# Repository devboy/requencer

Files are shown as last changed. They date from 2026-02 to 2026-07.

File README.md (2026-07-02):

# Requencer

A 4-track eurorack step sequencer built around **polymetric randomization** —
each track has independent gate, pitch, velocity and mod subtracks with their
own lengths and clock dividers, and a randomizer that regenerates a whole
track or a single layer at the press of a button. It replaces a live
setup of four sequencers plus utility modules with one hands-on module.

**[▶ Try it live](https://devboy.github.io/requencer/)** — the browser
preview is the real faceplate layout; everything works with mouse or touch.
See the **[manual](docs/manual.md)** for how to play it.

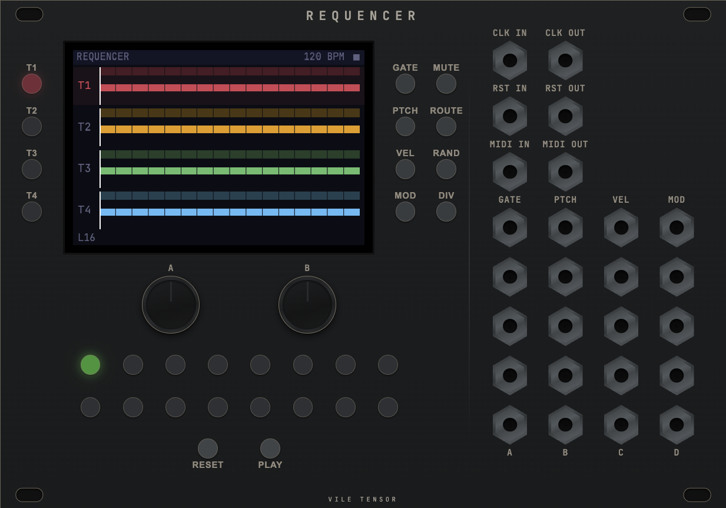
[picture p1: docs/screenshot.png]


## ⚡ Help wanted: hardware design review

The firmware, engine, and web preview are working and tested — but I'm a
software developer, not a hardware engineer, and this design is about to go
to manufacturing. **I'd be grateful for experienced eyes on the electronics
before I order boards.**

The module is a three-board stack behind a eurorack faceplate:

- **Control board** — buttons, encoders, jacks, LED drivers, shift
  registers, USB-C, SD card, MIDI in.
- **Main board** — RP2350 (PGA2350), DAC8568 CV outputs with op-amp output
  stages (1V/oct), eurorack power entry and regulators.
- Board-to-board via 2×16 shrouded headers.

**Review materials:**

- 📄 **Schematic review PDFs** (one page per subcircuit, net-label style) and
  the full **KiCad projects, gerbers, and STEP files** are attached to the
  latest [GitHub Release](https://github.com/devboy/requencer/releases).
- The design source is [atopile](https://atopile.io/) (`hardware/boards/elec/src/`),
  compiled to KiCad — the PDFs and KiCad files are what you want to look at
  if you don't read `.ato`.

Particularly unsure about: power entry & regulation, the DAC output stage
(1V/oct scaling/offset accuracy), the board-to-board pinout, and the USB-C /
SD / MIDI input circuits. Issues and PRs welcome.

## Features

- 4 tracks × 4 subtracks (gate / pitch / velocity / mod), each with
  independent step length (1–64) and clock divider — polymetric by default.
- Randomizer with per-track scale, root, range, density and velocity config;
  four gate algorithms (RAND / EUCL / SYNC / CLST); 8 factory presets plus
  user presets.
- Drift (per-subtrack stochastic mutation) and per-track transpose with
  scale quantization.
- Free output routing: any subtrack to any of the 4 output jacks.
- Internal, MIDI, or external clock; per-output MIDI channels.

Full documentation: **[docs/manual.md](docs/manual.md)** (also built into
the web app — the MANUAL button).

## Architecture

| Part | What it is |
|---|---|
| `crates/engine` | `no_std` pure Rust sequencer logic (runs in WASM and on the RP2350) |
| `crates/renderer` | `no_std` display rendering via embedded-graphics |
| `crates/web` | WASM bindings + Canvas2D target for the browser |
| `crates/firmware` | RP2350 firmware: SPI display, DACs, buttons/encoders |
| `web/` | TypeScript preview: Tone.js audio, Web MIDI, canvas faceplate UI |
| `hardware/` | atopile PCB projects (control + main + faceplate) and the build pipeline |

## Development

```bash
make dev      # Vite dev server (builds WASM first)
make test     # All tests: Rust + web + hardware scripts
make rust     # Test + lint + build firmware
make web      # Test + lint + build web bundle
make hardware # Full hardware pipeline (KiCad + FreeRouting required)
```

## License

- Code: [MIT](LICENSE)
- Hardware design (`hardware/`): [CERN-OHL-S v2](hardware/LICENSE) —
  strongly reciprocal open hardware licence.

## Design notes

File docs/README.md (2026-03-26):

# Requencer Docs

Design documents and research notes for Requencer development.

## Plans (Active)

- **[feature-roadmap.md](plans/2026-03-01-feature-roadmap.md)** — Feature tiers (all complete) + future/unscheduled items
- **[quality-audit.md](plans/2026-03-03-quality-audit.md)** — Performance baselines, coverage stats, refactoring opportunities
- **[firmware-implementation.md](plans/2026-03-06-firmware-implementation.md)** — RP2350 firmware roadmap (active development)
- **[persistence.md](plans/2026-03-06-persistence.md)** — Postcard serialization plan (web done, firmware SD card pending)
- **[rp2350-memory-constraints.md](plans/2026-03-06-rp2350-memory-constraints.md)** — Memory budget analysis for RP2350
- **[hardware-pipeline-remaining-todos.md](plans/2026-03-07-hardware-pipeline-remaining-todos.md)** — Pipeline status & known issues
- **[main-board-resize.md](plans/2026-03-12-main-board-resize.md)** — Shrink main board (partially implemented)
- **[parallel-placement-optimization.md](plans/2026-03-13-parallel-placement-optimization.md)** — 5-strategy parallel placement architecture
- **[pcb-stacking-restructure.md](plans/pcb-stacking-restructure.md)** — Three-board sandwich architecture (implemented)
- **[rust-engine-remaining-todos.md](plans/rust-engine-remaining-todos.md)** — Storage, cross-validation, firmware integration

## Superpowers Plans & Specs (Active)

- **[placement-strategy-refactor](superpowers/plans/2026-03-15-placement-strategy-refactor.md)** — BoardState toolkit architecture (implemented)
- **[wavefront-placement-design](superpowers/specs/2026-03-17-wavefront-placement-design.md)** — BFS wave placement strategy (implemented)
- **[display-replacement-design](superpowers/specs/2026-03-16-display-replacement-design.md)** — ST7796 32-pin FPC migration (implemented)
- **[placement-strategy-refactor-design](superpowers/specs/2026-03-15-placement-strategy-refactor-design.md)** — Config-driven placement design (implemented)

## Research (Active)

**Hardware reference:**
- [mechanical-standards](research/eurorack-mechanical-standards.md), [pcb-best-practices](research/eurorack-pcb-best-practices.md) — Eurorack specs
- [continuous-cv-outputs](research/continuous-cv-outputs.md) — CV output design for firmware
- [pcb-stacking](research/pcb-stacking.md) — Three-board sandwich depth budget & connectors
- [component-mounting-depths](research/component-mounting-depths.md) — Physical depth specs for panel-mounted parts
- [faceplate-connectors](research/faceplate-connectors.md) — USB-C & MicroSD front-panel placement
- [thermal-placement-analysis](research/thermal-placement-analysis.md) — Power dissipation & thermal gradients

**Design reference:**
- [sequencer-comparison](research/sequencer-comparison.md) — Competitor analysis
- [feature-ideas](research/feature-ideas.md) — Feature brainstorm with implementation status
- [3d-assembly-viewer](research/3d-assembly-viewer.md) — Three.js exploded view (planned)
- [3d-preview-rendering](research/3d-preview-rendering.md) — Studio-quality 3D rendering (aspirational)

**Audits:**
- [schematic-review-2026-03-16](research/schematic-review-2026-03-16.md) — Pre-production audit (all fixes applied)
- [pcb-placement-review](research/pcb-placement-review.md) — Component placement audit

**Sourcing:**
- [aliexpress-parts-sourcing](research/aliexpress-parts-sourcing.md) — THT parts sourcing (all ordered)
- [github-actions-autoroute-timeout](research/2026-03-07-github-actions-autoroute-timeout.md) — FreeRouting CI workarounds

## Archive

Completed feature plans, superseded research, and historical design decisions. See [`archive/`](archive/) directory.

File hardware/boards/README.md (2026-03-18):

# Requencer Hardware — Design Wiki

Multi-board eurorack sequencer module. Three-board sandwich stack: **faceplate** (front panel PCB) + **control board** (user-facing THT components) + **main board** (MCU, DACs, power).

## System Block Diagram

```
                    FACEPLATE (front panel PCB)
                    ┌─────────────────────────────────────┐
                    │  Display cutout    26× jack holes   │
                    │  36× button holes  2× encoder holes │
                    └──────────────┬──────────────────────┘
                                   │ mechanical mounting
                    CONTROL BOARD (user-facing THT)
                    ┌──────────────┴──────────────────────┐
                    │  FPC connector ──── ST7796 display   │
                    │  36× PB6149L buttons                 │
                    │  2× EC11E encoders                   │
                    │  26× WQP518MA jacks                  │
                    │  2× PJ366ST MIDI jacks               │
                    │  SD card (PJS008U)                    │
                    │  3× IS31FL3216A LED drivers (I2C)    │
                    │  5× 74HC165D shift registers         │
                    │  H11L1S MIDI optocoupler             │
                    └──────────────┬──────────────────────┘
                      2× ShroudedHeader2x16 (64 pins)
                    ┌──────────────┴──────────────────────┐
                    │  PGA2350 MCU (RP2350B, 48 GPIO)     │
                    │  2× DAC80508 (16-bit, 8-ch each)    │
                    │  5× OPA4171A quad op-amps            │
                    │  AMS1117-3.3 LDO                     │
                    │  USB-C (edge-mount)                   │
                    │  Eurorack power header               │
                    └─────────────────────────────────────┘
                    MAIN BOARD (MCU + analog + power)
```

## Documentation Index

### [Parts Catalog](elec/src/components/)

29 active components + [archived parts](elec/src/components/_archive/). Each part has a README with specs, sourcing info, and design rationale.

### Circuit Modules

Design documentation for each circuit block, including component value rationale and signal interfaces.

| Circuit | Board | Description |
|---|---|---|
| [dac-output](elec/src/circuits/dac-output/) | Main | 2× DAC80508 → 5× OPA4171A → 16 buffered CV/gate outputs |
| [power](elec/src/circuits/power/) | Main | Eurorack ±12V → +5V/+3.3V supply with protection |
| [mcu](elec/src/circuits/mcu/) | Main | PGA2350 (RP2350B) with SPI, I2C, GPIO routing |
| [input-protection](elec/src/circuits/input-protection/) | Main | Voltage divider + Schottky clamp for CV/clock inputs |
| [board-connector](elec/src/circuits/board-connector/) | Both | 2× 2×16 shrouded headers bridging control ↔ main |
| [led-driver](elec/src/circuits/led-driver/) | Control | 3× IS31FL3216A I2C constant-current LED drivers |
| [button-scan](elec/src/circuits/button-scan/) | Control | 5× 74HC165D shift register chain (34 buttons) |
| [midi](elec/src/circuits/midi/) | Control | TRS Type A MIDI IN/OUT (H11L1S optocoupler) |
| [io-jacks](elec/src/circuits/io-jacks/) | Control | 26× WQP518MA mono jacks |
| [display](elec/src/circuits/display/) | Control | ST7796 3.5" SPI TFT (32-pin FPC) — docs only |

### Board Top-Level Modules

| Board | Description |
|---|---|
| [Control](elec/src/boards/control/) | User-facing board: buttons, LEDs, encoders, jacks, display, SD, MIDI |
| [Main](elec/src/boards/main/) | Processing board: MCU, DACs, op-amps, power supply, USB-C |

### Source Structure

See [elec/src/README.md](elec/src/) for the circuit dependency graph and import structure.

## Build System

The hardware pipeline is managed by `Makefile` targets:

| Target | Action |
|---|---|
| `make hw-build` | Full pipeline: place → route → ground pours → faceplate → 3D → export |
| `make hw-place` | Component placement + export panel layout |
| `make hw-route` | FreeRouting autorouter |
| `make hw-3d` | 3D model generation + STEP/GLB export |
| `make hw-clean` | Remove build artifacts |

## Layout Source of Truth

KiCad PCB files are the layout authority. The web preview reads from:
- `scripts/placement/export_layout.py` → `web/src/panel-layout.json` (positions from PCB)
- `component-map.json` (UI metadata: dimensions, categories)

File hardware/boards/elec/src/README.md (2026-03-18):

# Requencer — Circuit Source

Atopile hardware description files organized into circuits, boards, and auto-generated validation.

## Directory Structure

```
elec/src/
├── system.ato              ← Auto-generated validation build (DO NOT EDIT)
├── parts/                  ← Auto-generated passives (Resistor, Capacitor instances)
├── components/             ← Custom part definitions (symbols, footprints, 3D models, docs)
├── circuits/               ← Reusable circuit modules
│   ├── board-connector/    ← 2×16 header interface between boards
│   ├── button-scan/        ← 5× 74HC165D shift register chain
│   ├── dac-output/         ← 2× DAC80508 + 5× OPA4171A output stage
│   ├── display/            ← ST7796 display documentation (no physical parts)
│   ├── input-protection/   ← Voltage divider + Schottky clamp
│   ├── io-jacks/           ← 26× WQP518MA mono jacks
│   ├── led-driver/         ← 3× IS31FL3216A I2C LED drivers
│   ├── mcu/                ← PGA2350 MCU block
│   ├── midi/               ← TRS Type A MIDI IN/OUT
│   └── power/              ← Eurorack power supply
└── boards/                 ← Top-level board modules
    ├── control/            ← Control board (user-facing THT)
    └── main/               ← Main board (MCU + analog + power)
```

## Dependency Graph

```
system.ato
├── boards/control/control.ato
│   ├── circuits/board-connector/  (BoardConnectorSocket)
│   ├── circuits/button-scan/      (ButtonScanner)
│   ├── circuits/led-driver/       (LEDDriverChain)
│   ├── circuits/io-jacks/         (IOJacks)
│   ├── circuits/midi/             (MIDIInterface)
│   └── parts: EC11E, B5819W, FPC_32P_05MM, PJS008U, 2N7002
│
└── boards/main/main.ato
    ├── circuits/board-connector/  (BoardConnectorInterface)
    ├── circuits/power/            (PowerSupply)
    ├── circuits/mcu/              (PGA2350_MCU)
    ├── circuits/dac-output/       (DACOutputStage)
    ├── circuits/input-protection/ (InputProtection)
    └── parts: 2N3904, PRTR5V0U2X, USB_C_Receptacle
```

## Build Entries

Defined in [`ato.yaml`](../../ato.yaml):

| Build | Entry Point | Purpose |
|---|---|---|
| `control` | `boards/control/control.ato:Control` | Control board netlist |
| `main` | `boards/main/main.ato:Main` | Main board netlist |
| `system` | `system.ato:System` | Cross-board validation (auto-generated) |

## Conventions

- **Import paths** are relative to each `.ato` file's location
- Parts imports use `../../components/<Part>/<Part>.ato` (from circuit/board dirs)
- Cross-module imports use `../../circuits/<name>/<name>.ato` (from board dirs)
- `system.ato` is regenerated by `scripts/build/gen_validation.py` — never edit manually
- `parts/` subdirectory contains auto-generated passive components (Resistor, Capacitor)

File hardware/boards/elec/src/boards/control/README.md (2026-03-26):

# Control Board

**Source:** [`control.ato`](./control.ato)
**Board:** Control (top board in the sandwich stack, user-facing)

## Purpose

The control board holds all user-facing components: 36 illuminated buttons (16 step + 4 track + 4 left-function + 4 subtrack + 4 right-function + 4 transport), 24 mono jacks, 2 rotary encoders, a 3.5" TFT display, a MicroSD card slot, and MIDI I/O jacks. It has no MCU or analog processing -- all intelligence lives on the main board. Every signal routes through two 2x16 board-to-board connectors (female sockets mating with male headers on the main board).

## Sub-Module Interconnection

```
                    Board Connector (2x16 socket, Header A + Header B)
                         |
         +---------------+------------------+------------------+
         |               |                  |                  |
    ButtonScanner    LEDDriverChain      IOJacks          MIDIInterface
    (74HC165 x5)    (IS31FL3216A x3)   (WQP518MA x24)    (TRS jacks)
         |               |
    36x PB6149L     LED cathode wiring
    (LED buttons)   (22 of 36 buttons have
                    LEDs, grouped by physical
                    location on PCB)

    Encoder A (EC11E)    Encoder B (EC11E)
         |                    |
    direct to connector  direct to connector

    FPC Connector ──── Display (ST7796 3.5" TFT)
    PJS008U ────────── MicroSD card slot
```

## Power Distribution

All power comes from the main board through the board connector. No regulators or power generation on this board.

| Rail | Source | Consumers | Decoupling |
|---|---|---|---|
| +3.3V | Main board AMS1117 regulator | Shift registers (ButtonScanner VCC), MIDI interface, LCD VDDA/VDDI, SD card VCC, IM pull-ups, reset RC | Per-consumer bypass caps |
| +5V | Eurorack bus via main board | LED driver anodes (led_vcc), LCD backlight (via 82 ohm) | 10uF bulk + 100nF HF near LED drivers |
| +12V / -12V | Eurorack bus via main board | Passed through connector but not directly consumed on control board | - |

## Physical Layout Notes

### THT Placement Constraints

All user-facing components are through-hole (THT), which constrains placement to a grid and requires clearance for:
- **WQP518MA jacks:** 9mm diameter body, need ~2mm clearance between adjacent jacks
- **PB6149L buttons:** 6.5mm square body with integral LED
- **EC11E encoders:** 12mm diameter body with 6mm shaft
- **FPC connector:** Bottom-mount, ribbon exits toward display cutout in faceplate
- **PJS008U MicroSD:** Vertical mount, protrudes ~2.6mm above panel surface through faceplate slot

### Component Grouping

Components are physically grouped for shortest trace routing:

- **LED driver A** (left side): drives step1-4, step9-12, t1-t4 (12 LEDs nearest to it)
- **LED driver B** (center): drives step5-8, step13-16, clr (9 LEDs)
- **LED driver C** (right): drives play (1 LED, 15 channels spare for future expansion)

### CV Input Filtering

100nF HF filter caps are placed on the control board side of each CV input (cv_a through cv_d) at the connector. These reduce crosstalk from adjacent digital signals on the board-to-board connector before the signals reach the main board's input protection circuits.

## Circuits on This Board

| Circuit | Instance | Role |
|---|---|---|
| `BoardConnectorSocket` | `connector` | Female 2x16 sockets (mates with main board headers) |
| `ButtonScanner` | `buttons` | 5x 74HC165 shift registers + 36x PB6149L illuminated buttons |
| `LEDDriverChain` | `leds` | 3x IS31FL3216A I2C LED drivers (16 channels each) |
| `IOJacks` | `jacks` | 24x WQP518MA mono jacks (pure breakout, no conditioning) |
| `MIDIInterface` | `midi` | MIDI IN/OUT/THRU TRS jacks with optocoupler |
| `EC11E` | `enc_a`, `enc_b` | Rotary encoders with push switch |
| `FPC_32P_05MM` | `lcd_fpc` | 32-pin FPC connector for display |
| `PJS008U` | `sd` | Vertical MicroSD card slot |
| Backlight driver | inline | 2N7002 MOSFET + gate resistors for LCD backlight PWM |
| LCD reset RC | inline | 10k + 100nF power-on reset circuit |
| LCD IM pull-ups | inline | 3x 10k pull-ups for 4-wire SPI mode |

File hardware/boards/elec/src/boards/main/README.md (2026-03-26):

# Main Board

**Source:** [`main.ato`](./main.ato)
**Board:** Main (bottom board in the sandwich stack)

## Purpose

The main board contains all processing and analog circuitry: the PGA2350 MCU, two DAC80508 16-bit DACs with op-amp output stages, input protection for 6 eurorack inputs, clock/reset output buffers, the power supply, and a USB-C port for firmware programming. It connects to the control board (which has all user-facing components) via two 2x16 shrouded headers.

## Analog Signal Chain

### DAC Outputs (16 channels)

```
MCU SPI1 (GP30/31) ──> DAC80508 x2 ──> OPA4171A op-amps x4 ──> 470ohm protection ──> Connector ──> Jacks
```

Four different output topologies serve different eurorack signal types:

| Output Type | Channels | Op-amp Config | Range | Resistor Values |
|---|---|---|---|---|
| Gate | 1-4 | Unity buffer (follower) | 0 to +5V | - |
| Pitch | 1-4 | Non-inv, gain=2, offset=-2V | -2V to +8V | Rf=Rg=10k (0.1%) |
| Velocity | 1-4 | Non-inv, gain=1.604 | 0 to +8V | Rf=6.04k, Rg=10k |
| Mod | 1-4 | Inverting, gain=-2, offset=+5V | +5V to -5V | Rin=10k, Rf=20k |

Pitch channels use 0.1% resistors for accurate 1V/oct tracking. Pitch feedback taps after the 470 ohm protection resistor so the op-amp compensates for voltage drop under load.

A 5th OPA4171A quad provides buffered reference voltages:
- **2V reference** (for pitch offset): 15k/10k divider from filtered 5V, buffered by ch1
- **1.667V reference** (for mod offset): 20k/10k divider from filtered 5V, buffered by ch2
- Ch3-4: spare, tied as GND followers to prevent oscillation

### DAC Power Filtering

The 5V rail is shared with LED drivers on the control board. A 10 ohm + 10uF RC filter (f_3dB ~1.6 kHz) isolates the DAC AVDD supply from LED PWM switching transients. Voltage drop at DAC quiescent current (~12mA) is only 0.12V.

### Input Protection (6 channels)

```
Jack (control board) ──> Connector ──> InputProtection (22k/10k divider + BAT54S clamp + filter cap) ──> MCU ADC
```

- CV inputs (4x): 100nF filter cap (f_3dB ~159 Hz)
- Clock/Reset inputs (2x): 10nF filter cap (f_3dB ~1.6 kHz) for fast edge response

### Clock/Reset Output Buffers (2 channels)

```
MCU GPIO ──> 1k base resistor ──> 2N3904 NPN (common-emitter) ──> 1k collector pull-up to 5V ──> Connector ──> Jack
```

These are inverting buffers. GPIO HIGH turns the transistor ON, pulling the output LOW. Firmware must drive the GPIO inverted relative to the desired output polarity.

## Power Distribution

```
Eurorack 16-pin header
  +12V ──> B5819W Schottky ──> v12p rail ──> Op-amp V+ / Connector
  -12V ──> B5819W Schottky ──> v12n rail ──> Op-amp V- / Connector
  +5V  ──> B5819W Schottky ──> v5v rail ──> AMS1117 / DAC AVDD / LED drivers (via connector) / MCU VB (via Schottky)
                                    |
                               AMS1117-3.3
                                    |
                               v3v3 rail ──> DAC VIO / Connector (LCD, shift regs, MIDI, etc.)
```

The AMS1117-3.3 LDO is fed from +5V (not +12V) to minimize power dissipation: (5-3.3) x 0.1A = 0.17W vs (12-3.3) x 0.1A = 0.87W from 12V.

All three eurorack rails have B5819W Schottky diodes for reverse polarity protection.

| Rail | Decoupling |
|---|---|
| +12V | 10uF bulk + 100nF HF per op-amp (x5) + 10uF shared bulk |
| -12V | 10uF bulk + 100nF HF per op-amp (x5) + 10uF shared bulk |
| +5V | 10uF bulk + 100nF HF (power supply) + 10uF + 22uF (AMS1117 in/out) |
| +3.3V | 22uF + 100nF (AMS1117 output) + 100nF per VIO (x2 DACs) |
| MCU VB | 10uF + 100nF (in mcu.ato) |
| MCU 3V3 | 10uF + 100nF (in mcu.ato) |
| DAC AVDD | 10uF + 100nF per DAC (on filtered rail) |

## USB-C Integration

USB-C is edge-mounted on the main board, accessible from the rack side. It is data-only (no VBUS power draw).

| Component | Value | Purpose |
|---|---|---|
| USB_C_Receptacle | - | Physical connector |
| Series resistors | 27 ohm x2 | Signal integrity on DP/DM (near MCU) |
| PRTR5V0U2X | - | ESD protection on data lines (at connector) |
| CC pull-downs | 5.1k x2 (1%) | Required by USB-C spec for device mode |

VBUS is intentionally left unconnected (not tied to GND, which would short the host's supply).

## Encoder Signal Conditioning

Encoder pull-ups and debounce caps are placed on the main board (near MCU) rather than the control board to free control board space:
- 10k pull-ups to 3.3V on all 6 encoder signals (A/B/SW for both encoders)
- 10nF debounce caps (tau = 10k x 10nF = 0.1ms) for RF filtering; real debounce is handled by the RP2350 PIO gray-code state machine

## Circuits on This Board

| Circuit | Instance | Role |
|---|---|---|
| `BoardConnectorInterface` | `connector` | Male 2x16 headers (mates with control board sockets) |
| `PowerSupply` | `power` | Eurorack 16-pin header, Schottky protection, AMS1117-3.3 LDO |
| `PGA2350_MCU` | `mcu` | RP2350B module with all GPIO assignments |
| `DACOutputStage` | `dac` | 2x DAC80508 + 5x OPA4171A + reference generation |
| `InputProtection` | `prot_cv_a/b/c/d`, `prot_clk`, `prot_rst` | 6x voltage divider + Schottky clamp circuits |
| 2N3904 NPN buffers | `q_clk`, `q_rst` | Clock/reset output level shifting (3.3V to 5V) |
| USB_C_Receptacle | `usb` | USB-C data port with ESD (PRTR5V0U2X) |
| SWD debug pads | `swd_clk`, `swd_dio` | Test points for pogo-pin debug access |

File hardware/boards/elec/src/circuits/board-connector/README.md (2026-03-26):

# Board-to-Board Connector

**Source:** [`board-connector.ato`](./board-connector.ato)
**Board:** Both (main board uses `BoardConnectorInterface` with male headers, control board uses `BoardConnectorSocket` with female sockets)

## Purpose

Defines the physical and logical interface between the main board and control board via two 2x16 shrouded headers (64 pins total). All signals crossing between boards are explicitly pinned here. The two modules (`BoardConnectorInterface` and `BoardConnectorSocket`) use different physical connectors (male headers vs female sockets). The socket's pin assignments have odd/even pairs swapped to compensate for KiCad's X-axis mirror when placing components on the B (back) side — this ensures signals connect correctly when the boards mate face-to-face in the sandwich stack.

## Design Decisions

### Signal Grouping: Header A (Digital + Power) vs Header B (Analog)

The two headers are separated by function to minimize crosstalk between digital and analog signals:

**Header A — Digital + Power (32 pins):**
- Power rails: GND (pins 1-2, 27-28, 32), +3.3V (pins 3-4), +5V (pins 5-6), +12V (pin 7), -12V (pin 8)
- SPI0 bus: MOSI/SCK/MISO/LCD_CS/LCD_DC/LCD_BL (pins 9-14)
- SD card: CS/CD (pins 15-16)
- MIDI: TX/RX (pins 17-18)
- Encoder B: A/B/SW (pins 19-21)
- Button scan: CLK/LATCH/DATA (pins 22-24)
- I2C: SDA/SCL (pins 25-26)
- Encoder A: A/B/SW (pins 29-31)

**Header B — Analog + Clock/Reset (32 pins):**
- Clock/Reset I/O: CLK_IN/OUT, RST_IN/OUT (pins 3-6)
- LCD reset: pin 7 (repurposed from spare GND)
- CV inputs: A/B/C/D (pins 8-11)
- DAC outputs grouped by type with GND separators:
  - Gate 1-4 (pins 13-16)
  - Pitch 1-4 (pins 18-21)
  - Velocity 1-4 (pins 23-26)
  - Mod 1-4 (pins 28-31)
- GND pins between each group (pins 1-2, 12, 17, 22, 27, 32) provide shielding between analog signal groups

### Power Pin Doubling

+3.3V and +5V each use two pins (doubled) to handle current capacity. The control board draws significant current on these rails: up to ~700mA on +5V (LED drivers) and ~100mA on +3.3V (shift registers, LCD, MIDI logic). Two pins per rail halve the contact resistance and provide redundancy.

### Connector Selection (ShroudedHeader2x16 / ShroudedSocket2x16)

2x16 shrouded headers (32 pins, 2.54mm pitch) were chosen for:
- **Keying:** Shrouded housing prevents reversed insertion
- **Pin count:** 32 pins per header, 64 total across two headers, accommodating all ~55 signals plus dedicated power and GND pins
- **Standard pitch:** 2.54mm is mechanically robust for board-to-board stacking and easy to hand-solder for prototyping

### GND Pin Placement

GND pins are strategically placed as shields:
- Header A: pins 1-2 (entry), 27-28 (spare/shield), 32 (termination)
- Header B: pins 1-2, 12, 17, 22, 27, 32 — one GND between each group of 4 analog outputs, providing return current paths and reducing crosstalk between DAC output groups

## Key Parts

| Part | Role | Datasheet |
|---|---|---|
| ShroudedHeader2x16 | Male 2x16 pin header on main board | Standard 2.54mm shrouded header |
| ShroudedSocket2x16 | Female 2x16 IDC socket on control board | Standard 2.54mm shrouded socket |

## Signal Interface

| Signal Group | Count | Direction (main -> control) | Description |
|---|---|---|---|
| Power (GND, 3V3, 5V, 12P, 12N) | 5 rails | main -> control | All power originates from main board power supply |
| SPI0 (MOSI, SCK, MISO, LCD_CS, LCD_DC, LCD_BL, LCD_RST) | 7 | main -> control | Display + SD card SPI bus and control |
| SD card (CS, CD) | 2 | CS: main->ctrl, CD: ctrl->main | SD chip select and card detect |
| Button scan (CLK, LATCH, DATA) | 3 | CLK/LATCH: main->ctrl, DATA: ctrl->main | 74HC165 shift register chain |
| I2C (SDA, SCL) | 2 | bidirectional | LED driver communication |
| MIDI (TX, RX) | 2 | main -> control | UART1 to MIDI jacks |
| Encoders (A_A/B/SW, B_A/B/SW) | 6 | control -> main | Quadrature + switch signals |
| Clock/Reset I/O | 4 | CLK_IN/RST_IN: ctrl->main, CLK_OUT/RST_OUT: main->ctrl | Raw eurorack levels (conditioned on main board) |
| CV inputs (A, B, C, D) | 4 | control -> main | Raw eurorack levels (conditioned on main board) |
| DAC outputs (gate/pitch/vel/mod x4) | 16 | main -> control | Buffered analog from DAC output stage |

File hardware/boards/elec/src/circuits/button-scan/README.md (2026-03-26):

# Button Scanner

**Source:** [`button-scan.ato`](./button-scan.ato)
**Board:** Control

## Purpose

Reads 36 pushbuttons using only 3 MCU GPIO pins via a daisy-chained shift register topology. Five 74HC165 parallel-in/serial-out shift registers capture the state of all buttons in a single 40-bit serial read (36 buttons + 4 spare).

## Design Decisions

### Shift Register Chain Topology

The five 74HC165 chips are daisy-chained: SR1 -> SR2 -> SR3 -> SR4 -> SR5. The MCU reads serial data from SR5.QH (the last register in the chain). A single scan requires:

1. Pulse SH/LD low to latch all 40 parallel inputs simultaneously
2. Clock out 40 bits on CLK, reading QH on each rising edge
3. First bit out is SR5.D7, last is SR1.D0

Only 3 GPIO pins are needed regardless of button count:

| GPIO | Signal | Function |
|---|---|---|
| GP8 | CLK | Shift clock (shared by all 5 SRs) |
| GP9 | SH/LD | Parallel load (shared by all 5 SRs) |
| GP10 | QH | Serial data out (from SR5 only) |

CLK_INH is tied to GND on all chips (clock always enabled). SR1.SER (serial input of the first register) is tied to GND since there is no preceding register.

### Physical Grouping Strategy

The registers are split into two physical groups matching the panel layout for short button-to-register traces:

**Left side (SR1-SR3):** placed near the left button cluster
| Register | Bits | Buttons |
|---|---|---|
| SR1 (D0-D7) | 0-7 | Step 1-8 |
| SR2 (D0-D7) | 8-15 | Step 9-16 |
| SR3 (D0-D7) | 16-23 | T1-T4, Settings, Back, Rand, Clr |

**Right side (SR4-SR5):** placed near the right button cluster
| Register | Bits | Buttons |
|---|---|---|
| SR4 (D0-D7) | 24-31 | Gate, Pitch, Vel, Mod, Pat, Mute, Route, Drift |
| SR5 (D0-D3) | 32-35 | Xpose, Var, Play, Reset |
| SR5 (D4-D7) | 36-39 | Spare (tied to VCC) |

This grouping minimizes trace length from each button to its shift register input, reducing susceptibility to noise pickup on the button lines.

### Pull-Up Array Sizing (10k x4 Resistor Networks)

Each shift register input has a 10k pull-up to VCC via ResArray4x0603 (4-resistor 0603 SMD arrays). The buttons connect between the SR input and GND, so:

- **Button released:** 10k pull-up holds input HIGH (logic 1)
- **Button pressed:** Button shorts input to GND (logic 0)

10k was chosen as a standard value that balances:
- **Low enough** to provide a solid logic high against noise pickup on the PCB traces from the buttons
- **High enough** to limit current draw when buttons are pressed (3.3V / 10k = 0.33mA per pressed button, negligible even with all 36 pressed)

Using 4x resistor arrays instead of discrete resistors reduces component count from 36 individual resistors to 9 array packages (two per SR for D0-D3 and D4-D7, with SR5 needing only one for D0-D3 since D4-D7 are tied to VCC directly).

The array pinout is "convex": R1 = pin1-pin8, R2 = pin2-pin7, R3 = pin3-pin6, R4 = pin4-pin5. One side of each resistor goes to VCC, the other to the SR input.

### Spare Inputs

SR5 inputs D4-D7 are tied directly to VCC (not through pull-ups). This provides a low-impedance logic high on unused inputs, preventing noise from being clocked into the data stream. These read as constant 1s and can be masked in firmware, or connected to future buttons by cutting the VCC tie and adding a pull-up + button.

### Scan Timing

At 3.3V, the 74HC165 supports clock frequencies up to ~20MHz. A practical scan rate of 1kHz (reading all 40 bits every 1ms) requires only 40 clock cycles per scan -- trivially fast. Even at a conservative 1MHz clock, a complete scan takes 40us, leaving 960us per scan cycle for other tasks.

### Button Hardware

All 36 buttons are PB6149L illuminated pushbuttons. Each button has two switch pins (SW1, SW2): SW1 connects to the shift register input, SW2 connects to GND. The LED inside each button is driven separately by the LED driver module.

## Key Parts

| Part | Role | Datasheet |
|---|---|---|
| 74HC165D | 8-bit parallel-in/serial-out shift register, SOIC-16 (x5) | [NXP 74HC165](https://www.nexperia.com/products/analog-logic-ics/asynchronous-interface-logic/shift-registers/74HC165D.html) |
| ResArray4x0603 | 10k x4 resistor array, 0603 SMD (x9) | -- |
| PB6149L | Illuminated pushbutton with integrated LED (x36) | -- |

## Signal Interface

| Signal | Direction | Description |
|---|---|---|
| clk | in | Shift clock from MCU (GP8) |
| latch | in | SH/LD parallel load from MCU (GP9, active low) |
| data_out | out | Serial data to MCU (GP10, from SR5.QH) |
| vcc | in | +3.3V supply |
| gnd | in | Common ground |

## References

- NXP 74HC165 datasheet: timing diagrams, max clock frequency at 3.3V, parallel load operation
- Application note: "Using 74HC165 Shift Registers for Button Matrices" -- standard parallel load + serial readout pattern

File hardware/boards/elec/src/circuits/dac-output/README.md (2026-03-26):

# DAC Output Stage

**Source:** [`dac-output.ato`](./dac-output.ato)
**Board:** Main

## Purpose

Converts 16 digital channels from two DAC80508 16-bit DACs into buffered analog CV outputs for a 4-track eurorack sequencer. Each track gets four output types: gate, pitch, velocity, and modulation, each with a different gain/offset topology tailored to eurorack voltage conventions.

## Design Decisions

### Channel Mapping and DAC Assignment

Two DAC80508 chips provide 8 channels each, split by output type:

| DAC | Channels | Output Type | Topology |
|-----|---|---|---|
| DAC1 | 0-3 | Gate 1-4 | Unity buffer (0-5V) |
| DAC1 | 4-7 | Pitch 1-4 | Non-inverting, gain=2, offset=-2V (-2V to +8V) |
| DAC2 | 0-3 | Velocity 1-4 | Non-inverting, gain=1.604 (0-8V) |
| DAC2 | 4-7 | Mod 1-4 | Inverting, gain=-2, offset=+5V (+5V to -5V) |

### AVDD Filter (10R + 10uF Low-Pass)

The +5V rail is shared with IS31FL3216A LED drivers (22 channels, ~23mA max each). A 10R + 10uF RC filter (f_3dB ~ 1.6kHz) isolates the DAC analog supply from switching transients. Voltage drop at DAC quiescent current (~12mA) is only 10R x 12mA = 0.12V, negligible for a 5V rail.

### SPI Bus Assignment

Both DACs share SPI1 (GP30 SCK, GP31 MOSI) with individual chip-select lines. This is a dedicated bus with no contention from the display or SD card. The DAC80508 VIO pin is tied to 3.3V, matching MCU GPIO levels directly -- no level shifter needed.

**SPI clock: 37.5 MHz (150 MHz / 4).** The DAC80508 datasheet rates SCLK at 50 MHz absolute maximum. Running at 37.5 MHz gives 25% margin for trace ringing and overshoot, with negligible impact on throughput: a full 16-channel update (2 DACs x 8 channels x 24-bit frames) takes ~10.2 us at 37.5 MHz vs ~7.7 us at 50 MHz, both well within the 250 us CV render period (4 kHz update rate). The extra 2.5 us is <1% of the render budget.

### Gate Outputs: Unity Buffer

`Vout = Vdac` (0-5V range)

Simple voltage follower on opamp1. DAC output drives the non-inverting input; output feeds back to the inverting input. No gain resistors needed.

### Pitch Outputs: Non-Inverting Gain=2 with -2V Offset

```
Vout = (1 + Rf/Rg) * Vdac - (Rf/Rg) * Vref_2V
Vout = 2 * Vdac - 2V
```

- Rf = Rg = 10k (0.1% tolerance)
- Vref = 2V (buffered voltage follower from 5V divider: 5V x 10k/(15k+10k))
- At Vdac=0V: Vout = -2V. At Vdac=5V: Vout = +8V. This gives a 10V span covering 10 octaves of 1V/oct pitch CV.

**Why 0.1% resistors for pitch:** 1V/oct pitch requires that each semitone (1/12V ~ 83.3mV) be accurate. A 1% resistor mismatch in the gain network introduces up to ~50mV error (half a semitone). 0.1% resistors reduce this to ~5mV, well within tuning tolerance. The reference divider resistors (15k/10k) are also 0.1% to keep the 2V offset accurate.

**Feedback taps after the protection resistor:** The feedback path connects to the output side of the 470R protection resistor (at the `pitch1-4` signal node), not directly at the op-amp output. This means the op-amp compensates for any voltage drop across the protection resistor under load, preserving accurate 1V/oct tracking regardless of load impedance.

### Velocity Outputs: Non-Inverting Gain=1.604

```
Vout = (1 + Rf/Rg) * Vin = (1 + 6.04k/10k) * Vin = 1.604 * Vin
```

- Rf = 6.04k, Rg = 10k (both 1%)
- At Vin=5V: Vout = 8.02V. Provides a 0-8V velocity range, common for eurorack.

### Mod Outputs: Inverting Gain=-2 with +5V Offset

```
Vout = -(Rf/Rin) * Vdac + (1 + Rf/Rin) * Vref_mod
Vout = -2 * Vdac + 3 * 1.667V = -2 * Vdac + 5V
```

- Rf = 20k, Rin = 10k (both 1%)
- Vref_mod = 1.667V (buffered from 5V divider: 5V x 10k/(20k+10k))
- At Vdac=0V: +5V. At Vdac=5V: -5V. Bipolar modulation output.

### Reference Voltage Generation

Both reference voltages are derived from the filtered 5V rail via resistor dividers, then buffered through dedicated voltage follower channels on opamp5:

| Reference | Divider | Value | Buffer | Tolerance |
|---|---|---|---|---|
| Pitch offset | 15k/10k from 5V | 2.000V | opamp5 ch1 | 0.1% resistors |
| Mod offset | 20k/10k from 5V | 1.667V | opamp5 ch2 | 1% resistors |

Each divider has a 1uF filter cap to GND. Buffering eliminates loading effects from the op-amp summing networks. Opamp5 channels 3-4 are spare, configured as GND-referenced followers to prevent floating-input oscillation.

### Output Protection Resistors (470R)

All 16 outputs have a 470R series protection resistor. This limits current if an output is shorted or connected to a mismatched voltage. The value was reduced from 1k to minimize voltage divider effect with load impedance: at 470R + 10k load, the voltage drop is 4.5% (vs 9% with 1k).

### Decoupling Strategy

- **DAC AVDD:** 100nF HF + 10uF bulk per chip, on the filtered rail
- **DAC VREF:** 10uF + 100nF per chip (per DAC80508 datasheet section 9.3.1)
- **DAC VIO:** 100nF per chip
- **Op-amp power:** 100nF per chip per rail (+12V and -12V), plus 10uF bulk shared across the cluster

## Key Parts

| Part | Role | Datasheet |
|---|---|---|
| DAC80508ZRTER | 16-bit 8-channel voltage-output DAC (x2) | [TI DAC80508](https://www.ti.com/product/DAC80508) |
| OPA4171AIPWR | Quad rail-to-rail op-amp, low offset (x5) | [TI OPA4171](https://www.ti.com/product/OPA4171) |

## Signal Interface

| Signal | Direction | Description |
|---|---|---|
| spi_mosi | in | SPI data (GP31, shared by both DACs) |
| spi_sck | in | SPI clock (GP30, shared by both DACs) |
| dac1_cs | in | DAC1 chip select (active low) |
| dac2_cs | in | DAC2 chip select (active low) |
| avdd | in | +5V analog supply (pre-filter) |
| v3v3 | in | +3.3V for DAC VIO logic level |
| v12p | in | +12V op-amp positive supply |
| v12n | in | -12V op-amp negative supply |
| gnd | in | Common ground |
| gate1-4 | out | Gate CV outputs (0-5V) |
| pitch1-4 | out | Pitch CV outputs (-2V to +8V, 1V/oct) |
| vel1-4 | out | Velocity CV outputs (0-8V) |
| mod1-4 | out | Modulation CV outputs (+5V to -5V, bipolar) |

## References

- DAC80508 datasheet, section 9.3.1: VREF decoupling requirements
- TI app note SLAU525: "DAC80508 Application Reference"
- OPA4171 datasheet: rail-to-rail output, 36V supply range, low offset voltage

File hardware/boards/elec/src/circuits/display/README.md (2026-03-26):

# Display

**Source:** [`display.ato`](./display.ato)
**Board:** N/A (documentation only -- all circuits live in [`control.ato`](../../boards/control/control.ato))

## Purpose

This file documents the display specifications and FPC pinout. It contains no physical parts or circuit definitions. All display-related circuits (FPC connector, backlight MOSFET, reset RC, IM pull-ups, bypass caps) are instantiated directly in `control.ato` on the control board.

## Photos

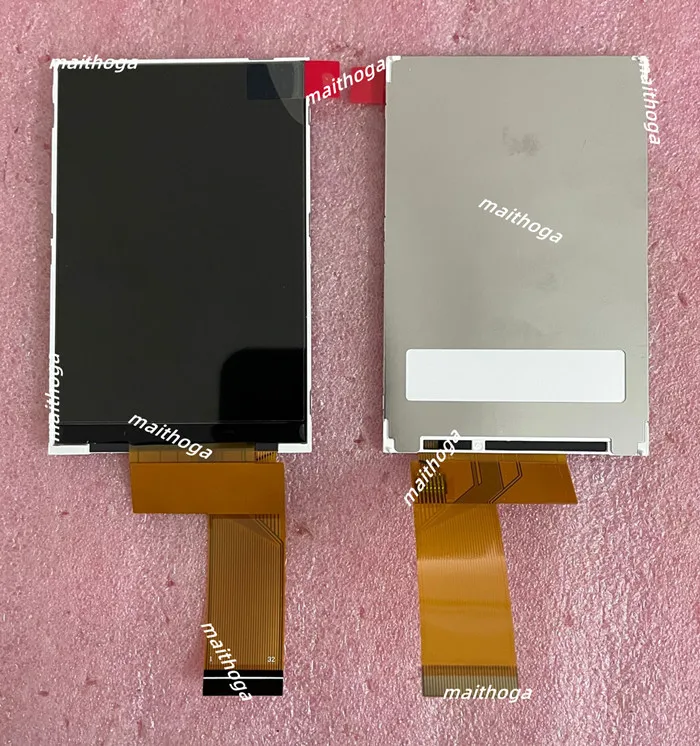
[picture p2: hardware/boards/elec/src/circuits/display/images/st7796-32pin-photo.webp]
ST7796 32-pin bare panel


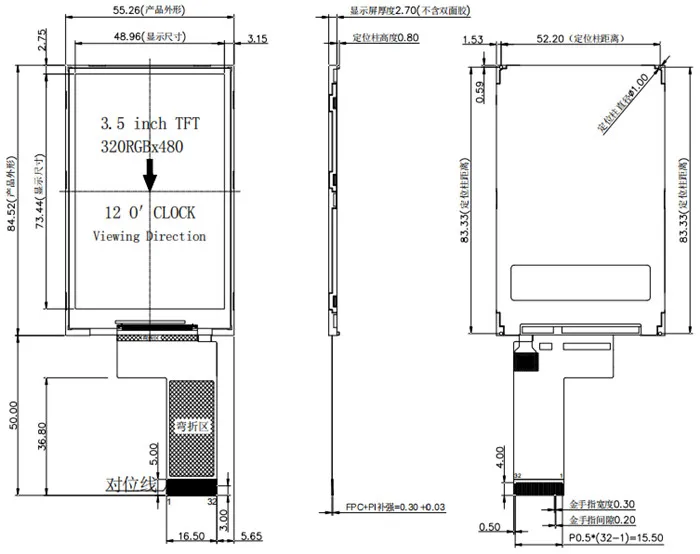
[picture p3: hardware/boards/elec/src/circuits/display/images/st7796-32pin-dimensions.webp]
Dimensions — front view


## Display Specifications

| Parameter | Value |
|---|---|
| Controller | ST7796 |
| Size | 3.5" diagonal |
| Resolution | 480 x 320 pixels |
| Glass dimensions | 55.26 x 84.52 mm (portrait); mounted landscape |
| Active area | 73.44 x 48.96 mm |
| Thickness | 4.13 mm max |
| Interface | 4-wire SPI (IM2=IM1=IM0=1 via 10k pull-ups) |
| FPC | 32-pin, 0.5mm pitch, exits right edge (landscape orientation) |
| FPC Connector | JUSHUO AFC01-S32FCA-00 (LCSC C262672) |
| Backlight | Single LED, anode to 5V via 82 ohm (~18mA), cathode switched by 2N7002 MOSFET |
| Source | Generic ST7796 bare panel (maithoga, AliExpress) |

## FPC Pinout

32-pin FPC pinout

| Pin | Signal | Connection |
|-----|---|---|
| 1 | GND | Ground |
| 2 | VDDA | 3.3V (analog supply) |
| 3 | VDDI | 3.3V (I/O supply) |
| 4 | TE | Tearing effect -- not connected |
| 5 | CS | LCD chip select (from MCU GP1) |
| 6 | DC | Data/command select (from MCU GP7) |
| 7 | SCK | SPI clock (from MCU GP2) |
| 8 | RDX | Read strobe -- tied to 3.3V (deasserted) |
| 9 | MOSI | SPI data in (from MCU GP3) |
| 10 | MISO | SPI data out (to MCU GP0) |
| 11-26 | DB0-DB15 | Parallel data bus -- unused in SPI mode, floating |
| 27 | RESET | Active-low reset (RC power-on + GPIO control) |
| 28 | IM2 | Interface mode bit 2 -- 10k pull-up to 3.3V |
| 29 | IM1 | Interface mode bit 1 -- 10k pull-up to 3.3V |
| 30 | IM0 | Interface mode bit 0 -- 10k pull-up to 3.3V |
| 31 | LED-A | Backlight anode (5V via 82 ohm) |
| 32 | LED-K | Backlight cathode (switched by 2N7002 MOSFET) |

## Signal Path

```
MCU (main board) --[SPI0 + control]--> Board Connector ---> Control Board ---> FPC Connector ---> Display Glass
     GP1 (CS)                              Header A pin 12
     GP2 (SCK)                             Header A pin 10
     GP3 (MOSI)                            Header A pin 9
     GP0 (MISO)                            Header A pin 11
     GP7 (DC)                              Header A pin 13
     GP5 (BL PWM)                          Header A pin 14
     GP22 (RST)                            Header B pin 7
```

## Circuits on Control Board

The following display support circuits are defined in `control.ato`:

- **FPC connector** (FPC_32P_05MM): Physical 32-pin 0.5mm FPC connector
- **Reset RC** (10k + 100nF, tau=1ms): Ensures reset is asserted at power-on before MCU boots; GPIO can pull low for runtime reset
- **IM pull-ups** (3x 10k to 3.3V): Configure IM2/IM1/IM0 all high for 4-wire SPI mode
- **Backlight driver** (2N7002 N-MOSFET + 100 ohm gate + 100k gate pull-down): PWM dimming via LCD_BL signal; 82 ohm current limit gives ~18mA (conservative for eurorack viewing distance)
- **Bypass caps** (2x 100nF): One each for VDDA and VDDI supply domains

## Interface Mode Selection

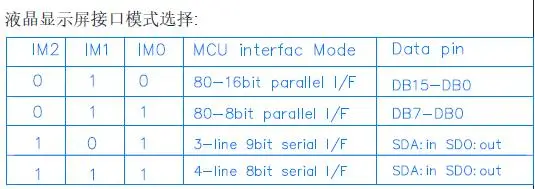
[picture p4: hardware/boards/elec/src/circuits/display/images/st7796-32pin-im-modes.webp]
IM pin mode table


IM2=IM1=IM0=1 (all high via 10k pull-ups) selects 4-wire SPI mode.

## Additional Reference Images

| Image | Description |
|---|---|
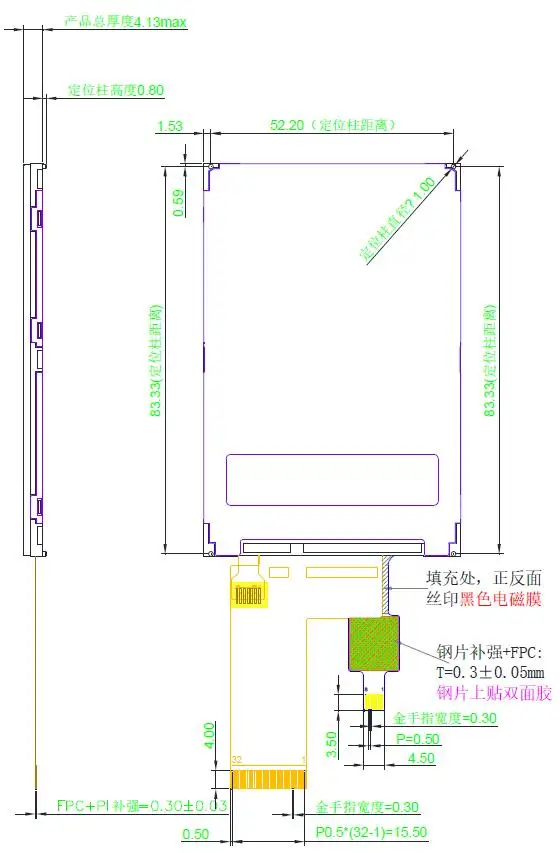
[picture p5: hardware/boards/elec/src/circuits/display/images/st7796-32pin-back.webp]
Back view
|  | Back of panel showing FPC |
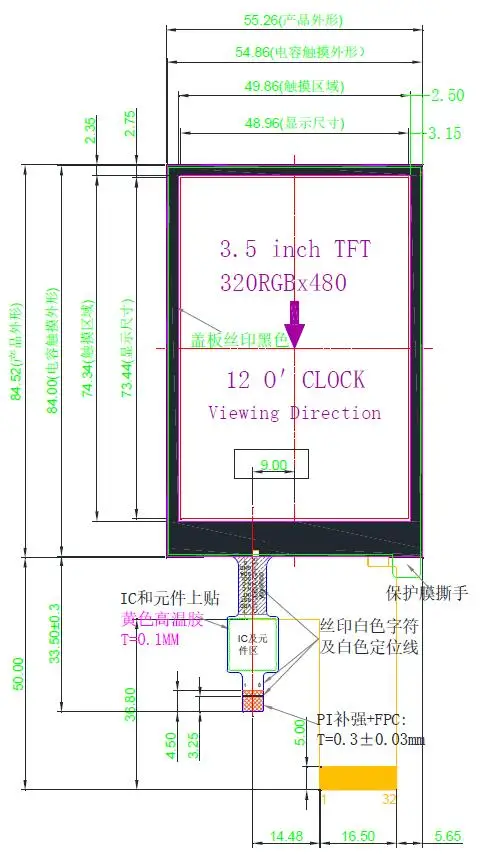
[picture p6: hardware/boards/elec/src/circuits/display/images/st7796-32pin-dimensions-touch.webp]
Dimensions with touch
|  | Dimensions including touch overlay variant |
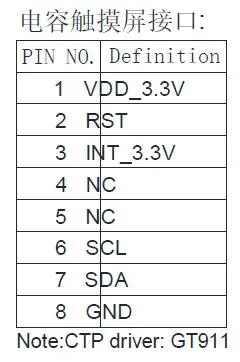
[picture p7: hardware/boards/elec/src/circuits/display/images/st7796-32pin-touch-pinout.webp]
Touch FPC pinout
|  | 8-pin touch FPC (GT911 I2C, not used) |
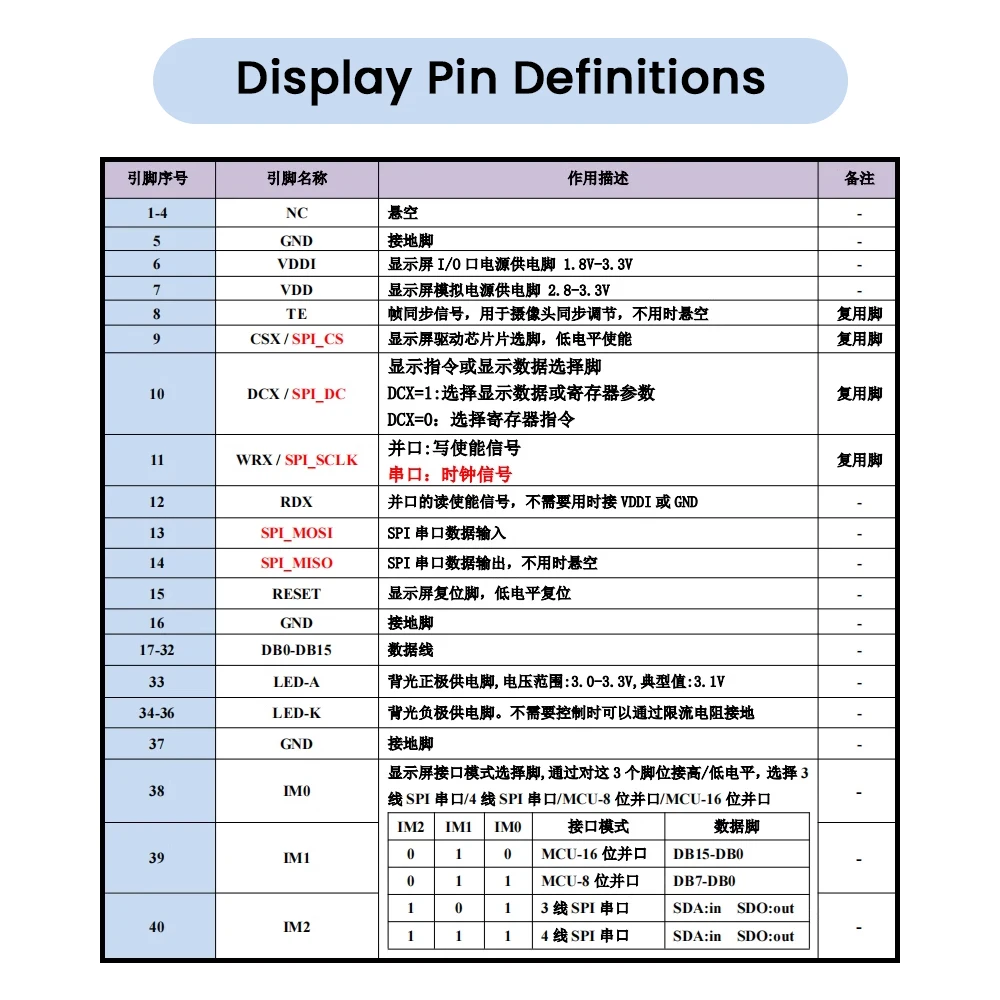
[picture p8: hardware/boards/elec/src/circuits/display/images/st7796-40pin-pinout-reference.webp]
40-pin reference
|  | 40-pin variant pinout for reference |

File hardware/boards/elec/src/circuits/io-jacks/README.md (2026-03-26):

# I/O Jacks

**Source:** [`io-jacks.ato`](./io-jacks.ato)
**Board:** Control

## Purpose

Breakout module for all 24 mono 3.5mm jacks on the Requencer panel (excluding the 2 MIDI jacks handled in `midi.ato`). This is a pure wiring module with no signal conditioning -- jacks connect directly to board connector signals. All voltage scaling, clamping, and buffering is performed on the main board.

## Design Decisions

### Jack Type (WQP518MA)

The WQP518MA is a standard Thonkiconn-compatible 3.5mm mono jack widely used in eurorack DIY. It is a PCB-mount THT (through-hole) part with two pins: TIP (signal) and SLEEVE (ground). No switch contacts are used.

### Wiring Convention

All jacks follow the same pattern:
- **TIP** connects to the signal line (routed through the board connector to/from the main board)
- **SLEEVE** connects to GND

No series resistors, filter caps, or protection components are on the control board side. This keeps the control board simple (pure breakout) and centralizes all analog conditioning on the main board near the MCU and DACs.

### Signal Flow

**Outputs (16 jacks):** DAC output stage on main board produces buffered analog signals with 470 ohm protection resistors. These signals cross the board connector (Header B) and arrive at the jack tips on the control board.

**CV Inputs (4 jacks):** Raw eurorack signals (0-10V) from jack tips pass through the board connector (Header B) to the main board, where `InputProtection` circuits scale and clamp them for the RP2350 ADC.

**Clock/Reset Inputs (2 jacks):** Same path as CV inputs, but with 10nF filter caps instead of 100nF for faster edge response.

**Clock/Reset Outputs (2 jacks):** NPN buffer circuits on the main board produce 5V gate signals that cross the board connector to these jacks.

## Key Parts

| Part | Role | Datasheet |
|---|---|---|
| WQP518MA (x24) | 3.5mm mono jack, PCB-mount THT | [Thonkiconn WQP518MA](https://www.thonk.co.uk/shop/thonkiconn/) |

## Signal Interface

| Signal | Direction | Description |
|---|---|---|
| `gate1-4` | in (from main) | Gate output signals (0-5V) |
| `pitch1-4` | in (from main) | Pitch CV output (-2V to +8V, 1V/oct) |
| `vel1-4` | in (from main) | Velocity output (0-8V) |
| `mod1-4` | in (from main) | Mod output (+5V to -5V, bipolar) |
| `clk_in_gpio` | out (to main) | Raw clock input (0-10V eurorack gate) |
| `rst_in_gpio` | out (to main) | Raw reset input (0-10V eurorack gate) |
| `clk_out_gpio` | in (from main) | Buffered 5V clock output |
| `rst_out_gpio` | in (from main) | Buffered 5V reset output |
| `cv_a/b/c/d_gpio` | out (to main) | Raw CV inputs (0-10V) |
| `gnd` | power | Ground bus for all jack sleeves |

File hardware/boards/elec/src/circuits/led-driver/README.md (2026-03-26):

# LED Driver Chain

**Source:** [`led-driver.ato`](./led-driver.ato)
**Board:** Control

## Purpose

Drives the LEDs inside 22 illuminated pushbuttons using three IS31FL3216A I2C constant-current LED driver ICs. Each chip provides 16 channels with 8-bit PWM brightness control. The three chips are distributed across the panel to minimize cathode trace lengths to their respective button groups.

## Design Decisions

### Chip Distribution Strategy

The three IS31FL3216A chips are physically placed near the button groups they drive, keeping LED cathode traces short (important for consistent brightness and reduced EMI from PWM switching):

| Chip | Position | Button Group | Channels Used |
|---|---|---|---|
| led_a | Left side | Step 1-4, Step 9-12, T1-T4 | 12 of 16 |
| led_b | Right-center | Step 5-8, Step 13-16, Clr | 9 of 16 |
| led_c | Right side | Play + future expansion | ~2 of 16 |

This leaves 26 spare channels across the three chips for future LED additions without new ICs.

### I2C Addressing Scheme (AD Pin)

The IS31FL3216A uses a single AD pin to select from four addresses based on what it is connected to:

| Chip | AD Connection | Address | Routing Note |
|---|---|---|---|
| led_a | GND | 0x68 | AD pin to GND plane, trivial |
| led_b | VCC | 0x6B | Pins AD(25) and VCC(26) are adjacent on the QFN package -- zero-length trace |
| led_c | SDA | 0x6A | Pins SDA(24) and AD(25) are adjacent on the QFN package -- zero-length trace |

The address assignments were chosen to exploit the QFN-28 pin ordering (SDB-SCL-SDA-AD-VCC are consecutive pins 22-26 on the top edge). Connecting AD to an adjacent pin avoids routing a separate address trace across the board.

### R_EXT Current Calculation

The R_EXT resistor sets the maximum output sink current per channel. From the IS31FL3216A datasheet (page 14, Formula 3):

```
I_LED [mA] = (1.2 / R_EXT [kΩ]) × 1400
I_LED = (1.2 / 100) × 1400 = 16.8mA per channel
```

R_EXT = 100kΩ (1% tolerance, datasheet recommended minimum) on each chip. The CS bits in the Lighting Effect Register (03h) can scale I_LED by ×0.25 to ×2.0 for higher brightness. The actual LED current is further modulated by the 8-bit PWM register (0-255). Typical LED button operation will use lower duty cycles for dimming.

**Note:** The IS31FL3236A (predecessor, now archived) uses a different formula where R_EXT = 3.3kΩ gives ~23mA. The IS31FL3216A formula is different — do not use IS31FL3236A values.

### QFN-28 Thermal Pad

All three chips have their exposed thermal pad (PAD) connected to GND. This provides both the required electrical ground connection and thermal dissipation path through the PCB ground plane. The IS31FL3216A dissipates modest power (max ~16 channels × 16.8mA × ~0.5V_sat = ~134mW per chip), but the thermal pad connection is still required per datasheet for reliable operation.

### Power Architecture

The IS31FL3216A VCC (logic supply) runs from +3.3V, while the LED anodes connect to +5V via the `led_vcc` signal. This split allows the LEDs to operate at higher forward voltage (typical LED Vf = 2-3V) with more current headroom, while the I2C logic stays at MCU voltage levels.

### SDB (Shutdown Bar) Pin

All three chips have SDB tied to VCC (always enabled). Software can disable individual channels or enter standby via I2C commands, so hardware shutdown control is not needed.

### CLK Pin (Audio Cascade)

The CLK pin is for audio synchronization cascading between multiple IS31FL3216A chips. This feature is unused here, so CLK is tied to GND on all chips.

### C_FILT (Audio Filter)

The C_FILT pin connects to an internal audio filter for sound-reactive LED modes. Unused here, but a 100nF cap to GND is placed on each chip for noise filtering per datasheet recommendation.

### Decoupling

- 100nF per chip on 3.3V VCC
- 10uF bulk on 3.3V VCC (shared)
- 10uF bulk + 100nF HF on 5V LED anode supply

## Key Parts

| Part | Role | Datasheet |
|---|---|---|
| IS31FL3216A | 16-channel I2C LED driver, QFN-28, 8-bit PWM (x3) | [ISSI IS31FL3216A](https://www.lumissil.com/assets/pdf/core/IS31FL3216A_DS.pdf) |

## Signal Interface

| Signal | Direction | Description |
|---|---|---|
| sda | bidir | I2C data (shared bus with MCU) |
| scl | in | I2C clock (shared bus with MCU) |
| vcc | in | +3.3V logic supply |
| v5v | in | +5V LED anode supply |
| gnd | in | Common ground |

Note: LED cathode connections (IS31FL3216A output pins to button LED cathodes) are wired in `control.ato`, not in this module, because they cross between the button-scan module (which owns the PB6149L button instances) and this module.

## References

- IS31FL3216A datasheet: R_EXT formula (page 14, Formula 3), I2C address table, QFN-28 pin assignments
- IS31FL3216A application circuit: recommended decoupling, SDB/CLK/C_FILT pin handling

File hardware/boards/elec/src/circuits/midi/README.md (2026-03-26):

# MIDI Interface

**Source:** [`midi.ato`](./midi.ato)
**Board:** Control

## Purpose

Provides MIDI IN and MIDI OUT via TRS Type A (stereo 3.5mm) jacks, following the MIDI Manufacturers Association CA-033 specification for 3.3V operation. Uses an H11L1S optocoupler for galvanic isolation on the input side.

## Design Decisions

### TRS Type A Pinout (CA-033 Spec)

The CA-033 specification defines TRS Type A wiring for MIDI over 3.5mm jacks:

| TRS Pin | MIDI Pin | Function |
|---|---|---|
| Tip | Pin 5 | Data (source/sink) |
| Ring | Pin 4 | Current source (+V) |
| Sleeve | Pin 2 | Shield/GND |

Both jacks use PJ366ST stereo 3.5mm connectors. Mono jacks will not work -- the ring connection is required for the MIDI current loop.

### MIDI OUT: 3.3V Transmitter (CA-033 Compliant)

The CA-033 spec defines reduced resistor values for 3.3V transmitters (vs the traditional 5V 220R/220R circuit):

```
TX path:  UART_TX → 10R → TIP
Ring path: +3.3V → 33R → RING
```

Current calculation when receiver pulls current (opto LED Vf ~ 1.7V):
```
I = (3.3V - 1.7V) / (33R + 10R + 220R_receiver) = 1.6V / 263R = ~6mA
```

This exceeds the MIDI spec minimum of 5mA. The reduced resistor values (10R + 33R instead of 220R + 220R) compensate for the lower supply voltage.

### MIDI IN: H11L1S Optocoupler (vs 6N138)

The H11L1S was chosen over the traditional 6N138 for several reasons:

1. **Built-in Schmitt trigger output:** The H11L1S integrates a Schmitt trigger on the phototransistor output, producing clean digital edges without external components. The 6N138 requires a base resistor and careful biasing for sharp transitions.
2. **Fewer external components:** No base resistor, no pull-down resistor on the emitter. Just a single pull-up on the open-collector output.
3. **SOP-6 SMD package:** Smaller footprint than the 6N138 DIP-8 or even its SMD variants.
4. **Logic-compatible output:** Direct 3.3V logic levels with the 1k pull-up.

### MIDI IN Circuit

```
Ring (source) → opto ANODE
Tip (data)    → 220R → opto CATHODE
```

The 220R input resistor limits current through the optocoupler LED. The protection diode (B5819W Schottky, reverse-biased across the opto LED) clamps reverse voltage when the sender drives the line high, protecting the optocoupler from damage.

The H11L1S output is open-collector with a Schmitt trigger. A 1k pull-up to 3.3V provides the logic high level. When MIDI data arrives (current flows through opto LED), the output pulls low, producing the inverted UART signal expected by the MCU's UART RX.

### Bypass Capacitor

A 100nF capacitor on the optocoupler VCC pin (5V rail) filters high-frequency noise from the supply.

## Key Parts

| Part | Role | Datasheet |
|---|---|---|
| H11L1S | Optocoupler with Schmitt trigger output, SOP-6 | [Vishay H11L1S](https://www.vishay.com/docs/81018/h11l1.pdf) |
| B5819W | Schottky diode, reverse protection across opto LED | [B5819W datasheet](https://www.diodes.com/assets/Datasheets/ds30146.pdf) |
| PJ366ST | 3.5mm stereo TRS jack (x2, MIDI IN + MIDI OUT) | -- |

## Signal Interface

| Signal | Direction | Description |
|---|---|---|
| uart_tx | in | UART1 TX from MCU (GP20) |
| uart_rx | out | UART1 RX to MCU (GP21), active-low via opto |
| vcc | in | +3.3V supply (MIDI OUT transmitter + output pull-up) |
| v5v | in | +5V supply (H11L1S optocoupler VCC, min 4.5V per datasheet) |
| gnd | in | Common ground |

## References

- MIDI Manufacturers Association CA-033: "TRS Adapter for MIDI 1.0" (Type A pinout, 3.3V transmitter resistor values)
- Vishay H11L1S datasheet: Schmitt trigger thresholds, CTR, recommended circuits
- MIDI 1.0 Electrical Specification: minimum 5mA loop current

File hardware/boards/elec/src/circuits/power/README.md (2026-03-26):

# Power Supply

**Source:** [`power.ato`](./power.ato)
**Board:** Main

## Purpose

Converts eurorack bus power (+12V, -12V, +5V) into the regulated rails needed by the system. Provides reverse polarity protection on all three rails and generates a regulated +3.3V supply from the +5V bus rail.

## Design Decisions

### Reverse Polarity Protection (B5819W Schottky Diodes)

All three power rails (+12V, -12V, +5V) are protected by B5819W Schottky diodes in series. If the eurorack power cable is inserted backwards, the diodes block reverse current. Schottky diodes are chosen for their low forward voltage drop (~0.3-0.4V), minimizing power loss compared to standard silicon diodes (~0.7V).

- **+12V:** Anode from header pins POS12V_1/2, cathode to protected v12p rail.
- **-12V:** Cathode from header pins NEG12V_1/2, anode to protected v12n rail (reversed orientation for negative rail).
- **+5V:** Anode from header pins POS5V_1/2, cathode to protected v5v rail.

### Why 5V to 3.3V (Not 12V to 3.3V)

The AMS1117-3.3 LDO is fed from the +5V rail, not +12V. The thermal math makes this clear:

| Source | Dropout | Power @ 100mA |
|---|---|---|
| 12V | 12V - 3.3V = 8.7V | 8.7V x 0.1A = **0.87W** |
| 5V | 5V - 3.3V = 1.7V | 1.7V x 0.1A = **0.17W** |

Feeding from 5V dissipates 5x less heat. The AMS1117 in an SOT-223 package has limited thermal dissipation; 0.87W would require careful thermal management, while 0.17W is trivial.

The +5V bus rail is available on the eurorack 16-pin header (pins POS5V_1/2). Most eurorack power supplies provide +5V.

### AMS1117-3.3 LDO Regulator

The AMS1117 requires a minimum 10uF capacitor on the input and a minimum 22uF capacitor on the output for regulator loop stability (per datasheet). The design provides:

- **Input:** 10uF bulk (c_3v3_in), plus the shared 5V rail decoupling
- **Output:** 22uF bulk (c_3v3_out) + 100nF HF (c_3v3_out_hf)

The TAB pin is connected to VOUT (not GND), following the AMS1117 datasheet recommendation. This is a common gotcha -- some LDOs have TAB=GND, but the AMS1117 TAB is electrically connected to the output.

### 3.3V Rail Load Budget

The board 3.3V rail powers shift registers, LCD, MIDI interface, and input protection. The PGA2350 MCU has its own internal 3.3V regulator (300mA) fed from +5V via a separate Schottky in the MCU module. This keeps the MCU's digital noise off the board peripheral rail.

**Note:** A 10uF bulk capacitor should be added on the 3.3V rail at the control board connector entry point. The 3.3V rail travels from the AMS1117 on the main board across the board-to-board connector to the control board, where it powers shift registers, LCD, and MIDI logic. The connector introduces inductance, and transient current demands (e.g., shift register clocking, LCD SPI bursts) can cause voltage droops without local bulk decoupling at the connector landing.

### 5V Rail Load Budget

The +5V rail powers LED drivers (IS31FL3216A), DAC analog supply (via RC filter), clock output buffers, and the PGA2350 VB supply.

### Capacitor Values

| Capacitor | Value | Purpose |
|---|---|---|
| c_bulk_12p | 10uF | +12V bulk decoupling |
| c_bulk_12n | 10uF | -12V bulk decoupling |
| c_5v_bulk | 10uF | +5V bulk decoupling |
| c_5v_hf | 100nF | +5V high-frequency decoupling |
| c_3v3_in | 10uF | AMS1117 input stability (required) |
| c_3v3_out | 22uF | AMS1117 output stability (>=22uF required per datasheet) |
| c_3v3_out_hf | 100nF | 3.3V high-frequency decoupling |

## Key Parts

| Part | Role | Datasheet |
|---|---|---|
| AMS1117-3.3 | 1A LDO voltage regulator, 3.3V fixed output | [AMS1117 datasheet](http://www.advanced-monolithic.com/pdf/ds1117.pdf) |
| B5819W | 1A 40V Schottky barrier diode (x3) | [B5819W datasheet](https://www.diodes.com/assets/Datasheets/ds30146.pdf) |
| EurorackPowerHeader16 | Standard 16-pin eurorack power connector | -- |

## Signal Interface

| Signal | Direction | Description |
|---|---|---|
| v12p | out | Protected +12V rail (~11.6V after Schottky drop) |
| v12n | out | Protected -12V rail (~-11.6V after Schottky drop) |
| v5v | out | Protected +5V rail (~4.6V after Schottky drop) |
| v3v3 | out | Regulated +3.3V rail |
| gnd | -- | Common ground |

## References

- AMS1117 datasheet: input/output capacitor requirements, TAB pin connection
- Eurorack power bus specification: 16-pin header pinout (Doepfer standard)

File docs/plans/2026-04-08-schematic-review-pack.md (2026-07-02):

# Schematic Review Pack Implementation Plan

**Goal:** Generate **local, shareable PDF files** (one per board) with human-readable schematic diagrams from the committed `.kicad_pcb` files, so a reviewer who cannot read `.ato` code can validate the design. Final deliverable = PDF the user can email/share.

**Architecture:** Two-stage Python pipeline under `hardware/boards/scripts/review/`:
1. **Extractor** (uses KiCad's `pcbnew`): reads a `.kicad_pcb`, groups footprints by the `atopile_address` field (first segment = subcircuit), captures pads→nets, emits JSON.
2. **Renderer** (pure Python, no pcbnew): consumes JSON, draws schematic-style SVGs using a handwritten symbol library, grid layout per subcircuit, force-directed layout for board overview. SVG→PDF via `rsvg-convert`, per-subcircuit PDFs merged into one PDF per board via `pypdf`.

**Final output:** `hardware/boards/build/review/control.pdf`, `main.pdf`, `faceplate.pdf` — each is a single self-contained PDF with a cover page (overview) + one page per subcircuit. No Makefile target, no git changes. Invoked by hand: `KICAD_PYTHON hardware/boards/scripts/review/gen_review_pack.py --out build/review`.

**Tech Stack:** Python 3 (venv + KiCad's Python 3.9), pcbnew 10.0.0, rsvg-convert (Homebrew), no npm/Node, no Graphviz.

**Style choice (2c-hybrid):** proper schematic symbols for passives and actives, IC/connector as labeled rectangles, **no wires drawn between components** — instead every pin gets a short stub with a net-label. This is a legitimate "flat net-label schematic" style used in dense professional schematics; it sidesteps the auto-routing problem entirely while still looking schematic-like.

---

## File Structure

```
hardware/boards/scripts/review/
  __init__.py
  extract.py                 # pcbnew-based PCB extractor → JSON
  symbols.py                 # component symbol SVG library
  layout.py                  # grid + force-directed placement helpers
  render_subcircuit.py       # one subcircuit → one SVG
  render_overview.py         # board overview → one SVG
  render_index.py            # index.html + board landing pages
  gen_review_pack.py         # main entry point (orchestrates all boards)
  tests/
    __init__.py
    conftest.py
    test_extract.py          # runs against committed main-placed.kicad_pcb
    test_symbols.py          # pure-Python symbol tests
    test_layout.py           # grid/force-directed layout tests
    test_render_subcircuit.py
    fixtures/                # tiny synthetic JSON fixtures
```

Output directory (gitignored via existing `build/*` rule):
```
hardware/boards/build/review/
  index.html                 # top-level landing: pick a board
  control/
    index.html
    00_overview.svg + .pdf
    01_<subcircuit>.svg + .pdf
    ...
  main/
    (same)
  faceplate/
    (same)
```

Makefile target `make review-pack` with dependency on committed `*-placed.kicad_pcb` + faceplate, invokes gen_review_pack.py via KICAD_PYTHON.

---

## Stage 0: Setup

### Task 0.1: Create directory and empty module

- [ ] Create `hardware/boards/scripts/review/__init__.py` (empty)
- [ ] Create `hardware/boards/scripts/review/tests/__init__.py` (empty)
- [ ] Create `hardware/boards/scripts/review/tests/conftest.py` with sys.path fixup so `from review import …` works:

```python
import sys
from pathlib import Path

# Make the review package importable under tests.
ROOT = Path(__file__).resolve().parents[2]
if str(ROOT) not in sys.path:
    sys.path.insert(0, str(ROOT))
```

---

## Stage 1: Extractor (TDD)

### Task 1.1: Define the JSON schema as a dataclass module

**Files:** Create `hardware/boards/scripts/review/extract.py`

The schema we emit per board:
```python
{
  "board": "main",
  "source": "path/to/main-placed.kicad_pcb",
  "bbox_mm": {"x": 0, "y": 0, "w": 100, "h": 100},
  "subcircuits": {
    "dac": {
      "name": "dac",
      "components": [
        {
          "ref": "U1",
          "value": "DAC80508ZRTER",
          "footprint": "package:QFN-40",
          "atopile_address": "dac.dac1",
          "pads": [
            {"number": "1", "name": "VREF", "net": "c_ref1_hf-power-hv"},
            ...
          ]
        },
        ...
      ]
    },
    ...
  },
  "nets_per_subcircuit": {
    "dac": ["net_a", "net_b", ...]   # all unique nets touched by this subcircuit
  },
  "cross_subcircuit_nets": [
    {"net": "SCLK", "subcircuits": ["dac", "mcu", "swd_header"]},
    ...
  ]
}
```

- [ ] Write the extractor skeleton that:
  - Takes `board_name`, `pcb_path`, optional `out_path`
  - Imports pcbnew (fail loudly if not available)
  - Loads board, iterates footprints, extracts ref / value / fpid / atopile_address / pads with nets
  - Groups by first segment of `atopile_address` (components without the field land in `__unsorted__`)
  - Computes `nets_per_subcircuit` and `cross_subcircuit_nets` (nets appearing in ≥2 subcircuits)
  - Returns the dict; if `out_path` is given, also writes JSON to disk

- [ ] Add a `__main__` guard so it can be invoked: `KICAD_PYTHON extract.py <board> <pcb_path> <out_json>`

### Task 1.2: Integration test against committed main-placed.kicad_pcb

**Files:** Create `hardware/boards/scripts/review/tests/test_extract.py`

- [ ] Test that extracting `main-placed.kicad_pcb` produces expected top-level keys
- [ ] Test that `dac` subcircuit is present and has ≥30 components (we counted 79)
- [ ] Test that every component has a non-empty `ref` and `atopile_address`
- [ ] Test that `cross_subcircuit_nets` contains at least one net appearing in both `dac` and `mcu` (SPI nets: SCLK, DIN, SDO)
- [ ] Run test under KICAD_PYTHON, verify all pass

```python
def test_extract_main_board(pcb_main):
    data = extract_board("main", pcb_main)
    assert data["board"] == "main"
    assert "dac" in data["subcircuits"]
    assert len(data["subcircuits"]["dac"]["components"]) >= 30
    for sub in data["subcircuits"].values():
        for c in sub["components"]:
            assert c["ref"]
            assert c["atopile_address"]
    cross_nets = {n["net"] for n in data["cross_subcircuit_nets"]}
    # SPI nets cross dac ↔ mcu
    assert any(n in cross_nets for n in ["SCLK", "DIN", "SDO"])
```

The `pcb_main` fixture reads `/Users/devboy/dev/devboy/requencer/hardware/boards/build/main-placed.kicad_pcb`.

---

## Stage 2: Symbol Library (TDD)

### Task 2.1: Define the Symbol interface

**Files:** Create `hardware/boards/scripts/review/symbols.py`

Each symbol is a class with:
- `width` and `height` in SVG user units (1 unit ≈ 1 mm on final SVG)
- `pins` — dict of `{pin_name: (x, y, side)}` where side ∈ `{"l", "r", "t", "b"}`
- `render(cx, cy, refdes, value) -> str` that returns an SVG `<g>` group positioned at (cx, cy)

Symbol types to implement (in priority order):
1. **IC** — rectangle, pins on sides, auto-sized by pin count. Handles DAC, MCU, op-amp, regulator, shift-reg, etc.
2. **Connector** — rectangle with pin labels on one side. Handles headers, USB-C, SD, FPC.
3. **R** — resistor zigzag (classic IEC rectangle style is simpler and also valid — use rectangle with "R" marker inside). 2 pins.
4. **C** — two parallel plates. 2 pins.
5. **C_polar** — C with curved plate + polarity marker. 2 pins.
6. **L** — arc loops. 2 pins. (fallback to rectangle with "L" marker is fine)
7. **D** — triangle + cathode line. 2 pins.
8. **LED** — D with arrow marks. 2 pins.
9. **Q_NPN** / **Q_PNP** — BJT circle with B/C/E. 3 pins.
10. **Q_NMOS** / **Q_PMOS** — MOSFET. 3 pins.
11. **Crystal (Y)** — rectangle with wave marker. 2 pins.
12. **Fuse (F)** — rectangle with wavy line. 2 pins.
13. **Test point (TP)** — circle. 1 pin.
14. **Generic** — fallback rectangle with `?` marker, any number of pins.

A `symbol_for(component)` function picks the right symbol class from:
- `component["ref"][0]` (R, C, L, D, Q, U, J, Y, F, TP, etc.) — primary signal
- `component["value"]` for disambiguation (e.g. `Q_NPN` vs `Q_PMOS`, `C` vs `C_polar` by uF value or footprint)
- `component["footprint"]` as secondary disambiguation

### Task 2.2: Test symbol_for classification

**Files:** Create `hardware/boards/scripts/review/tests/test_symbols.py`

- [ ] Test R → R symbol
- [ ] Test C → C symbol
- [ ] Test U → IC symbol
- [ ] Test Q with `NPN` in value → Q_NPN
- [ ] Test unknown prefix → Generic
- [ ] Test that every Symbol class has `width > 0`, `height > 0`, at least one pin

### Task 2.3: Implement render() for each symbol

- [ ] IC: rectangle sized by max(pin_count_left, pin_count_right) × pin_spacing, pin labels inside, refdes/value above
- [ ] R: `<rect>` 4×10 units, "R" letter inside, two pin stubs top/bottom, refdes/value right
- [ ] C: two parallel horizontal lines, two pin stubs top/bottom, refdes/value right
- [ ] C_polar: as C but one curved plate, "+" near positive pin
- [ ] D: triangle path, cathode bar, refdes/value right
- [ ] LED: D + two outward arrows
- [ ] Q_NPN/Q_PNP: circle + base line + two emitter/collector lines; arrow on emitter (in/out)
- [ ] Q_NMOS/Q_PMOS: circle + gate insulator + 3 channel segments
- [ ] Connector: rectangle, pins on right side only, labels inside
- [ ] Y/F/TP/L/Generic: simpler — just rectangle with marker character

- [ ] Snapshot test: each symbol's SVG output matches a recorded snapshot (tiny string compare)

---

## Stage 3: Layout Helpers (TDD)

### Task 3.1: Grid placement

**Files:** Create `hardware/boards/scripts/review/layout.py`

- [ ] `grid_place(items, max_cols, col_gap, row_gap)` → list of `(item, cx, cy)` tuples. Width of each cell = max item width in that column. Items are sorted by symbol type priority (ICs first, then connectors, then passives grouped by value) to keep related components adjacent.
- [ ] Test grid returns correct positions for 6 items, 3 cols
- [ ] Test grid handles rows with varying heights

### Task 3.2: Force-directed layout for board overview

- [ ] `force_layout(nodes, edges, iterations=200)` — simple Fruchterman-Reingold implementation. Each node has `width`, `height`. Edges pull nodes together, all nodes repel. Returns positions.
- [ ] Test convergence: 4 nodes in a square topology → positions don't collide
- [ ] Test determinism: same input with same seed → same output

---

## Stage 4: Subcircuit Renderer

### Task 4.1: Render one subcircuit to SVG

**Files:** Create `hardware/boards/scripts/review/render_subcircuit.py`

- [ ] `render_subcircuit(subcircuit, out_path, title_block)` function
- [ ] For each component, pick a symbol via `symbol_for()`, grid-place them
- [ ] For each pin of each component, draw a short stub (4 units) and a net label at the end
- [ ] Title block at top: board name, subcircuit name, component count, ports list
- [ ] Color coding: power nets (5V, 3V3, GND, -5V, etc.) highlighted, signal nets plain
- [ ] Write SVG to disk

### Task 4.2: Integration test — render dac subcircuit from extracted JSON

**Files:** `hardware/boards/scripts/review/tests/test_render_subcircuit.py`

- [ ] Build a synthetic subcircuit dict with 3 components
- [ ] Render to a temp SVG file
- [ ] Assert the file exists, is non-empty, contains `<svg`, contains each refdes, contains ≥1 net label

---

## Stage 5: Overview Renderer

### Task 5.1: Render the board overview SVG

**Files:** Create `hardware/boards/scripts/review/render_overview.py`

- [ ] Each subcircuit becomes a node with size = `f(component_count)`
- [ ] Inter-block nets become edges (labeled with net name)
- [ ] Run `force_layout` to position nodes
- [ ] Power nets routed to a distinct "power bus" at the bottom (skip force layout for them)
- [ ] Title block: board name, total component count, subcircuit count, cross-net count
- [ ] Click handlers (`<a xlink:href="01_dac.svg">`) so SVG links into the detail pages when opened in a browser

---

## Stage 6: Index + PDF export

### Task 6.1: index.html per board

**Files:** Create `hardware/boards/scripts/review/render_index.py`

- [ ] Per-board `index.html` with:
  - Board name + summary (component count, subcircuit count)
  - Inline overview SVG at top
  - List of subcircuit links with component counts
- [ ] Top-level `review/index.html` with links to each board

### Task 6.2: SVG → PDF conversion

- [ ] Helper that shells out to `rsvg-convert -f pdf -o out.pdf in.svg`
- [ ] Skip PDF for overview pages (they'll be too big — PDF is per subcircuit only)
- [ ] Bundle all subcircuit PDFs into a single `review.pdf` per board using a simple page concat: since `rsvg-convert` emits one page per file, concatenate via `pdfunite` OR simply keep separate PDFs and link them from the index

Check for pdfunite availability; if not installed, skip the merged PDF and just emit per-subcircuit PDFs.

---

## Stage 7: Orchestrator

### Task 7.1: gen_review_pack.py

**Files:** Create `hardware/boards/scripts/review/gen_review_pack.py`

- [ ] Reads `hardware/boards/build/control-placed.kicad_pcb`, `main-placed.kicad_pcb`, `hardware/faceplate/elec/layout/faceplate.kicad_pcb`
- [ ] For each board: extract → render overview + each subcircuit → generate index.html + PDFs
- [ ] Writes to `hardware/boards/build/review/`
- [ ] `if __name__ == "__main__"` with arg handling: `gen_review_pack.py [--board control|main|faceplate|all] [--out DIR]`

### Task 7.2: Smoke test running the full pipeline

- [ ] Run `gen_review_pack.py --board main` end-to-end
- [ ] Verify `build/review/main/00_overview.svg` exists
- [ ] Verify `build/review/main/index.html` exists
- [ ] Verify at least one subcircuit SVG+PDF exists
- [ ] Open the PDF and visually check it's readable (I'll render it to PNG and inspect it)

---

## Stage 8: Makefile target

### Task 8.1: Add `review-pack` target

**Files:** Modify `hardware/Makefile`

- [ ] Add variables near top:
```makefile
REVIEW_DIR     := $(BUILD)/review
REVIEW_SCRIPT  := $(SCRIPTS)/review/gen_review_pack.py
REVIEW_DEPS    := $(CONTROL_PLACED) $(MAIN_PLACED) $(FACEPLATE_PCB) $(shell find $(SCRIPTS)/review -name '*.py' 2>/dev/null)
```

- [ ] Add target:
```makefile
.PHONY: review-pack review-pack-clean
review-pack: $(REVIEW_DIR)/index.html ## Generate schematic review pack (SVG + PDF per board)

$(REVIEW_DIR)/index.html: $(REVIEW_DEPS)
	@echo "== Generating schematic review pack =="
	@$(KICAD_ENV) $(KICAD_PYTHON) $(REVIEW_SCRIPT) --out $(REVIEW_DIR)
	@echo "== Review pack ready: open $(REVIEW_DIR)/index.html =="

review-pack-clean:
	@rm -rf $(REVIEW_DIR)
```

- [ ] Add to the top-of-file help block.

---

## Stage 9: Code Review

### Task 9.1: Run superpowers:code-reviewer on the whole review/ module

- [ ] Dispatch code-reviewer agent with scope = `hardware/boards/scripts/review/` + Makefile diff
- [ ] Address any HIGH/CRITICAL findings inline
- [ ] MEDIUM findings: fix if quick, note in plan if deferred
- [ ] LOW/style findings: skip unless trivial

### Task 9.2: Verify final output

- [ ] Re-run `make review-pack` from scratch on a clean output dir
- [ ] Open `build/review/index.html` — verify nav works
- [ ] Render final overview SVG and one detail SVG to PNG, inspect visually
- [ ] Confirm PDFs exist and are non-empty

---

## Self-Review Checklist

- [x] All stages covered by tasks?
- [x] Every file path is absolute or relative from a documented root?
- [x] No "TODO later" placeholders in any task?
- [x] TDD used where it adds value (extract, symbols, layout) and skipped where it doesn't (SVG visual rendering — that gets visual verification instead)?
- [x] The symbol classification in Task 2.1 matches the component types actually present in main/control (IC, R, C, L, D, LED, Q, connectors, crystal confirmed from grep)?
- [x] Inter-subcircuit net computation handles the SPI and power rails that cross boundaries?
- [x] Makefile target fits existing conventions (uses KICAD_ENV + KICAD_PYTHON, file-based deps)?

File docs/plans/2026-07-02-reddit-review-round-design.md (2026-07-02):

# Reddit Review Round — Design

**Goal:** Get the repo, website, and artifacts into shape for a Reddit post asking the
synth-DIY community to review the hardware design before manufacturing. All tests pass
locally; what's missing is presentation, up-to-date docs, downloadable KiCad artifacts,
and a clear review ask.

**Date:** 2026-07-02

---

## 1. Single-source manual — `docs/manual.md`

One markdown file is the user manual for both GitHub and the web app. Written
**mouse/touch-first**; keyboard shortcuts are a short, low-priority section at the end.

Structure:

1. **What is this?** — 4-track eurorack-style step sequencer; live-performance backstory
   (replaces 4 sequencers + utility modules); polymetric randomization concept.
2. **Quick start (mouse & touch)** — click buttons to interact; press-and-hold a button
   while pressing another for hold combos; **double-click any holdable button for sticky
   hold** (one-handed operation — click again or click elsewhere to release); drag or
   scroll on encoders to turn them, click to push; everything works on touch screens
   (multi-touch combos supported).
3. **Tracks & subtracks** — 4 tracks × 4 subtracks (gate/pitch/velocity/mod), each with
   independent length (1–64) and clock divider → polymeter.
4. **Randomizer** — the hierarchy first: randomize *everything*, *one track*, or *one
   subtrack layer* (hold track or subtrack button + RAND). Then per-track config (scale,
   root, range, density, velocity), the four gate algorithms (RAND/EUCL/SYNC/CLST), and
   the 8 factory presets + saving custom presets.
5. **Drift** — per-subtrack stochastic mutation over time.
6. **Transpose** — per-track semitone offset, range, scale quantization.
7. **Routing** — any subtrack output to any of the 4 output jacks.
8. **Mute & patterns** — mute screen, pattern screen.
9. **Settings** — BPM, clock source (INT/MIDI/EXT), MIDI device/channels.
10. **Keyboard shortcuts** — brief: "every control also has a key; press `?` in the app
    for the full keymap." No full table here (the in-app `?` modal remains the reference).

### Consumption

- **Web app:** `instructions-modal.ts` imports the file at build time via Vite
  `?raw` (`import manual from '../../../docs/manual.md?raw'`) and renders it with
  **`marked`** (new dependency in `web/package.json`). The hardcoded `SECTIONS` array is
  deleted. Modal styling stays as-is; markdown output is styled with a small scoped CSS
  block (headings, paragraphs, lists, `<strong>`).
- **README:** links to `docs/manual.md` (GitHub renders it natively). No duplicated
  manual content remains in the README.

### Testing

- Unit test: modal renders headings/sections from the imported markdown (jsdom).
- Existing modal toggle tests keep passing.

## 2. README rewrite

New structure, top to bottom:

1. Pitch (2–3 sentences) + screenshot + **Try it live** link.
2. **⚡ Help wanted: hardware design review** — what the module is electrically
   (RP2350, DAC8568 CV outs, three-board stack, eurorack power), links to: schematic
   review PDFs, the GitHub Release with KiCad files, and the live demo. States what
   feedback is sought and that the design has not been manufactured yet.
3. Features overview (short prose, no key tables) + link to `docs/manual.md`.
4. Architecture summary (Rust crates, TS web preview, hardware dirs) — condensed from
   CLAUDE.md wording.
5. Development commands (`make dev`, `make test`, …).
6. License section (MIT code / CERN-OHL-S hardware).

## 3. In-app discoverability

- Always-visible **"MANUAL"** and **"?"** buttons on the page (small fixed control near
  the panel, matching the existing debug-menu aesthetic) wired to `toggleInstructions()`
  and `toggleHelp()`. Debug-menu entries stay.
- **First-visit auto-open:** on load, if `localStorage['requencer-manual-seen']` is
  unset, open the manual modal and set the flag. Closing works as today (click outside /
  any key).

## 4. KiCad artifacts — `make release-artifacts`

CI cannot build hardware, so artifacts are built locally and published as a GitHub
Release via `gh` CLI. **Claude builds the tooling; the user runs it** (no commits, tags,
or releases made by Claude).

- New script `hardware/boards/scripts/export/package_release.py` (plain `python3`, no
  pcbnew — handles prereq checks, README.txt generation, and zip assembly) that assembles
  `build/release/requencer-hardware-<tag>.zip` containing:
  - `kicad/control/` — `control-poured.kicad_pcb` + `.kicad_pro`/`.kicad_prl`
  - `kicad/main/` — same for main
  - `kicad/faceplate/` — faceplate KiCad project
  - `review/` — `control.pdf`, `main.pdf` from the schematic review pack
  - `manufacturing/` — gerber/BOM outputs from `make export`
    (`build/manufacturing/{control,main,faceplate}`)
  - `3d/` — STEP files
  - `README.txt` — what's inside, which KiCad version, pointer to the repo/post
- Target lives in `hardware/Makefile` with a top-level `make release-artifacts`
  passthrough: `make release-artifacts TAG=hw-review-r1` →
  builds zip, then `gh release create <TAG> <zip> --title … --notes-file …`
  (idempotent-ish: fail with a clear message if the tag exists; `gh release upload
  --clobber` for re-runs).
- Prereq check: fail early with a readable error if expected inputs
  (poured PCBs, review PDFs, manufacturing exports) are missing, telling the user which
  make target produces them.
- The untracked `hardware/boards/scripts/review/` module and its plan doc get committed
  **by the user** as part of this round.

## 5. Licenses

- `LICENSE` (repo root): MIT, copyright Dominic Graefen — covers all code.
- `hardware/LICENSE`: CERN-OHL-S v2 — covers hardware design files (`hardware/`).
- README license section explaining the split.

## 6. Reddit post draft + link previews

- `docs/reddit-post.md`: 2–3 title options; body with: what the module is, live demo
  link, one-paragraph architecture, **specific review asks** (eurorack power entry &
  regulators, DAC8568 output stage / 1V-oct scaling & offset, board-to-board connector
  pinout & stackup, USB-C, SD card, MIDI input circuit, anything the production-check
  can't catch), links to release zip / review PDFs / repo, and a note that it's
  open-source (MIT + CERN-OHL-S). Target subs noted: r/synthdiy, r/modular,
  r/AskElectronics (crosspost etiquette: tailor the ask).
- `web/index.html`: proper `<title>` ("Requencer — 4-track polymetric eurorack
  sequencer"), meta description, Open Graph + Twitter card tags using
  `docs/screenshot.png` (copied/served as a static asset in `web/public/` so the
  deployed site can reference it with an absolute URL).

## Out of scope

Demo GIF/video, hardware CI builds, changes to the review-pack renderer itself,
faceplate review PDF (mostly mechanical), engine/firmware changes.

## Error handling

- Release target: hard fail with actionable message on missing artifacts or existing tag.
- Manual import: build-time — a missing `docs/manual.md` fails the Vite build (desired).

## Testing summary

- `make web` (tests + lint + build) green after modal/manual changes.
- New jsdom test for markdown-rendered modal.
- `make release-artifacts` dry-run path verified locally (zip contents listed); the
  actual `gh release create` is exercised by the user.

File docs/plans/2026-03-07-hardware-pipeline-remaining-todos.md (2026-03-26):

# Hardware Pipeline — Status & Known Shortcomings

> Updated 2026-03-18. Originally written 2026-03-07.

Status: Pipeline runs end-to-end locally via Make. No CI/CD automation yet. Build, footprints, faceplate, placement (5 strategies), routing, 3D export all functional.

## What Works

- **Atopile build**: `ato build` generates KiCad PCBs for control + main boards
- **Footprint generation**: All custom parts have local `.kicad_mod` and `.kicad_sym` files
- **Faceplate generation**: Generates faceplate PCB from `panel-layout.json`
- **Component placement**: 5 strategies (constructive, force-directed, grid-spread, SA-refine, wavefront) with parallel execution and post-routing selection
- **FreeRouting autoroute**: Functional via `make hw-route`
- **3D export**: STEP → GLB conversion pipeline for web viewer
- **Ground pours**: Automated ground fill after routing
- **Manufacturing export**: Gerbers + BOM export via `make hw-export`
- **11 Make targets**: `hw-all`, `hw-build`, `hw-footprints`, `hw-place`, `hw-faceplate`, `hw-route`, `hw-gnd-pours`, `hw-3d`, `hw-3d-models`, `hw-export`, `hw-clean`

## Resolved Issues

### ~~Missing Components~~ (Fixed)
All 3 previously-missing components are resolved:
- `display.q_bl` — now `q_lcd_bl = new _2N7002` in control.ato
- `mcu.d_vb` — now `d_vb = new B5819W` in mcu.ato
- `mcu.d_usb` — intentionally omitted (USB data lines wired directly, no ESD diode needed for prototype)

### ~~Autoroute Script Duplicate Steps~~ (Fixed)
Removed gerber export and DRC from autoroute script — now separate workflow steps.

## Remaining Shortcomings

### 1. No CI/CD Pipeline
Hardware build is local-only. No GitHub Actions workflow exists for automated builds. Could add CI for `ato build` + placement + DRC checks.

### 2. Build Speed (~15 min for `ato build`)
Atopile's constraint solver processes a large graph. `--keep-picked-parts` reuses previous picks (~40% faster). No true incremental build in atopile 0.14.

### 3. PGA2350 Supplier Workaround
`PGA2350.ato` uses a placeholder LCSC part number (`C0000`) because Pimoroni parts can't be auto-picked. Cosmetic only — part has local footprint and symbol.

### 4. FreeRouting Speed (~30-60 min)
FreeRouting with `-mp 20` on a full board takes 30-60 minutes. Possible mitigations: reduce max passes for iteration, cache routed PCB when netlist unchanged.

### 5. DRC Status
DRC runs after routing. Expect some violations until design is fully finalized. Should become a blocking check before manufacturing submission.

## Recommended Next Steps

1. **Add CI workflow** — at minimum run `ato build` + placement on PRs to catch regressions
2. **Reduce FreeRouting passes for iteration** — use `-mp 5` for quick checks, full 20 for final
3. **DRC as gate** — make DRC pass a requirement before manufacturing export

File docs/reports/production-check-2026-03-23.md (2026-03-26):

# Production Validation Report — Requencer
**Date:** 2026-03-23
**Verdict:** DO NOT MANUFACTURE

## Summary

| # | Section | Agent | Verdict | Issues |
|---|---|---|---|---|
| 0 | Component & Footprint Audit | footprint-audit | WARN | 0 FAIL, 10 WARN — missing 3D model refs, manufacturer mismatches |
| 1 | GPIO Function-Select | gpio-pin-compat | PASS | All 30 GPIOs valid, firmware matches schematic |
| 2 | Connector Pin Matching | connector-stacking | WARN | 0 FAIL, 3 WARN — +12V/-12V single pin, 3D check needed |
| 3 | Signal Path Integrity | signal-path | WARN | 0 FAIL, 7 WARN — MIDI CA-033, SD detect, encoder debounce |
| 4 | Power Supply | power-supply | PASS | All rails correct, Tj=66°C, current within budget |
| 5 | Component-Purpose Fitness | signal-path | WARN | Covered by signal-path agent above |
| 6 | Multi-Button Input | button-scan | PASS | Direct wiring, 200Hz scan, 40 bits mapped |
| 7 | Routing Quality | pcb-layout | FAIL | 4 FAIL, 6 WARN — decoupling placement, GND vias |
| 8 | Firmware-Pin Compat | gpio-pin-compat | PASS | Covered by gpio-pin-compat agent above |
| 9 | Parts Availability | parts-sourcing | WARN | 0 FAIL, 6 WARN — low stock DAC/OPA, extended parts fees |
| 10 | Mechanical Fit | mechanical-fit | WARN | 0 FAIL, 1 WARN — board stacking needs 3D check |
| 11 | Datasheet Compliance | datasheet-compliance | WARN | 0 FAIL, 4 WARN — I2C rise time, AMS1117 cap margin |
| 12 | Manufacturing Output | manufacturing-files | FAIL | 3 FAIL, 2 WARN — missing pin 1 markers on 11 ICs |
| 13 | Silkscreen & Markings | manufacturing-files | FAIL | Covered by manufacturing-files agent above |
| 14 | EMC & Analog Noise | pcb-layout | FAIL | Covered by pcb-layout agent above |
| 15 | Board Bring-Up Plan | bringup-plan | WARN | Risk level HIGH, workarounds identified |
| 16 | Sandwich Stack Assembly | connector-stacking | WARN | Covered by connector-stacking agent above |
| 17 | Component Documentation | documentation-audit | WARN | 0 FAIL, 6 WARN — stale READMEs, missing catalog entries |

## Action Items

### Must Fix (FAIL)

1. **Decoupling caps far from OPA4171 op-amps** — 4/5 OPA4171A ICs (X1, X4, X8, X15) have zero bypass caps within 10mm. 100nF on VCC and VEE should be within 2mm. — `hardware/boards/build/main-poured.kicad_pcb` — Fix: Re-place bypass caps adjacent to each OPA4171A IC.

2. **Decoupling caps far from PGA2350 MCU** — X28 (PGA2350) at (70,42) has zero caps within 10mm. MCU datasheet requires multiple 100nF close to power pins. — `hardware/boards/build/main-poured.kicad_pcb` — Fix: Place 4x 100nF within 2mm of PGA2350 power pins.

3. **Decoupling caps far from IS31FL3216A** — U8 and U6 on control board have zero caps within 10mm. — `hardware/boards/build/control-poured.kicad_pcb` — Fix: Place 100nF adjacent to each IS31FL3216A VCC pin.

4. **DAC80508 bypass caps 7-8mm away** — X13 and X22 have nearest bypass caps at 6.8-8.2mm. For a 16-bit DAC, caps must be within 1-2mm. — `hardware/boards/build/main-poured.kicad_pcb` — Fix: Place 100nF + 10uF within 2mm of each DAC power pin.

5. **OPA4171A TSSOP-14 missing pin 1 silkscreen** — 5 ICs (U3-U7) on main board have no pin 1 indicator, only body outline lines. — Fix: Add pin 1 dot (fp_circle ~0.3mm) near pad 1 on F.SilkS in the TSSOP-14 footprint.

6. **74HC165D SOIC-16 missing pin 1 silkscreen** — 5 ICs (U1-U5) on control board have no pin 1 indicator. Critical for debugging button scan chain. — Fix: Add pin 1 dot or notch on the SOIC-16 footprint's F.SilkS layer.

7. **AMS1117-3.3 SOT-223 no silkscreen at all** — U9 on main board has zero silkscreen elements. — Fix: Add body outline and tab indicator on F.SilkS for the SOT-223 footprint.

### Should Fix (WARN)

1. **Only 3 GND stitching vias on main board** — Zero near analog ICs. — Fix: Add GND stitching vias at ~5mm spacing, especially near OPA4171A and DAC80508.

2. **SPI clock 0.73mm from CV trace** — SPI1 SCK runs 0.73mm from dac-IN3_P on F.Cu, below 1mm target. — Fix: Route SCLK on inner layer or increase separation.

3. **Signal traces under DAC80508** — X22 has 3 signal segments on B.Cu under IC, slotting ground plane. — Fix: Reroute signals to avoid bisecting ground under DAC.

4. **Zones use solid pad connection** — No thermal relief on GND zones. Makes THT soldering difficult. — Fix: Change zone pad connection to thermal relief for THT pads.

5. **Power sub-net traces at 0.15mm** — Named power nets (c_op5_p-power-hv, etc.) routed at 0.15mm. — Fix: Assign to Power netclass or increase width.

6. **No bulk caps at board-to-board connectors** — Neither ShroudedHeader2x16 has bulk caps within 10mm. — Fix: Place 10-22uF on each power rail near connectors.

7. **I2C at 400kHz may have slow rise times** — 4.7k pull-ups + ~200pF bus capacitance = ~752ns rise time (max 300ns for Fast Mode). — Fix: Reduce pull-ups to 2.2k or lower I2C frequency to 100kHz.

8. **AMS1117 output cap exactly 22uF** — Zero margin above datasheet minimum. — Fix: Increase to 47uF for improved transient response.

9. **DAC80508 low stock (137 units at JLCPCB)** — Safety margin 0.27x. — Fix: Pre-order from TI distributors or identify backup supplier.

10. **OPA4171A low stock (370 units JLCPCB, 2 units LCSC)** — Safety margin 0.30x. — Fix: Order immediately; identify OPA4172/OPA4192 as pin-compatible alternatives.

11. **Missing 3D model references in footprints** — FPC_32P_05MM, PJS008U, WQP518MA, TactileSwitch have .step files but no `(model ...)` in .kicad_mod. — Fix: Add model references.

12. **H11L1S, ResArray4x0603, PinHeader1x3 missing .step files** — No 3D models exist for these components. — Fix: Source or create .step models.

13. **MIDI IN pull-up is 1k** — Wastes 3.3mA continuously. — Fix: Replace with 4.7k-10k.

14. **No pull-up on SD CS line** — During MCU boot delay, CS may float. — Fix: Add 10k pull-up at SD connector end.

15. **No base-emitter resistor on clock/reset NPN** — Output state undefined during MCU boot. — Fix: Add 100k B-E pull-down resistors.

16. **USB shield direct to GND** — No EMI filtering. — Fix: Add 1nF cap or ferrite between shield and GND.

17. **ShroudedHeader2x16 pin 1 subtle** — Only a short line segment. — Fix: Add "1" text label near pin 1 pad.

18. **PJS008U README says "card detect switch"** — Part has none. — Fix: Update README.

19. **button-scan.ato says "34 buttons"** — 36 are instantiated. — Fix: Update comments to 36.

20. **Components README lists TactileSwitch as THT** — Is SMD (TS-1187A). — Fix: Change to SMD.

21. **PinHeader1x3 missing from components catalog** — Used for SWD debug. — Fix: Add entry to README.

22. **Missing 3D models for DAC80508, IS31FL3216A, connectors** — Needed for assembly verification. — Fix: Source QFN models and connector models.

### Informational

- **+12V/-12V single pin on connector** — Acceptable since these rails are low-current on control board side (only op-amps on main board consume significant +/-12V).
- **MIDI OUT uses CA-033 3.3V resistor values** — Correct per spec for 3.3V transmitters. Compatible with most modern MIDI equipment.
- **Encoder debounce caps are 10nF** — By design; real debounce is in firmware PIO state machine.
- **SD card has no hardware detect** — PJS008U-3000-0 variant lacks detect switch. Firmware uses SPI probe as fallback.
- **DAC80508 WQFN-16 has no LDAC/CLR pins** — Package limitation; updates are immediate on SPI write. Acceptable for eurorack CV rates.
- **H11L1S output pull-up to 3.3V while VCC is 5V** — Valid mixed-voltage open-collector configuration. Logic levels compatible with PGA2350.
- **7 extended-library SMD parts** — $21/board in JLCPCB setup fees. Expected for a specialized design.
- **All THT parts are single-source** — Typical for eurorack-specific parts (Thonkiconn jacks, PB6149L buttons).
- **Board stacking clearance** — Requires manual 3D verification in CAD viewer. 10mm standoffs provide clearance.
- **Manufacturer mismatches on LCSC** — BAT54S (hongjiacheng vs Nexperia), H11L1S (Everlight vs Lite-On), PRTR5V0U2X (TECH PUBLIC vs Nexperia). Functional equivalents, acceptable.
- **Negative Y coordinates in CPL** — KiCad convention. JLCPCB handles this automatically during upload.

## Detailed Findings

### Section 0: Footprint Audit (Agent 0) — WARN

All pin mappings verified correct against datasheets for all 25 active components. No FAIL issues.

Key findings:
- All fine-pitch ICs (DAC80508 WQFN-16, IS31FL3216A QFN-28, OPA4171A TSSOP-14, PRTR5V0U2X SOT-143B) have correct pad dimensions within IPC ranges.
- All QFN/WQFN exposed/thermal pads are declared and connected to GND.
- Pin count matches between .ato, .kicad_sym, and .kicad_mod for every component.
- 4 footprints have .step files but missing `(model ...)` references.
- 3 components lack .step files entirely (H11L1S, ResArray4x0603, PinHeader1x3).
- 3 manufacturer mismatches on LCSC-sourced parts (functional equivalents).

### Sections 1, 8: GPIO Pin Compatibility (Agent 1) — PASS

All 30 GPIOs correctly assigned:
- SPI0: GP0 (RX), GP2 (SCK), GP3 (TX) — valid
- SPI1: GP30 (SCK), GP31 (TX) — valid
- UART1: GP20 (TX), GP21 (RX) — valid
- I2C0: GP12 (SDA), GP13 (SCL) — valid
- ADC: GP40-43 — valid (only ADC-capable pins)
- All plain GPIO assignments conflict-free
- Firmware (main.rs, pins.rs) matches mcu.ato exactly for all 33 pin assignments

### Sections 2, 16: Connector & Stacking (Agent 2) — WARN

All 64 board-to-board connector pins verified matching:
- Header A (32 pins): digital signals + power. B-side row-swap correctly compensates X-mirror.
- Header B (32 pins): analog signals + clock/reset. GND pins shield between analog groups.
- Power: GND (11 pins), 3V3 (2), 5V (2), +12V (1), -12V (1).
- All inter-board signals present: SPI, I2C, button scan, encoders, MIDI, clock/reset, CV, DAC outputs, SD card, USB (stays on main board).
- Connector keying: shrouded Amphenol polarized connectors prevent reverse insertion.
- Pin 1 alignment: row-swap logic verified for all 64 pins.

### Sections 3, 5: Signal Path Integrity (Agent 3) — WARN

All 13 signal paths trace correctly end-to-end. No broken paths or wrong polarities.

**Pitch CV:** DAC1 OUT4-7 → opamp2 (gain=2, offset=-2V) → 470Ω → jack. 0.1% resistors. Range: -2V to +8V. ✓
**Gate CV:** DAC1 OUT0-3 → opamp1 (unity buffer) → 470Ω → jack. Range: 0-5V. ✓
**Velocity CV:** DAC2 OUT0-3 → opamp3 (gain=1.604) → 470Ω → jack. Range: 0-8V. ✓
**Mod CV:** DAC2 OUT4-7 → opamp4 (inv gain=-2, offset=+5V) → 470Ω → jack. Range: -5V to +5V. ✓
**Button scan:** 5× 74HC165D daisy chain, direct wiring, all pull-ups present. ✓
**LED drive:** 3× IS31FL3216A at unique I2C addresses (0x68, 0x6A, 0x6B). ✓
**MIDI:** CA-033 3.3V spec OUT (10Ω/33Ω), H11L1S optocoupler IN with protection diode. ✓
**Clock/Reset:** Input protection (22k/10k + BAT54S + filter). NPN output with firmware inversion. ✓
**Display:** SPI0 → FPC 32-pin. RC reset, MOSFET backlight control, IM pins for SPI mode. ✓
**SD card:** SPI0 shared with display. MISO connected. No hardware card detect. ✓
**USB-C:** 27Ω series, 5.1k CC pull-downs, PRTR5V0U2X ESD. Data-only (no VBUS). ✓
**Encoders:** 10k pull-ups, 10nF RF filter caps. Firmware debounce via PIO. ✓
**CV inputs:** 22k/10k divider → BAT54S clamp → 100nF → ADC GP40-43. ✓

### Section 4: Power Supply (Agent 4) — PASS

All rails verified connected to every consumer. No missing connections.

| Rail | Total | Capacity | Margin | Status |
|---|---|---|---|---|
| +12V | 17.5mA | 300mA | 94% | PASS |
| -12V | 17.5mA | 300mA | 94% | PASS |
| +5V | 190mA | 300mA | 37% | PASS |
| +3.3V | 154.5mA | 800mA | 81% | PASS |

AMS1117 thermal: Pdiss=0.263W, Tj=66°C (well under 100°C limit).
DAC AVDD isolated via 10Ω + 10µF LC filter from LED switching noise.
All ICs have proper bypass caps (in schematic — placement distance is the issue flagged by Agent 6).

### Section 6: Button Scan (Agent 5) — PASS

- Direct wiring topology — no ghosting possible at any combination of simultaneous presses.
- 5× 74HC165D = 40 bits. 36 buttons + 4 spare tied to VCC.
- Chain fully connected: SR1→SR2→SR3→SR4→SR5→MCU GP10.
- CLK_INH tied LOW on all SRs. First SR SER tied to GND.
- 9 resistor arrays (36 pull-ups) for all button inputs.
- Firmware scans at 200Hz with 4-sample debounce (20ms).
- All 40 bit positions mapped in `buttons.rs` (36 events + 4 spare → None).

### Sections 7, 14: PCB Layout & EMC (Agent 6) — FAIL

**DRC:** All violations are expected and documented in board-config.json (IS31FL3216A thermal vias, cosmetic silkscreen/courtyard). Zero unrouted nets.

**Critical placement issues:**
- OPA4171A bypass caps are 19-43mm from the ICs (clustered at bottom of board while ICs are at top).
- PGA2350 has zero caps within 10mm.
- DAC80508 caps are 6.8-8.2mm away.
- IS31FL3216A (2 of 3) have zero caps within 10mm.

**Routing quality:**
- Ground pours on all 4 layers (F.Cu, In1.Cu, In2.Cu, B.Cu) on both boards.
- Only 3 GND stitching vias on main board (all near one DAC).
- Power traces at 0.2mm (below 0.3mm target but acceptable with 4-layer pour). Sub-nets at 0.15mm.
- Zones use solid pad connections (no thermal relief).
- SPI1 SCK 0.73mm from CV trace (below 1mm target).
- Signal traces under DAC80508 X22 (3 segments on B.Cu).

### Section 9: Parts Sourcing (Agent 7) — WARN

All 15 SMD parts found at JLCPCB. All 10 THT parts have at least one supplier.

Low-stock critical parts:
| Part | Stock | Safety (50x) | Risk |
|---|---|---|---|
| DAC80508ZRTER | 137 | 0.27 | HIGH |
| OPA4171AIPWR | 370 | 0.30 | HIGH |
| IS31FL3216A | 3,047 | 4.06 | MEDIUM |

7 extended-library SMD parts = $21/board JLCPCB setup fees.

### Section 10: Mechanical Fit (Agent 8) — WARN

- Panel: 182.60mm × 128.5mm (36HP × 3U) — correct.
- 4 mounting slots: 7.0 × 3.5mm oval at correct positions.
- Jack holes: 6.0mm (WQP518MA/PJ366ST). Encoder holes: 7.0mm (EC11E). Both correct.
- Rail zone clearance: all components clear. Closest: MIDI OUT jack at 3.0mm from bottom zone.
- Tallest component behind panel: SD card at 14.18mm (well under 25mm skiff limit).
- Board stacking: 10mm standoffs. Manual 3D verification recommended.

### Section 11: Datasheet Compliance (Agent 9) — WARN

All absolute maximum ratings safe across all 12 ICs. All supply voltages within recommended operating ranges.

Key findings:
- I2C bus at 400kHz with 4.7k pull-ups: rise time ~752ns (max 300ns for Fast Mode). Risk of communication errors.
- AMS1117 output cap 22µF = exactly minimum spec. Zero margin.
- DAC80508 SPI Mode 1 verified correct. 37.5MHz clock within 50MHz max.
- All op-amp channels properly configured (no floating inputs).
- IS31FL3216A R_EXT=3.3kΩ sets ~5.7mA LED current (conservative, within 40mA max).
- H11L1S mixed-voltage operation valid (open-collector to 3.3V with 5V VCC).

### Sections 12, 13: Manufacturing Files (Agent 10) — FAIL

**Gerbers:** All present and fresh for control (4-layer), main (4-layer), faceplate (2-layer). Dimensions match board-config.json.

**BOM/CPL:** 62 SMD components on control, 149 on main. All LCSC numbers valid. Designators match between BOM and CPL. Rotations verified for all IC packages.

**Silkscreen failures:**
- OPA4171A TSSOP-14 (5 ICs): no pin 1 marker, only body outline.
- 74HC165D SOIC-16 (5 ICs): no pin 1 marker, only body outline.
- AMS1117-3.3 SOT-223 (1 IC): no silkscreen at all.
- Total: 11 ICs without pin 1 orientation markers.

Board identification present: "requencer control proto001" and "requencer main proto001" on B.SilkS.
Eurorack power header fully labeled (-12V/GND/+12V/+5V).

### Section 15: Bring-Up Plan (Agent 12) — WARN

**Risk Level: HIGH** — Multiple FAILs from Agent 6 (decoupling placement) and Agent 10 (missing pin 1 markers).

5-phase bring-up sequence defined with all agent findings incorporated as RISK items at relevant phases. Key workarounds:
- Prepare 100nF 0402/0603 caps for tack-soldering near ICs if noise issues arise.
- Verify all 11 unmarked IC orientations under microscope before power-on.
- If I2C fails, reduce to 100kHz or replace 4.7k pull-ups with 2.2k.

SWD debug header present and accessible. BOOTSEL button provides secondary programming path. No dedicated power rail test points (prototype acceptable).

### Section 17: Documentation (Agent 11) — WARN

All 25 active components have READMEs with datasheet links. All footprints and symbols present. No orphan components.

Stale documentation:
- PJS008U README claims card detect switch (part has none).
- button-scan.ato comments say 34 buttons (36 instantiated).
- Components README lists TactileSwitch as THT (is SMD).
- PinHeader1x3 missing from catalog.

LCSC spot-check: 8/8 parts resolved correctly. OPA4171AIPWR stock critically low (2 units).

## Bring-Up Plan

**Risk Level: HIGH**

### Equipment Checklist
- Current-limited dual-rail bench supply
- Multimeter (V, Ω, diode mode)
- Oscilloscope (≥50MHz, 2ch)
- SWD debugger (RP2350-compatible)
- Pre-built firmware (blinky + full)
- Eurorack 16-pin power cable
- USB-C data cable
- MIDI TRS Type A cable + source
- 3.5mm patch cables (×6)
- USB microscope (≥10x)
- MicroSD card (FAT32)
- IR thermometer

### Phase Sequence
1. Visual inspection — verify all 11 unmarked ICs, continuity checks
2. Power supply — main board only, measure all rails, check thermals
3. MCU alive — SWD flash, blinky test, USB enumeration
4. Board-to-board — connect control board, re-verify rails
5. Peripherals — display → buttons → LEDs → encoders → DAC → MIDI → clock/reset → CV → SD

### Critical Workarounds
- **Decoupling:** Have 10+ 100nF 0402 caps ready. Tack-solder near PGA2350, DAC80508, OPA4171A if noise/instability observed.
- **IC orientation:** Verify all OPA4171A, 74HC165D, AMS1117 orientations against datasheet before power-on. Reversed ICs will short power rails.
- **I2C:** If LED drivers fail to communicate, reduce to 100kHz or swap 4.7k pull-ups for 2.2k.
- **Parts:** Order OPA4171AIPWR and DAC80508ZRTER immediately — stock critically low.

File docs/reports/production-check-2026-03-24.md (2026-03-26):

# Production Validation Report — Requencer
**Date:** 2026-03-24
**Verdict:** DO NOT MANUFACTURE

## Summary

| # | Section | Agent | Verdict | Issues |
|---|---|---|---|---|
| 0 | Component & Footprint Audit | footprint-audit | WARN | 7 missing 3D model refs, 3 manufacturer mismatches |
| 1 | GPIO Function-Select | gpio-pin-compat | PASS | — |
| 2 | Connector Pin Matching | connector-stacking | PASS | — |
| 3 | Signal Path Integrity | signal-path | WARN | MIDI CA-033 resistors, SD card detect unconnected, encoder debounce 10nF, NPN no base-emitter R |
| 4 | Power Supply | power-supply | PASS | — |
| 5 | Component-Purpose Fitness | signal-path | WARN | (covered by signal-path agent above) |
| 6 | Multi-Button Input | button-scan | PASS | — |
| 7 | Routing Quality | pcb-layout | WARN | USB traces 0.1mm, GND stitching vias sparse, bypass caps too far from ICs |
| 8 | Firmware-Pin Compat | gpio-pin-compat | PASS | — |
| 9 | Parts Availability | parts-sourcing | WARN | DAC80508 137 units, OPA4171 370 units, 7 extended parts |
| 10 | Mechanical Fit | mechanical-fit | WARN | Board stacking needs 3D verification |
| 11 | Datasheet Compliance | datasheet-compliance | **FAIL** | **IS31FL3216A R_EXT = 3.3kohm → 509mA/ch (should be ~73kohm)** |
| 12 | Manufacturing Output | manufacturing-files | WARN | Missing pin 1 dots on QFN/TSSOP/SOIC footprints |
| 13 | Silkscreen & Markings | manufacturing-files | WARN | ShroudedHeader2x16 lacks "1" label |
| 14 | EMC & Analog Noise | pcb-layout | WARN | Signal traces under OPA4171, no bulk caps at B2B connectors |
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

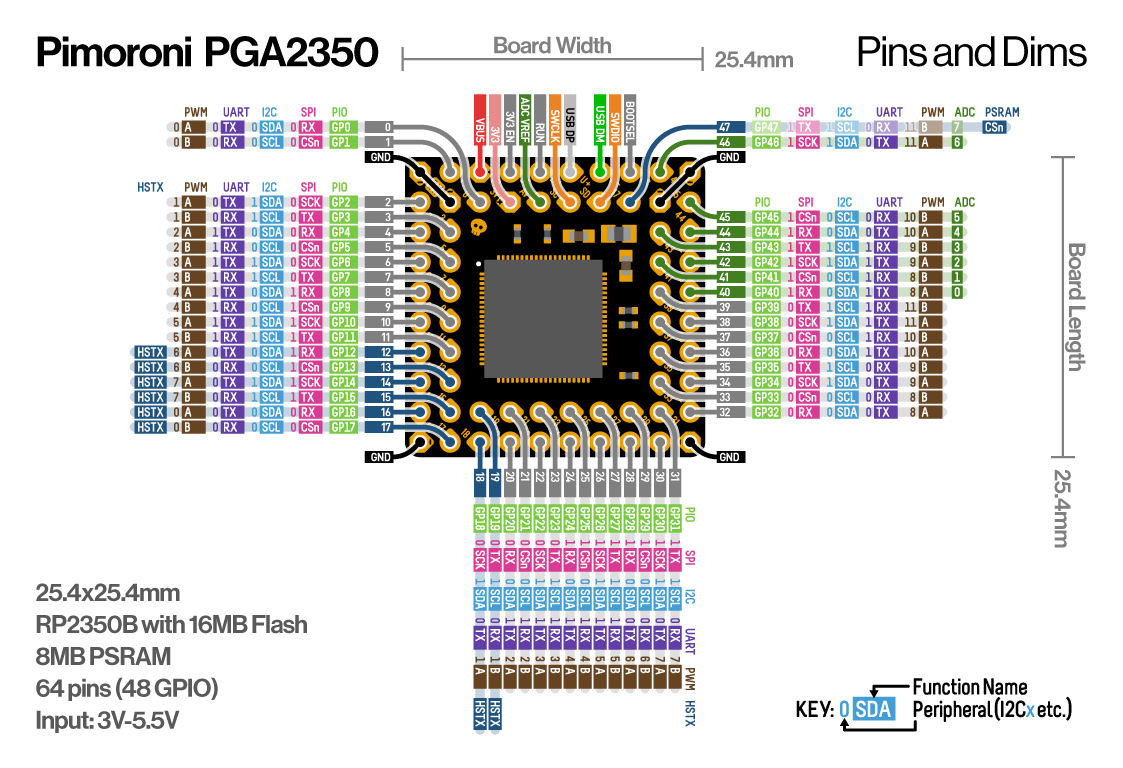
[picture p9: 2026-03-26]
hardware/boards/elec/src/components/PGA2350/docs/pga2350-pinout-diagram.png

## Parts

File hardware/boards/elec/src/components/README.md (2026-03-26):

# Parts Catalog

All custom components used in the Requencer. Standard passives (resistors, capacitors) are handled by atopile's stdlib and not listed here.

## Active Parts

### ICs

| Part | Description | Package | Board | Docs |
|---|---|---|---|---|
| [PGA2350](PGA2350/) | RP2350B MCU module (Pimoroni) | Pin Grid Array | Main | [README](PGA2350/README.md) |
| [DAC80508ZRTER](DAC80508ZRTER/) | 16-bit 8-channel DAC | WQFN-16 | Main | [README](DAC80508ZRTER/README.md) |
| [OPA4171AIPWR](OPA4171AIPWR/) | Quad precision op-amp | TSSOP-14 | Main | [README](OPA4171AIPWR/README.md) |
| [IS31FL3216A](IS31FL3216A/) | 16-ch I2C LED driver | QFN-28 | Control | [README](IS31FL3216A/README.md) |
| [74HC165D](74HC165D/) | 8-bit shift register | SOIC-16 | Control | [README](74HC165D/README.md) |
| [H11L1S](H11L1S/) | Schmitt trigger optocoupler | SOP-6 | Control | [README](H11L1S/README.md) |
| [AMS1117-3.3](AMS1117-3.3/) | 3.3V LDO regulator | SOT-223 | Main | [README](AMS1117-3.3/README.md) |
| [PRTR5V0U2X](PRTR5V0U2X/) | USB ESD protection | SOT-143B | Main | [README](PRTR5V0U2X/README.md) |

### Connectors

| Part | Description | Type | Board | Docs |
|---|---|---|---|---|
| [WQP518MA](WQP518MA/) | 3.5mm mono jack (Thonkiconn) | THT | Control | [README](WQP518MA/README.md) |
| [PJ366ST](PJ366ST/) | 3.5mm TRS stereo jack (MIDI) | THT | Control | [README](PJ366ST/README.md) |
| [PJS008U](PJS008U/) | Micro SD card socket | THT | Control | [README](PJS008U/README.md) |
| [EC11E](EC11E/) | Rotary encoder with switch | THT | Control | [README](EC11E/README.md) |
| [FPC_32P_05MM](FPC_32P_05MM/) | 32-pin FPC connector (display) | SMD | Control | [README](FPC_32P_05MM/README.md) |
| ~~FPC_18P_05MM~~ | *(archived)* | — | — | Replaced by FPC_32P_05MM |
| [ShroudedHeader2x16](ShroudedHeader2x16/) | 2×16 board-to-board header | THT | Both | [README](ShroudedHeader2x16/README.md) |
| [ShroudedSocket2x16](ShroudedSocket2x16/) | 2×16 board-to-board socket | THT | Both | [README](ShroudedSocket2x16/README.md) |
| [EurorackPowerHeader16](EurorackPowerHeader16/) | 16-pin eurorack power header | THT | Main | [README](EurorackPowerHeader16/README.md) |
| [USB_C_Receptacle](USB_C_Receptacle/) | USB Type-C connector | SMD | Main | [README](USB_C_Receptacle/README.md) |

### Switches & LEDs

| Part | Description | Type | Board | Docs |
|---|---|---|---|---|
| [PB6149L](PB6149L/) | LED illuminated pushbutton | THT | Control | [README](PB6149L/README.md) |
| [TactileSwitch](TactileSwitch/) | Tactile push button (reset) | SMD | Main | [README](TactileSwitch/README.md) |

### Discrete Semiconductors

| Part | Description | Package | Board | Docs |
|---|---|---|---|---|
| [BAT54S](BAT54S/) | Dual Schottky diode | SOT-23 | Main | [README](BAT54S/README.md) |
| [B5819W](B5819W/) | Schottky diode | SOD-123 | Both | [README](B5819W/README.md) |
| [2N3904](2N3904/) | NPN transistor | SOT-23 | Main | [README](2N3904/README.md) |
| [2N7002](2N7002/) | N-channel MOSFET | SOT-23 | Control | [README](2N7002/README.md) |

### Debug Headers

| Part | Description | Type | Board | Docs |
|---|---|---|---|---|
| [PinHeader1x3](PinHeader1x3/) | 1×3 pin header (SWD debug) | THT | Main | — |

### Passive Arrays

| Part | Description | Package | Board | Docs |
|---|---|---|---|---|
| [ResArray4x0603](ResArray4x0603/) | 4-element resistor array | 0612 | Control | [README](ResArray4x0603/README.md) |
| ~~ResistorNetwork9~~ | *(archived)* | — | — | Replaced by ResArray4x0603 |

## [Archived Parts](_archive/)

Parts fully replaced and removed from the design. See [archive README](_archive/README.md) for replacement history.

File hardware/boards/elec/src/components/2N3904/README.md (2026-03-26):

# 2N3904 — NPN Transistor

## Overview
General-purpose NPN transistor in SOT-23 package. Used for clock output buffer (3.3V to 5V gate level shifting).

## Key Specifications
| Parameter | Value |
|---|---|
| Package | SOT-23 |
| LCSC | C20526 (JLCPCB basic) |
| MPN | MMBT3904 (Changjiang/CJ) |

## Datasheet
- [LCSC page](https://www.lcsc.com/product-detail/C20526.html)

## Used In
- [`main.ato`](../boards/main/main.ato) — clock output level shifter

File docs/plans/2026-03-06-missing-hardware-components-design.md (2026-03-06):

# Missing Hardware Components Design

Date: 2026-03-06

## Context

After upgrading to atopile 0.14 and running the full hardware build pipeline, three categories of missing components were identified:

1. Panel features defined in `panel-layout.json` but absent from the schematic (Settings button, RST OUT jack)
2. LCD display has no physical connector
3. Custom IC parts lack `is_atomic_part` traits required by atopile 0.14's picker

Board dimensions: 182.88mm x 128.5mm (36HP eurorack 3U).

## 1. Settings Button — Direct GPIO (GP23)

The settings button is wired directly to GP23 rather than through the shift register chain. All 32 bits of the 4x 74HC165D chain are already allocated.

- TC002-RGB physical button (same as all other panel buttons)
- GP23 with 10k pull-up to 3.3V + 100nF debounce cap to GND
- Switch pins: one to GP23, other to GND
- **No LED wiring** — all 96 TLC5947 channels (4x 24ch) are fully allocated

### LED limitation and future expansion

The 4x TLC5947 chain provides exactly 96 PWM channels, allocated as:

| Driver | Channels | Assignment |
|---|---|---|
| TLC1 | 0-23 | Step buttons 1-8 (3 RGB channels each) |
| TLC2 | 0-23 | Step buttons 9-16 |
| TLC3 | 0-23 | Track T1-T4 + subtrack GATE/PITCH/VEL/MOD |
| TLC4 | 0-23 | PAT, MUTE, ROUTE, DRIFT, XPOSE, VAR, PLAY, RESET |

To add an LED to the settings button (or any future buttons), a **5th TLC5947** would be needed on the daisy chain. This is a straightforward addition — the TLC5947 supports arbitrary chain length via SIN/SOUT, and the existing SPI wiring (SIN, SCLK, XLAT, BLANK) extends to additional chips. A 5th chip would provide 24 more channels (enough for 8 RGB buttons).

## 2. RST OUT Jack — Buffered Output (GP24)

Same transistor buffer circuit as the existing CLK OUT:

- GP24 drives 2N3904 base through 1k resistor
- Collector pulled up to +5V through 1k resistor, connected to PJ398SM jack tip
- Emitter to GND
- Jack sleeve to GND

Panel position already defined in `panel-layout.json` at (170.55, 29.00).

## 3. LCD Connector — 9-pin 2.54mm Header

Generic 1x9 male pin header for ST7796 3.5" SPI TFT module.

| Pin | Signal | Source |
|-----|---|---|
| 1 | VCC | +3.3V rail |
| 2 | GND | Ground |
| 3 | CS | GP1 (lcd_cs) |
| 4 | RESET | GP4 (lcd_rst) |
| 5 | DC | GP3 (lcd_dc) |
| 6 | MOSI | GP0 (spi_mosi) |
| 7 | SCK | GP2 (spi_sck) |
| 8 | LED | Q_BL drain (backlight MOSFET) |
| 9 | MISO | Unconnected (not used by display) |

## 4. Fix Custom Part Footprints

Atopile 0.14 requires `is_atomic_part` traits on custom components for the picker to assign footprints. The following 9 parts need updating:

- 74HC165D (4 instances — shift registers)
- TLC5947DAP (4 instances — LED drivers)
- OPA4172ID (4 instances — op-amps)
- DAC8568SPMR (2 instances — DACs)
- 6N138 (1 instance — MIDI optocoupler)
- 2N3904 (1+1 instances — clock buffer + new RST OUT buffer)
- AMS1117-3.3 (1 instance — 3.3V regulator)
- AZ1117IH-5.0 (1 instance — 5V regulator)
- BAT54S (6 instances — input protection)

Each part needs the `is_atomic_part` trait with manufacturer, part number, and footprint references, following the pattern established by `RaspberryPiPico2.ato`.

## GPIO Allocation After Changes

| GPIO | Function | Notes |
|---|---|---|
| GP0-GP22 | Existing | SPI, LCD, DAC, buttons, LEDs, encoders, MIDI |
| GP23 | Settings button | New — direct GPIO with pull-up |
| GP24 | RST OUT | New — transistor buffer |
| GP25 | **Free** | Available for future use (e.g. external storage CS) |
| GP26-GP28 | Existing | CLK IN, RST IN, CLK OUT (ADC-capable) |

## Files to Modify

- `hardware/elec/src/mcu.ato` — add GP23, GP24 signals
- `hardware/elec/src/io-jacks.ato` — add RST OUT jack + buffer
- `hardware/elec/src/display.ato` — add 9-pin header, wire signals
- `hardware/elec/src/requencer.ato` — wire settings button + RST OUT
- `hardware/parts/PinHeader1x9/PinHeader1x9.ato` — new generic header part
- 9 existing part files in `hardware/parts/` — add `is_atomic_part` traits

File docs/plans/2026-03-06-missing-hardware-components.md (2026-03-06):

# Missing Hardware Components Implementation Plan

> **For Claude:** REQUIRED SUB-SKILL: Use superpowers:executing-plans to implement this plan task-by-task.

**Goal:** Add settings button (GP23), RST OUT jack (GP24), LCD connector (9-pin header), and fix all custom part footprint/picker traits for atopile 0.14.

**Architecture:** Three new circuits added to existing modules (mcu, io-jacks, display), one new part (pin header), and 9 existing part files updated with `is_atomic_part` + `has_part_picked` traits following the pattern established by PJ398SM/TC002-RGB/EC11E.

**Tech Stack:** Atopile 0.14, KiCad 9 (via Docker for pcbnew)

---

### Task 1: Add `is_atomic_part` traits to 74HC165D

**Files:**
- Modify: `hardware/parts/74HC165D/74HC165D.ato`

**Step 1: Add trait imports and trait lines to the component**

Replace the entire file with:

```
# 74HC165D — NXP 8-bit Parallel-In Serial-Out Shift Register, SOIC-16
# LCSC: C5613

#pragma experiment("TRAITS")
import is_atomic_part
import has_designator_prefix
import has_part_picked

component _74HC165D:
    trait is_atomic_part<manufacturer="NXP", partnumber="74HC165D", footprint="74HC165D.kicad_mod", symbol="74HC165D.kicad_sym">
    trait has_designator_prefix<prefix="U">
    trait has_part_picked::by_supplier<supplier_id="lcsc", supplier_partno="C5613", manufacturer="NXP", partno="74HC165D">

    signal SH_LD ~ pin 1
    signal CLK ~ pin 2
    signal D4 ~ pin 3
    signal D5 ~ pin 4
    signal D6 ~ pin 5
    signal D7 ~ pin 6
    signal QH_N ~ pin 7
    signal GND ~ pin 8
    signal QH ~ pin 9
    signal SER ~ pin 10
    signal D0 ~ pin 11
    signal D1 ~ pin 12
    signal D2 ~ pin 13
    signal D3 ~ pin 14
    signal CLK_INH ~ pin 15
    signal VCC ~ pin 16
```

**Step 2: Verify syntax**

Run: `cd hardware && ato validate`
Expected: No syntax errors for this file.

---

### Task 2: Add `is_atomic_part` traits to TLC5947DAP

**Files:**
- Modify: `hardware/parts/TLC5947DAP/TLC5947DAP.ato`

**Step 1: Add trait imports and trait lines**

Add before line 5 (`component TLC5947DAP:`):

```
#pragma experiment("TRAITS")
import is_atomic_part
import has_designator_prefix
import has_part_picked
```

Add as first lines inside the component (after `component TLC5947DAP:`):

```
    trait is_atomic_part<manufacturer="TI", partnumber="TLC5947DAP", footprint="TLC5947DAP.kicad_mod", symbol="TLC5947DAP.kicad_sym">
    trait has_designator_prefix<prefix="U">
    trait has_part_picked::by_supplier<supplier_id="lcsc", supplier_partno="C1554203", manufacturer="TI", partno="TLC5947DAP">
```

Remove the old `designator_prefix = "U"` line at the bottom (replaced by trait).

---

### Task 3: Add `is_atomic_part` traits to OPA4172ID

**Files:**
- Modify: `hardware/parts/OPA4172ID/OPA4172ID.ato`

**Step 1: Add trait imports and trait lines**

Same pattern. LCSC: C1849436 (OPA4172IPWR TSSOP-14 variant).

Add before `component OPA4172ID:`:

```
#pragma experiment("TRAITS")
import is_atomic_part
import has_designator_prefix
import has_part_picked
```

Add as first lines inside component:

```
    trait is_atomic_part<manufacturer="TI", partnumber="OPA4172ID", footprint="OPA4172ID.kicad_mod", symbol="OPA4172ID.kicad_sym">
    trait has_designator_prefix<prefix="U">
    trait has_part_picked::by_supplier<supplier_id="lcsc", supplier_partno="C1849436", manufacturer="TI", partno="OPA4172IPWR">
```

Remove old `designator_prefix = "U"`.

---

### Task 4: Add `is_atomic_part` traits to DAC8568SPMR

**Files:**
- Modify: `hardware/parts/DAC8568SPMR/DAC8568SPMR.ato`

LCSC: C524819.

Add before `component DAC8568SPMR:`:

```
#pragma experiment("TRAITS")
import is_atomic_part
import has_designator_prefix
import has_part_picked
```

Add inside component:

```
    trait is_atomic_part<manufacturer="TI", partnumber="DAC8568SPMR", footprint="DAC8568SPMR.kicad_mod", symbol="DAC8568SPMR.kicad_sym">
    trait has_designator_prefix<prefix="U">
    trait has_part_picked::by_supplier<supplier_id="lcsc", supplier_partno="C524819", manufacturer="TI", partno="DAC8568SPMR">
```

Remove old `designator_prefix = "U"`.

---

### Task 5: Add `is_atomic_part` traits to 6N138

**Files:**
- Modify: `hardware/parts/6N138/6N138.ato`

LCSC: C571211.

Add before `component _6N138:`:

```
#pragma experiment("TRAITS")
import is_atomic_part
import has_designator_prefix
import has_part_picked
```

Add inside component:

```
    trait is_atomic_part<manufacturer="Vishay", partnumber="6N138", footprint="6N138.kicad_mod", symbol="6N138.kicad_sym">
    trait has_designator_prefix<prefix="U">
    trait has_part_picked::by_supplier<supplier_id="lcsc", supplier_partno="C571211", manufacturer="Vishay", partno="6N138">
```

Remove old `designator_prefix = "U"`.

---

### Task 6: Add `is_atomic_part` traits to 2N3904

**Files:**
- Modify: `hardware/parts/2N3904/2N3904.ato`

LCSC: C18536.

Add before `component _2N3904:`:

```
#pragma experiment("TRAITS")
import is_atomic_part
import has_designator_prefix
import has_part_picked
```

Add inside component:

```
    trait is_atomic_part<manufacturer="Changjiang Electronics", partnumber="2N3904", footprint="2N3904.kicad_mod", symbol="2N3904.kicad_sym">
    trait has_designator_prefix<prefix="Q">
    trait has_part_picked::by_supplier<supplier_id="lcsc", supplier_partno="C18536", manufacturer="Changjiang Electronics", partno="2N3904">
```

Remove old `designator_prefix = "Q"`.

---

### Task 7: Add `is_atomic_part` traits to AMS1117-3.3

**Files:**
- Modify: `hardware/parts/AMS1117-3.3/AMS1117-3.3.ato`

LCSC: C6186.

Add before `component AMS1117_3V3:`:

```
#pragma experiment("TRAITS")
import is_atomic_part
import has_designator_prefix
import has_part_picked
```

Add inside component:

```
    trait is_atomic_part<manufacturer="AMS", partnumber="AMS1117-3.3", footprint="AMS1117-3.3.kicad_mod", symbol="AMS1117-3.3.kicad_sym">
    trait has_designator_prefix<prefix="U">
    trait has_part_picked::by_supplier<supplier_id="lcsc", supplier_partno="C6186", manufacturer="AMS", partno="AMS1117-3.3">
```

Remove old `designator_prefix = "U"`.

---

### Task 8: Add `is_atomic_part` traits to AZ1117IH-5.0

**Files:**
- Modify: `hardware/parts/AZ1117IH-5.0/AZ1117IH-5.0.ato`

LCSC: C108496.

Add before `component AZ1117_5V0:`:

```
#pragma experiment("TRAITS")
import is_atomic_part
import has_designator_prefix
import has_part_picked
```

Add inside component:

```
    trait is_atomic_part<manufacturer="Diodes Inc", partnumber="AZ1117IH-5.0", footprint="AZ1117IH-5.0.kicad_mod", symbol="AZ1117IH-5.0.kicad_sym">
    trait has_designator_prefix<prefix="U">
    trait has_part_picked::by_supplier<supplier_id="lcsc", supplier_partno="C108496", manufacturer="Diodes Inc", partno="AZ1117IH-5.0TRG1">
```

Remove old `designator_prefix = "U"`.

---

### Task 9: Add `is_atomic_part` traits to BAT54S

**Files:**
- Modify: `hardware/parts/BAT54S/BAT54S.ato`

LCSC: C83935.

Add before `component BAT54S:`:

```
#pragma experiment("TRAITS")
import is_atomic_part
import has_designator_prefix
import has_part_picked
```

Add inside component:

```
    trait is_atomic_part<manufacturer="Nexperia", partnumber="BAT54S", footprint="BAT54S.kicad_mod", symbol="BAT54S.kicad_sym">
    trait has_designator_prefix<prefix="D">
    trait has_part_picked::by_supplier<supplier_id="lcsc", supplier_partno="C83935", manufacturer="Nexperia", partno="BAT54S,215">
```

Remove old `designator_prefix = "D"`.

---

### Task 10: Build checkpoint — verify part traits work

**Step 1: Run ato build**

Run: `export PATH="$HOME/.local/bin:$PATH" && cd hardware && ato build --build default --frozen`

Expected: Build succeeds. The "No pickers and no footprint" warnings for sr1-sr4, tlc1-tlc4, opamp1-opamp4, dac1-dac2, opto, q_clk, reg_3v3, reg_5v, and BAT54S instances should be gone or reduced.

**Step 2: Check remaining warnings**

If some parts still warn about missing footprints, it may be because atopile couldn't download from LCSC (network issue or part number mismatch). Note which ones fail — they may need local `.kicad_sym`/`.kicad_mod` files created manually.

---

### Task 11: Add GP23 and GP24 signals to MCU module

**Files:**
- Modify: `hardware/elec/src/mcu.ato`

**Step 1: Add new signal declarations**

After line 56 (`signal clk_out    # GP28`), add:

```
    # Settings button (direct GPIO)
    signal settings_btn  # GP23

    # Reset output
    signal rst_out       # GP24
```

**Step 2: Add GPIO pin assignments**

After line 105 (`pico.GP28_ADC2 ~ clk_out`), add:

```
    pico.GP23 ~ settings_btn
    pico.GP24 ~ rst_out
```

---

### Task 12: Add RST OUT jack and buffer to IOJacks

**Files:**
- Modify: `hardware/elec/src/io-jacks.ato`

**Step 1: Add rst_out_gpio signal**

After line 38 (`signal clk_out_gpio   # From Pico GP28`), add:

```
    signal rst_out_gpio   # From Pico GP24
```

**Step 2: Add RST OUT circuit after the CLK OUT section (after line 140)**

Add after line 140 (`j_clk_out.SLEEVE ~ gnd`):

```

    # --- Reset Output Jack ---
    # Same transistor buffer as CLK OUT
    j_rst_out = new PJ398SM
    q_rst = new _2N3904

    r_rst_base = new Resistor
    r_rst_base.resistance = 1kohm +/- 5%

    r_rst_collector = new Resistor
    r_rst_collector.resistance = 1kohm +/- 5%

    rst_out_gpio ~ r_rst_base.unnamed[0]
    r_rst_base.unnamed[1] ~ q_rst.BASE
    q_rst.EMITTER ~ gnd
    v5v ~ r_rst_collector.unnamed[0]
    r_rst_collector.unnamed[1] ~ q_rst.COLLECTOR
    q_rst.COLLECTOR ~ j_rst_out.TIP
    j_rst_out.SLEEVE ~ gnd
```

---

### Task 13: Create PinHeader1x9 part

**Files:**
- Create: `hardware/parts/PinHeader1x9/PinHeader1x9.ato`

**Step 1: Create directory and .ato file**

```
# PinHeader1x9 — Generic 1×9 Male Pin Header, 2.54mm, Through-Hole
# Used for LCD module connector

#pragma experiment("TRAITS")
import is_atomic_part
import has_designator_prefix
import has_part_picked

component PinHeader1x9:
    trait is_atomic_part<manufacturer="Generic", partnumber="PinHeader_1x9_P2.54mm", footprint="PinHeader1x9.kicad_mod", symbol="PinHeader1x9.kicad_sym">
    trait has_designator_prefix<prefix="J">
    trait has_part_picked::by_supplier<supplier_id="lcsc", supplier_partno="C124413", manufacturer="BOOMELE", partno="C124413">

    signal PIN1 ~ pin 1
    signal PIN2 ~ pin 2
    signal PIN3 ~ pin 3
    signal PIN4 ~ pin 4
    signal PIN5 ~ pin 5
    signal PIN6 ~ pin 6
    signal PIN7 ~ pin 7
    signal PIN8 ~ pin 8
    signal PIN9 ~ pin 9
```

---

### Task 14: Add LCD header to DisplayConnector module

**Files:**
- Modify: `hardware/elec/src/display.ato`

**Step 1: Add header import and instance**

After line 3 (`import MOSFET`), add:

```
from "../../parts/PinHeader1x9/PinHeader1x9.ato" import PinHeader1x9
```

**Step 2: Add header instance and wiring**

After line 50 (`c_lcd.unnamed[1] ~ gnd`), add:

```

    # --- Physical LCD connector (9-pin header) ---
    header = new PinHeader1x9

    # Pin 1: VCC
    header.PIN1 ~ vcc
    # Pin 2: GND
    header.PIN2 ~ gnd
    # Pin 3: CS
    header.PIN3 ~ cs
    # Pin 4: RESET
    header.PIN4 ~ rst
    # Pin 5: DC
    header.PIN5 ~ dc
    # Pin 6: MOSI
    header.PIN6 ~ mosi
    # Pin 7: SCK
    header.PIN7 ~ sck
    # Pin 8: LED (backlight — connects to MOSFET drain)
    header.PIN8 ~ q_bl.drain
    # Pin 9: MISO (not connected in current design)
    signal miso
    header.PIN9 ~ miso
```

---

### Task 15: Add settings button and RST OUT wiring to top-level Requencer

**Files:**
- Modify: `hardware/elec/src/requencer.ato`

**Step 1: Add settings button imports and instance**

After line 14 (`from "../../parts/EC11E/EC11E.ato" import EC11E`), add:

```
from "../../parts/TC002-RGB/TC002-RGB.ato" import TC002_RGB
```

After line 33 (`enc_b = new EC11E`), add:

```

    # Settings button (direct GPIO, no LED)
    btn_settings = new TC002_RGB
```

**Step 2: Add settings button wiring**

After the encoder debounce caps section (after line 307, `c_enc_b_b.unnamed[1] ~ gnd`), add:

```

    # === SETTINGS BUTTON (direct GPIO) ===
    # Pull-up resistor
    r_settings_pu = new Resistor
    r_settings_pu.resistance = 10kohm +/- 5%
    r_settings_pu.unnamed[0] ~ power.v3v3
    r_settings_pu.unnamed[1] ~ mcu.settings_btn

    # Debounce cap
    c_settings = new Capacitor
    c_settings.capacitance = 100nF +/- 20%
    c_settings.unnamed[0] ~ mcu.settings_btn
    c_settings.unnamed[1] ~ gnd

    # Switch wiring (active low: press connects to GND)
    btn_settings.SW1 ~ mcu.settings_btn
    btn_settings.SW2 ~ gnd

    # LED anode to VCC (LED cathodes left unconnected — no TLC channels available)
    btn_settings.LED_ANODE ~ leds.led_vcc
```

**Step 3: Add RST OUT wiring**

After line 316 (`mcu.clk_out ~ jacks.clk_out_gpio`), add:

```
    mcu.rst_out ~ jacks.rst_out_gpio
```

---

### Task 16: Final build and verification

**Step 1: Run full ato build**

Run: `export PATH="$HOME/.local/bin:$PATH" && cd hardware && ato build --build default --frozen`

Expected: Build succeeds with fewer warnings. The new components (btn_settings, j_rst_out, lcd header) should appear in the netlist.

**Step 2: Run placement**

Run:
```bash
cp hardware/build/builds/default/backups/$(ls -t hardware/build/builds/default/backups/ | head -1) hardware/elec/layout/default/default.kicad_pcb
docker run --rm --platform linux/amd64 --entrypoint "" \
  -v $(pwd):/work -w /work \
  ghcr.io/atopile/atopile-kicad:main \
  python3 hardware/scripts/place_components.py hardware/elec/layout/default/default.kicad_pcb
```

Expected: More components placed than before (217+). New RST OUT jack and settings button should be placeable.

**Step 3: Export gerbers for visual check**

Run:
```bash
docker run --rm --platform linux/amd64 --entrypoint "" \
  -v $(pwd):/work -w /work \
  ghcr.io/atopile/atopile-kicad:main \
  python3 hardware/scripts/export_manufacturing.py hardware/elec/layout/default/default.kicad_pcb hardware/manufacturing
```

Upload `hardware/manufacturing/requencer-gerbers.zip` to KiCanvas or JLCPCB for visual verification.

**Step 4: Update placement script for new components**

The `place_components.py` script needs the RST OUT jack address mapping. Add to `utility_addr_map`:

```python
"rst_out": "jacks.j_rst_out",
```

And add settings button placement (direct address, near the transport buttons area):

```python
place("btn_settings", 135.55, 43.00)
```

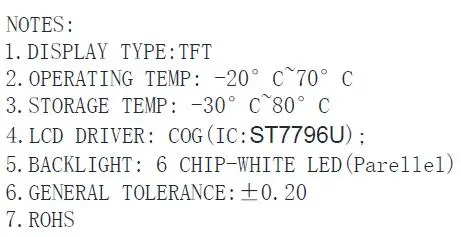
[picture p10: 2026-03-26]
hardware/boards/elec/src/components/FPC_32P_05MM/docs/tft-notes.png

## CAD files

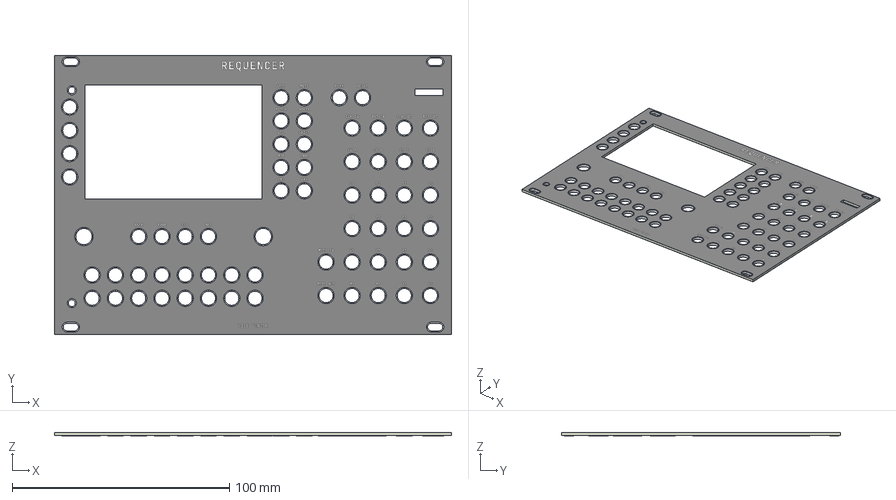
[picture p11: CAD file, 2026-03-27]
hardware/boards/build/3d/faceplate.step
182.6 x 128.5 x 1.64 mm
faceplate_pad
faceplate_silkscreen
faceplate_soldermask x 2
faceplate_PCB

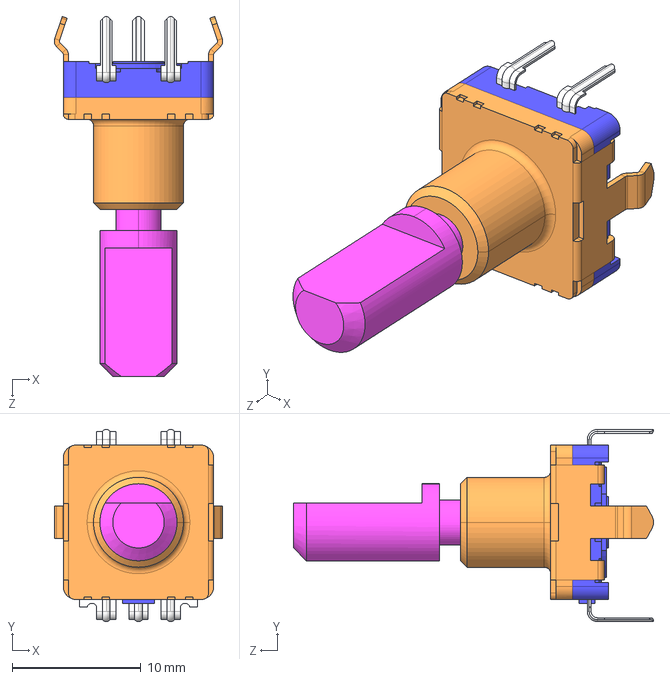
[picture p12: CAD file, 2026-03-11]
hardware/boards/elec/src/components/EC11E/EC11E.step
13.1 x 14.9 x 28.0 mm

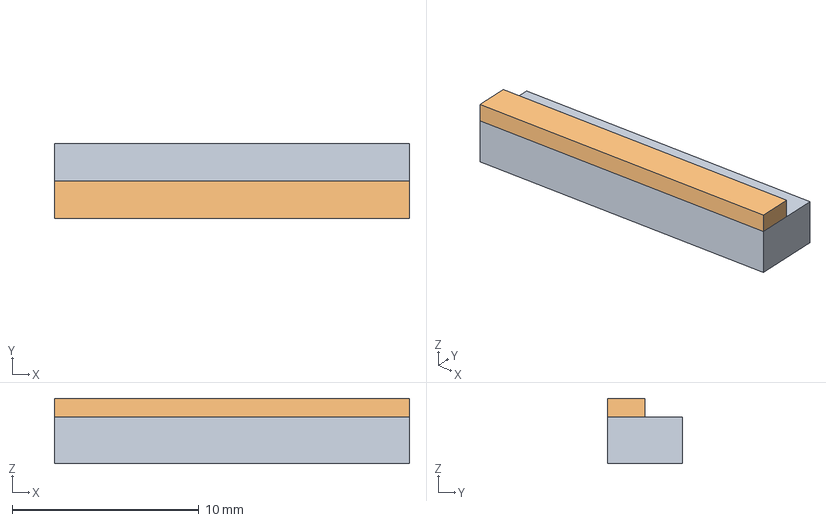
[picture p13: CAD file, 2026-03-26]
hardware/boards/elec/src/components/FPC_32P_05MM/FPC_32P_05MM.step
19.0 x 4.00 x 3.50 mm

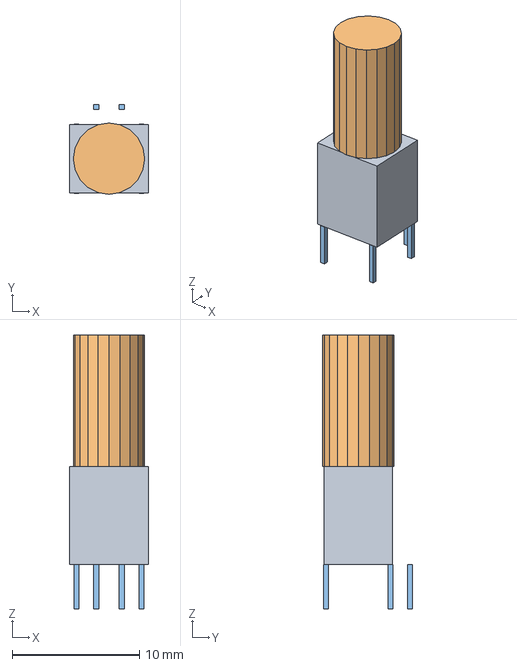
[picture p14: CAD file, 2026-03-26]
hardware/boards/elec/src/components/PB6149L/PB6149L.step
6.20 x 7.04 x 21.5 mm

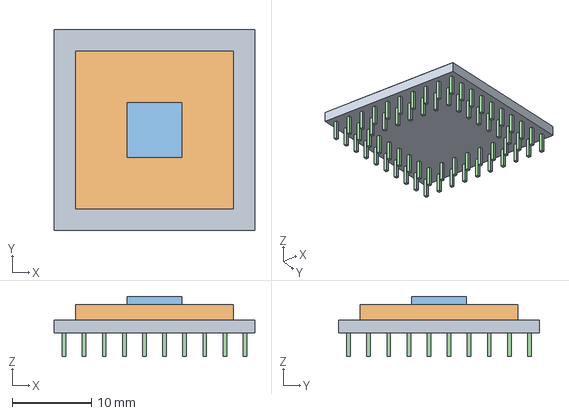
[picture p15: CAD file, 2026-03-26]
hardware/boards/elec/src/components/PGA2350/PGA2350.step
25.4 x 25.4 x 7.60 mm

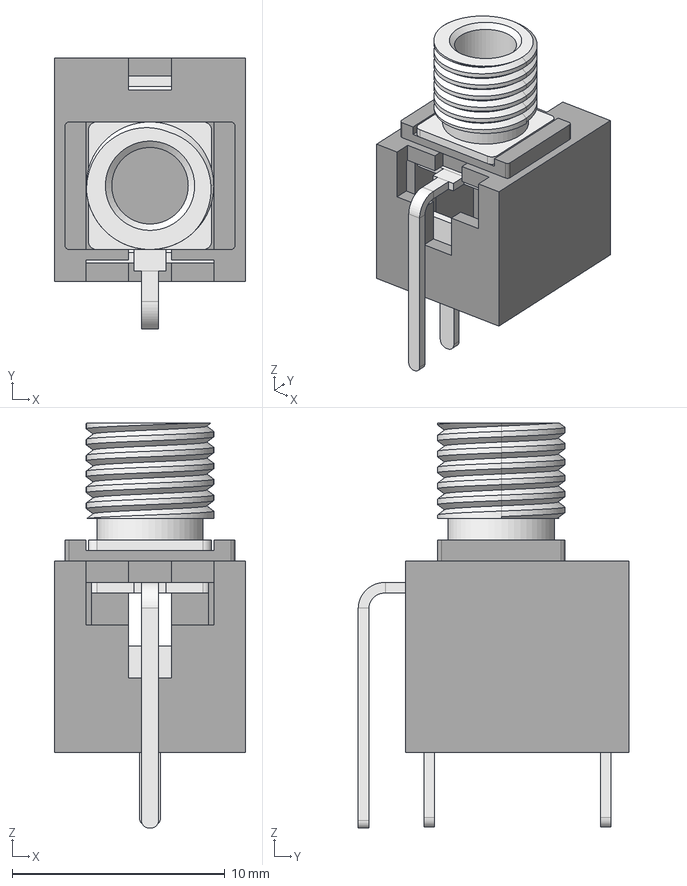
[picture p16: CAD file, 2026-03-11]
hardware/boards/elec/src/components/PJ366ST/PJ366ST.step
9.00 x 12.7 x 19.1 mm

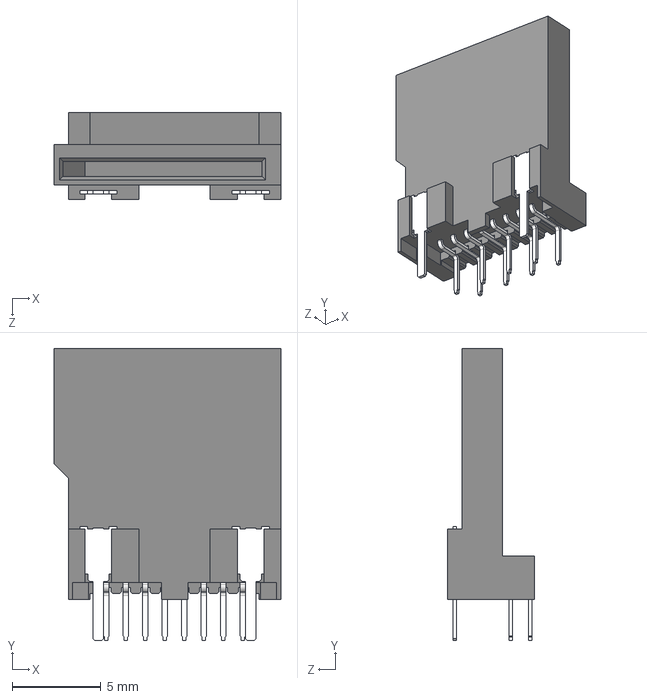
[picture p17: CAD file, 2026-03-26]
hardware/boards/elec/src/components/PJS008U/PJS008U.step
12.8 x 16.5 x 4.90 mm

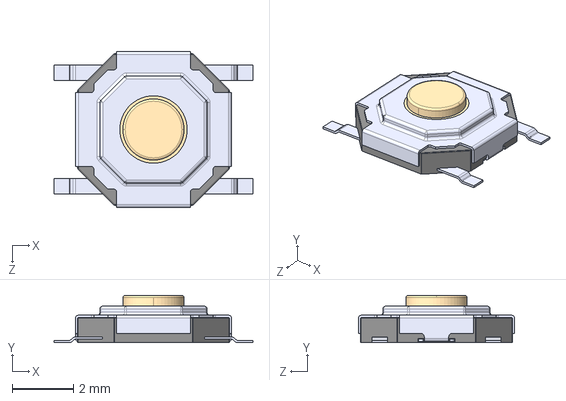
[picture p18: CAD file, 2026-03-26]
hardware/boards/elec/src/components/TactileSwitch/SW_SPST_TS1187A.step
6.50 x 1.55 x 5.10 mm

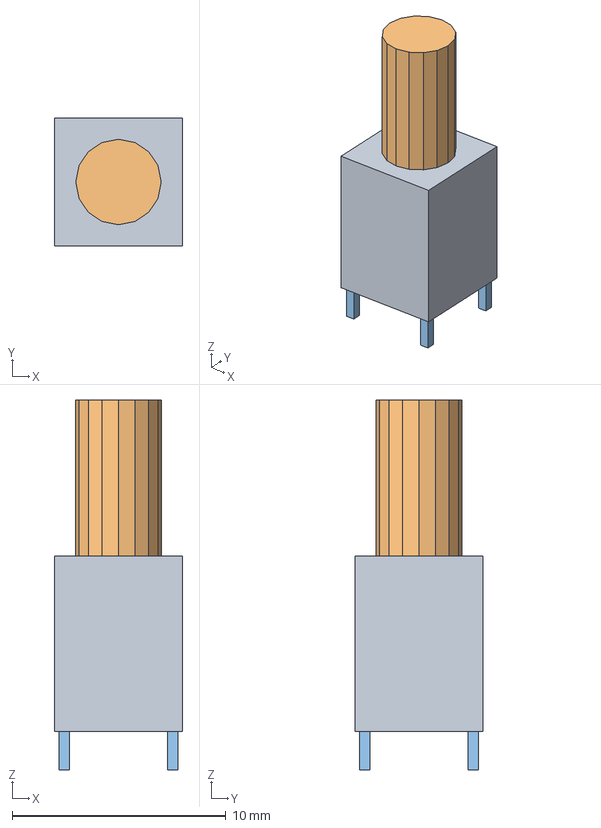
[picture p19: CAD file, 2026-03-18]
hardware/boards/elec/src/components/TC002-RGB/TC002-N11AS1XT-RGB.step
6.00 x 6.00 x 17.3 mm

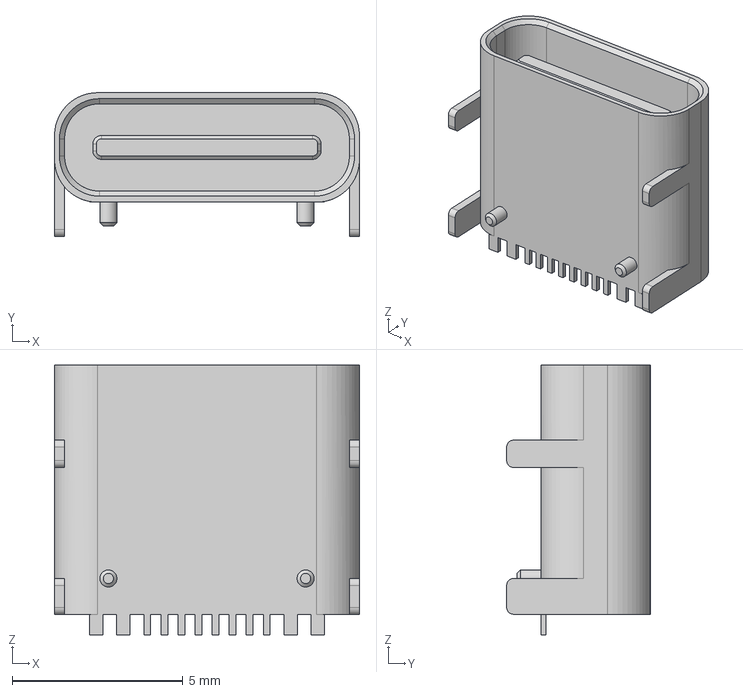
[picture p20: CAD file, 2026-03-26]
hardware/boards/elec/src/components/USB_C_Receptacle/USB_C_Receptacle.step
8.94 x 4.21 x 7.90 mm

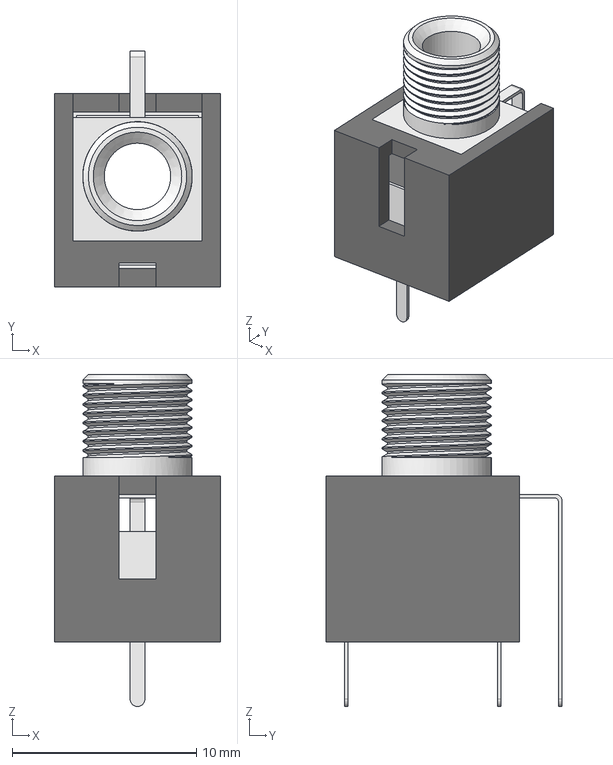
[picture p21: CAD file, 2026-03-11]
hardware/boards/elec/src/components/WQP518MA/WQP518MA_hsb.step
9.00 x 12.8 x 18.0 mm

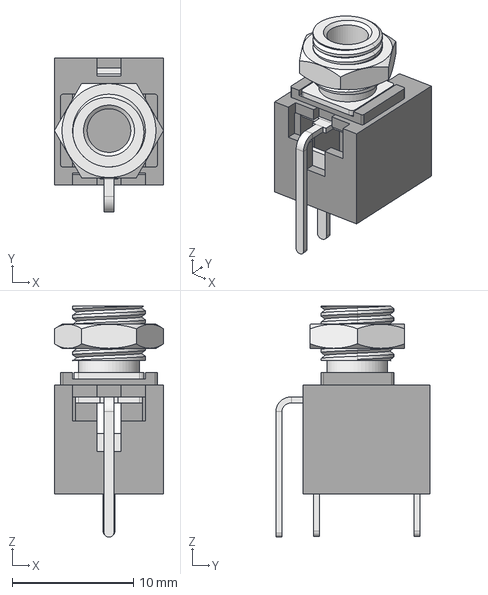
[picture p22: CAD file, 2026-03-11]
hardware/boards/elec/src/components/WQP518MA/WQP518MA_hex.step
9.00 x 12.7 x 19.1 mm

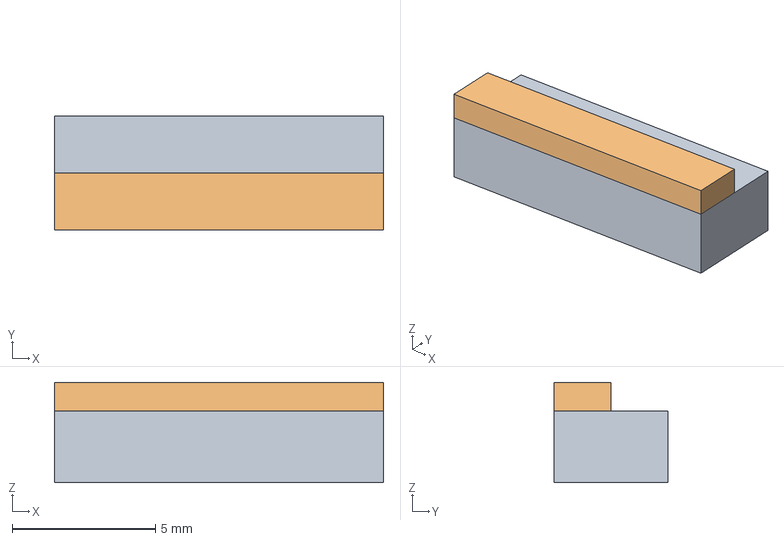
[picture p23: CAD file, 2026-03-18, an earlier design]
hardware/boards/elec/src/components/_archive/FPC_18P_05MM/FPC_18P_05MM.step
11.5 x 4.00 x 3.50 mm

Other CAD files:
hardware/boards/elec/src/components/_archive/TC002-RGB/TC002-N11AS1XT-RGB.step

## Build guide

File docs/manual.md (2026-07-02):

# Requencer Manual

A 4-track eurorack-style step sequencer. Each track generates gate, pitch,
velocity and modulation for one synth voice. The design goal: replace a live
setup of four separate sequencers plus utility modules with a single,
hands-on module built around **polymetric randomization** — quick-generate
musical patterns at independent lengths, then sculpt them while they play.

This browser version is a faithful preview of the hardware: the on-screen
panel is the real faceplate layout, and every control works with the mouse or
a touch screen.

## Quick start (mouse & touch)

- **Click** any button to press it. Click a track button (T1–T4) to select a
  track, a subtrack button (GATE/PITCH/VEL/MOD) to pick what you're editing,
  and step buttons to toggle steps.
- **Hold combos:** many functions live behind "hold this + press that".
  Press and hold one button, then press another — e.g. hold **T1** and press
  **RAND** to randomize track 1. On a touch screen, just use two fingers.
- **Double-click for sticky hold:** double-click any holdable button to lock
  it down (it stays "held" so you can work one-handed). Click it again,
  click empty space, or press `Esc` to release.
- **Encoders:** drag up/down or use the scroll wheel to turn, click to push.
  Encoder A scrolls/edits values, encoder B changes pages/parameters.
- **Transport:** the play button starts and stops the clock; reset returns
  all playheads to step 1.

Press **PLAY**, then hold **T1** and press **RAND** — you have a pattern.
Repeat for the other tracks. Everything else is sculpting.

## Tracks & subtracks

4 tracks, each with 4 independent subtracks: **gate** (rhythm), **pitch**
(melody), **velocity** (dynamics), and **mod** (modulation). Every subtrack
has its own step length (1–64) and clock divider — a track can run a 7-step
gate pattern at ÷2 alongside a 12-step pitch sequence at ÷1, creating
evolving polymetric patterns.

Hold a track button + turn encoder A to set all its subtrack lengths at
once; hold a subtrack button instead to set just that layer's length and
divider.

## Randomizer

The core workflow. Press **RAND** to open the randomizer settings for the
selected track. Quick-generate patterns with hold combos:

- **Whole track** — hold a track button (T1–T4) + press RAND to regenerate
  all four of its layers at once.
- **Single layer** — hold a subtrack button (GATE/PITCH/VEL/MOD) + press
  RAND to regenerate only that layer, e.g. a new melody over the same
  rhythm.

Each track has its own randomizer config: musical scale & root, pitch range,
max distinct notes, fill density (min/max %), velocity range, and gate mode.
Four gate algorithms:

| Mode | Character |
|---|---|
| RAND | Shuffled random fills |
| EUCL | Euclidean (evenly spread) rhythms, with random offset |
| SYNC | Offbeat-biased weighted random |
| CLST | Clustered bursts (Markov chain), with continuation probability |

8 factory presets (Bassline, Hypnotic, Acid, Ambient, Percussive, Sparse,
Stab, Driving) shape the randomizer — apply one with the encoder A push, and
save your own from the RAND screen.

## Drift

Open with the **DRIFT** button. Per-track stochastic mutation: each
subtrack has an independent drift rate that controls how quickly steps
mutate over time. Small rates slowly evolve a pattern while it plays; high
rates churn it.

## Transpose

Open with the **TRNS** button. Per-track transposition with semitone offset,
note range (low/high), and scale quantization. Transpose applies to the
pitch output in real time.

## Variation

Open with the **VAR** button. Variation layers per-bar transforms over the
selected track — reverse, rotate, stutter, thin/densify, transpose, octave
shift, accent and more — without touching the underlying pattern. With no
bar selected, push encoder A to toggle variation on or off for the track.
Select a bar with a step button, browse the transform catalog by turning
encoder B, push encoder B to add the transform, and use CLR to remove one.

## Routing

Open the route screen with the **ROUTE** button. Each track's 4 subtrack
outputs (gate/pitch/vel/mod) can be freely routed to any of the 4 output
jacks (A–D), enabling multi-voice or layered configurations.

## Mute & patterns

The **MUTE** screen toggles per-track mute patterns (with their own length
and divider). The **PAT** button opens the pattern screen for storing and
switching patterns.

## Settings

The **SET** button (jack zone) opens global settings. Clock section: BPM and
clock source (INT / MIDI / EXT). MIDI section: global MIDI on/off, device
selection, and per-output MIDI channel assignment (1–16).

## Keyboard shortcuts

Every on-screen control also has a keyboard binding, so the whole sequencer
is playable without a mouse — track buttons on `1–4`, subtracks on
`Q/W/E/R`, steps on `Z–,`, encoders on the arrow keys. Press **`?`** in the
app for the complete keymap.

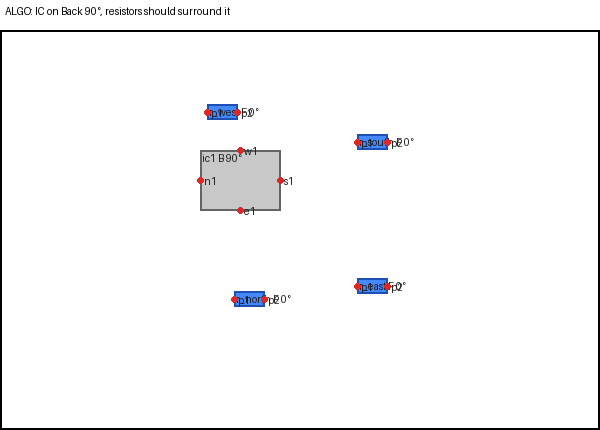
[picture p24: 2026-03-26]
hardware/boards/scripts/build/rotation_check/back_90.png

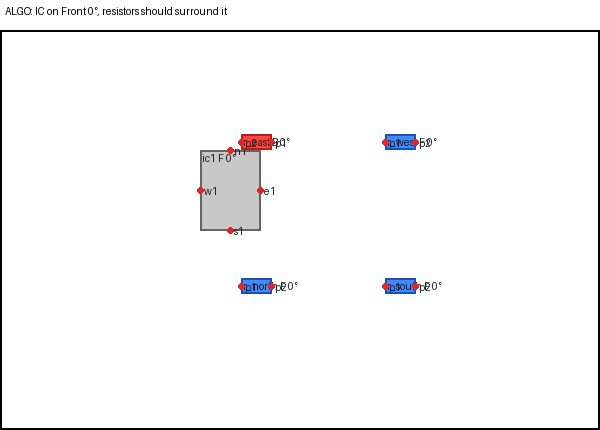
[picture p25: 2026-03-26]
hardware/boards/scripts/build/rotation_check/front_0.png

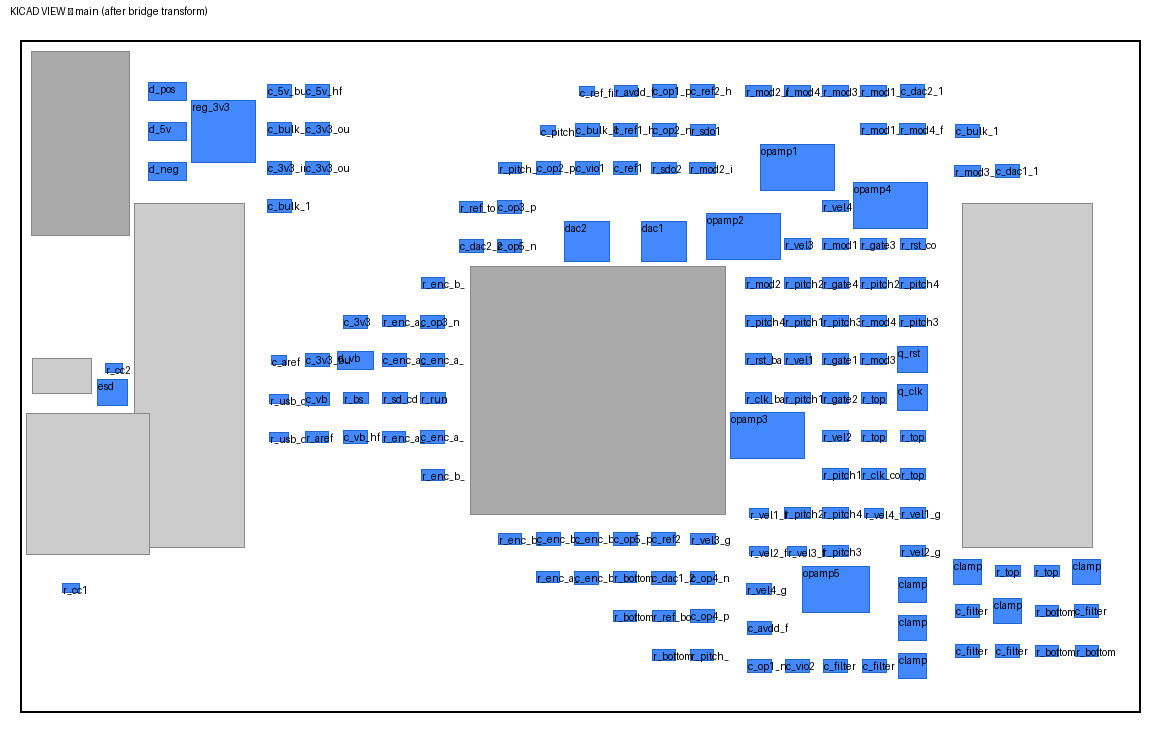
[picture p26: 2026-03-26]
hardware/boards/scripts/build/kicad_view.png

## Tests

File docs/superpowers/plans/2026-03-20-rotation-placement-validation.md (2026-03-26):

# Rotation & Placement Validation Plan

> **For agentic workers:** REQUIRED SUB-SKILL: Use superpowers:subagent-driven-development (recommended) or superpowers:executing-plans to implement this plan task-by-task. Steps use checkbox (`- [ ]`) syntax for tracking.

**Goal:** Validate that rotation, side-flipping, and pin position detection work correctly through the full pipeline: KiCad extraction → placer algorithm → KiCad application.

**Architecture:** Two layers of tests: (1) a visual diagnostic script that generates PNGs from the placer's internal state alongside kicad-cli renders of the same board, for human comparison; (2) pure Python unit tests that encode the validated expectations as assertions. The visual tests use a synthetic KiCad PCB with a handful of known components. The unit tests use synthetic `Component`/`Pin` objects with no KiCad dependency.

**Tech Stack:** Python, pytest, PIL (Pillow), kicad-cli, pcbnew (KiCad Python)

---

## File Structure

| File | Responsibility |
|---|---|
| `placer/tests/test_rotation_pipeline.py` | Pure Python unit tests for pin positions, rotation, side-flip, placement direction |
| `placer/tests/test_kicad_roundtrip.py` | KiCad-dependent tests: extract → place → re-extract, verify positions match (skips if no pcbnew) |
| `placer/tests/rotation_visual_check.py` | Standalone script (not pytest): generates comparison PNGs for human review |

All paths relative to `hardware/boards/scripts/`.

---

## Test Scenarios

Each scenario is tested on **both Front and Back** sides.

### A. Fixed component pin positions after rotation

Given: A component at a known position with rotation 0°, 90°, 180°, 270°.
Verify: Pin world positions (via `pin_world_position()`) match expected coordinates.

Example: A 4-pin IC (2mm × 3mm) with pins at known bbox-relative positions.
- Pin NW at (0.5, 0.5), Pin NE at (1.5, 0.5), Pin SE at (1.5, 2.5), Pin SW at (0.5, 2.5)
- At rotation 90° on Front: dimensions become (3mm × 2mm), pin positions rotate accordingly
- At rotation 90° on Back: mirror X first, then rotate

### B. Free component placed on correct side of fixed component

Given: A fixed IC with pins on its East edge connected to a free resistor.
Verify: The free resistor is placed to the East of the IC (not West, not overlapping).

Repeat with pins on N, S, E, W edges. Repeat on Back side.

### C. Free-to-free placement direction

Given: Two free components connected by a net. First one placed, second targeting it.
Verify: `connectivity_target` returns a position near the first component, and the second lands adjacent to it on the correct side.

### D. Free component with rotation still on correct side

Given: A free component that gets rotated (e.g., 90°). Its pins shift edges (N→W, E→N, etc.).
Verify: After rotation, `effective_edge_map` correctly reflects which pins are on which world-edge, and connectivity targeting still places neighbors on the correct side.

---

## Tasks

### Task 1: Pure Python pin position tests

**Files:**
- Create: `placer/tests/test_rotation_pipeline.py`

- [ ] **Step 1: Write failing tests for pin_world_position at all rotations on Front**

```python
"""Tests for rotation, pin positions, and placement direction."""
import pytest
from placer.dtypes import Component, Pin, Side, PlacedComponent, Net, Board
from placer.geometry import (
    pin_world_position, rotated_dims, effective_point,
    classify_pins_by_edge, effective_edge_map,
)
from placer.context import PlacementContext

def _make_ic(id="ic1", width=4.0, height=6.0, pins=None):
    """Create a 4-pin IC: pins at midpoints of each edge."""
    if pins is None:
        pins = [
            Pin(id="n1", x=2.0, y=0.0),   # N edge center
            Pin(id="s1", x=2.0, y=6.0),   # S edge center
            Pin(id="e1", x=4.0, y=3.0),   # E edge center
            Pin(id="w1", x=0.0, y=3.0),   # W edge center
        ]
    return Component(id=id, width=width, height=height, pins=pins)

def _make_resistor(id="r1", width=3.0, height=1.5, net_w="net_a", net_e="net_b"):
    """Create a 2-pin resistor: pads on W and E edges."""
    return Component(
        id=id, width=width, height=height,
        pins=[Pin(id=net_w, x=0.0, y=0.75), Pin(id=net_e, x=3.0, y=0.75)],
    )

class TestPinWorldPositionFront:
    """Verify pin world positions for all rotations on Front side."""

    def test_rotation_0(self):
        ic = _make_ic()
        # IC placed at bbox top-left (10, 20), rot=0, front
        # N pin at (2,0) relative → world (12, 20)
        wx, wy = pin_world_position(ic, ic.pins[0], 10, 20, 0.0, Side.FRONT)
        assert (wx, wy) == pytest.approx((12.0, 20.0), abs=0.01)
        # E pin at (4,3) → world (14, 23)
        wx, wy = pin_world_position(ic, ic.pins[2], 10, 20, 0.0, Side.FRONT)
        assert (wx, wy) == pytest.approx((14.0, 23.0), abs=0.01)

    def test_rotation_90(self):
        ic = _make_ic()
        # At 90° CCW, bbox becomes 6×4. Pin N (2,0) rotates.
        # rotate_point(2, 0, w=4, h=6, rot=90) → (0, 4-2) = (0, 2)
        wx, wy = pin_world_position(ic, ic.pins[0], 10, 20, 90.0, Side.FRONT)
        assert (wx, wy) == pytest.approx((10.0, 22.0), abs=0.01)

    def test_rotation_180(self):
        ic = _make_ic()
        # rotate_point(2, 0, w=4, h=6, rot=180) → (4-2, 6-0) = (2, 6)
        wx, wy = pin_world_position(ic, ic.pins[0], 10, 20, 180.0, Side.FRONT)
        assert (wx, wy) == pytest.approx((12.0, 26.0), abs=0.01)

    def test_rotation_270(self):
        ic = _make_ic()
        # rotate_point(2, 0, w=4, h=6, rot=270) → (6-0, 2) = (6, 2)
        wx, wy = pin_world_position(ic, ic.pins[0], 10, 20, 270.0, Side.FRONT)
        assert (wx, wy) == pytest.approx((16.0, 22.0), abs=0.01)

class TestPinWorldPositionBack:
    """Verify pin positions on Back side (mirror X, then rotate)."""

    def test_back_rotation_0(self):
        ic = _make_ic()
        # Back: mirror X first. Pin N at (2,0) → mirror → (4-2, 0) = (2, 0)
        # Then rotate 0° → (2, 0). World: (12, 20)
        wx, wy = pin_world_position(ic, ic.pins[0], 10, 20, 0.0, Side.BACK)
        assert (wx, wy) == pytest.approx((12.0, 20.0), abs=0.01)

    def test_back_rotation_0_east_pin(self):
        ic = _make_ic()
        # E pin at (4, 3) → mirror X → (0, 3) → rotate 0° → (0, 3)
        # World: (10, 23)
        wx, wy = pin_world_position(ic, ic.pins[2], 10, 20, 0.0, Side.BACK)
        assert (wx, wy) == pytest.approx((10.0, 23.0), abs=0.01)

    def test_back_rotation_90(self):
        ic = _make_ic()
        # E pin (4,3) → mirror → (0, 3) → rotate 90° in 4×6 box
        # rotate_point(0, 3, w=4, h=6, rot=90) → (3, 4-0) = (3, 4)
        wx, wy = pin_world_position(ic, ic.pins[2], 10, 20, 90.0, Side.BACK)
        assert (wx, wy) == pytest.approx((13.0, 24.0), abs=0.01)

class TestEdgeMapRotation:
    """Verify edge classification rotates correctly."""

    def test_front_rotation_0(self):
        ic = _make_ic()
        edge_map = classify_pins_by_edge(ic)
        eff = effective_edge_map(edge_map, 0.0, Side.FRONT)
        # At 0° front, N pin stays N, E stays E, etc.
        assert len(eff["N"]) == 1
        assert eff["N"][0].id == "n1"
        assert len(eff["E"]) == 1
        assert eff["E"][0].id == "e1"

    def test_front_rotation_90(self):
        ic = _make_ic()
        edge_map = classify_pins_by_edge(ic)
        eff = effective_edge_map(edge_map, 90.0, Side.FRONT)
        # 90° CCW: N→W, E→N, S→E, W→S
        assert eff["W"][0].id == "n1"
        assert eff["N"][0].id == "e1"

    def test_back_rotation_0(self):
        ic = _make_ic()
        edge_map = classify_pins_by_edge(ic)
        eff = effective_edge_map(edge_map, 0.0, Side.BACK)
        # Back mirror: E↔W, N and S unchanged
        assert eff["W"][0].id == "e1"
        assert eff["E"][0].id == "w1"
        assert eff["N"][0].id == "n1"

class TestConnectivityTargetDirection:
    """Verify free components target the correct side of fixed components."""

    def _make_board(self, fixed_pin_edge="E", fixed_side=Side.FRONT,
                    fixed_rotation=0.0):
        """Board with one fixed IC and one free resistor connected via net_a.

        fixed_pin_edge: which edge of the IC has the connecting pin.
        """
        ic = _make_ic(id="ic1")
        ic.fixed = True
        ic.x = 50.0
        ic.y = 40.0
        ic.rotation = fixed_rotation
        ic.side = fixed_side

        resistor = _make_resistor(id="r1", net_w="net_a", net_e="net_b")

        # Net connects ic1.e1 (East pin) to r1's West pin
        net = Net(id="net_a", connections=(("ic1", "e1"), ("r1", "net_a")))

        board = Board(
            width=100.0, height=80.0,
            components=[ic, resistor],
            nets=[net],
            rotation_nets=[net],
            clearance=0.5,
        )
        return board

    def test_free_targets_east_of_fixed_front(self):
        board = self._make_board(fixed_pin_edge="E", fixed_side=Side.FRONT)
        ctx = PlacementContext(board)
        tx, ty = ctx.connectivity_target("r1", {})
        # IC is at (50, 40) with E pin at (54, 43).
        # Target should be to the right of the IC (x > 52)
        assert tx > 52.0, f"Expected target east of IC, got tx={tx}"

    def test_free_targets_east_of_fixed_back(self):
        board = self._make_board(fixed_pin_edge="E", fixed_side=Side.BACK)
        ctx = PlacementContext(board)
        tx, ty = ctx.connectivity_target("r1", {})
        # On back, E pin mirrors to W side. IC center is ~(52, 43).
        # The E pin world position after mirror: (50, 43)
        # Target should be to the LEFT of the IC (x < 52)
        assert tx < 52.0, f"Expected target west of IC on back side, got tx={tx}"
```

- [ ] **Step 2: Run tests to verify they fail**

Run: `cd hardware/boards/scripts && PYTHONPATH=. python -m pytest placer/tests/test_rotation_pipeline.py -v`
Expected: Some tests may pass (geometry is already implemented), others may fail if pin_world_position or edge_map behavior doesn't match expectations. This validates our understanding.

- [ ] **Step 3: Fix any test expectations that don't match the actual (correct) behavior**

The goal is to establish ground truth. If `rotate_point(2, 0, w=4, h=6, rot=90)` returns something different than our expectation, check the geometry code, verify it's correct, and update the test expectation. Do NOT change the geometry code to match wrong expectations.

- [ ] **Step 4: Run tests to verify all pass**

Run: `cd hardware/boards/scripts && PYTHONPATH=. python -m pytest placer/tests/test_rotation_pipeline.py -v`
Expected: All PASS

- [ ] **Step 5: Commit**

```bash
git add hardware/boards/scripts/placer/tests/test_rotation_pipeline.py
git commit -m "test: add rotation pipeline unit tests for pin positions and edge maps"
```

---

### Task 2: Visual diagnostic script for human verification

**Files:**
- Create: `placer/tests/rotation_visual_check.py`

This script creates a synthetic board with known components, runs placement, and generates:
1. **algo_view.png** — placer's internal rectangles with pin positions drawn as dots
2. **kicad_render.png** — kicad-cli render of the actual placed PCB (via pcbnew)
3. **comparison.png** — side-by-side composite

The script does NOT run as a pytest test — it's a manual visual validation tool.

- [ ] **Step 1: Write the visual check script**

```python
#!/usr/bin/env python3
"""Visual rotation check: synthetic board with known pin positions.

Creates a small KiCad PCB with a few components, runs placement,
renders both the algorithm's view and KiCad's actual rendering.

Usage:
    # From hardware/boards/scripts:
    /Applications/KiCad/KiCad.app/.../python3 -m placer.tests.rotation_visual_check

Outputs to hardware/boards/scripts/build/rotation_check/
"""
import os
import sys
import subprocess

# Needs KiCad Python
pcbnew = None
try:
    import pcbnew
except ImportError:
    print("ERROR: Requires KiCad Python (pcbnew)")
    sys.exit(1)

from PIL import Image, ImageDraw

from placer.dtypes import Component, Pin, Side, Net, Board, PlacedComponent
from placer.geometry import pin_world_position, rotated_dims
from placer.kicad_bridge import (
    extract_component, extract_nets, build_placer_board, apply_placements,
)
from placer.context import PlacementContext
from placer.strategies.wavefront import wavefront

SCRIPT_DIR = os.path.dirname(os.path.abspath(__file__))
OUT_DIR = os.path.join(SCRIPT_DIR, "..", "build", "rotation_check")

def mm_to_px(mm, scale=10.0):
    return int(mm * scale)

def render_algo_view(filename, board_w, board_h, components, placements,
                     title="", scale=10.0):
    """Render algorithm's view: bounding boxes + pin dots."""
    pw = mm_to_px(board_w, scale) + 40
    ph = mm_to_px(board_h, scale) + 60
    img = Image.new("RGB", (pw, ph), "white")
    draw = ImageDraw.Draw(img)
    ox, oy = 20, 40

    draw.text((10, 5), title, fill="black")
    draw.rectangle([ox, oy, ox + mm_to_px(board_w, scale),
                    oy + mm_to_px(board_h, scale)],
                   outline="black", width=2)

    comp_map = {c.id: c for c in components}

    for comp in components:
        if comp.fixed:
            x, y, rot, side = comp.x, comp.y, comp.rotation, comp.side
        else:
            p = placements.get(comp.id)
            if p is None:
                continue
            x, y, rot, side = p.x, p.y, p.rotation, p.side

        ew, eh = rotated_dims(comp.width, comp.height, rot)

        # Draw bbox
        px1 = ox + mm_to_px(x, scale)
        py1 = oy + mm_to_px(y, scale)
        px2 = px1 + mm_to_px(ew, scale)
        py2 = py1 + mm_to_px(eh, scale)
        color = "#cccccc" if comp.fixed else "#4488ff"
        outline = "#888888" if comp.fixed else "#2266cc"
        draw.rectangle([px1, py1, px2, py2], fill=color, outline=outline)

        # Label
        label = f"{comp.id} {'B' if side == Side.BACK else 'F'} {int(rot)}°"
        draw.text((px1 + 2, py1 + 2), label, fill="black")

        # Draw pins as colored dots
        for pin in comp.pins:
            wpx, wpy = pin_world_position(comp, pin, x, y, rot, side)
            dpx = ox + mm_to_px(wpx, scale)
            dpy = oy + mm_to_px(wpy, scale)
            r = 3
            draw.ellipse([dpx - r, dpy - r, dpx + r, dpy + r],
                         fill="red", outline="darkred")
            draw.text((dpx + 4, dpy - 6), pin.id[:6], fill="red")

    img.save(filename)
    print(f"  Saved {filename}")

def run_check():
    os.makedirs(OUT_DIR, exist_ok=True)

    # --- Test scenarios ---
    scenarios = [
        # (description, fixed_side, fixed_rotation)
        ("Front 0°", Side.FRONT, 0.0),
        ("Front 90°", Side.FRONT, 90.0),
        ("Front 180°", Side.FRONT, 180.0),
        ("Front 270°", Side.FRONT, 270.0),
        ("Back 0°", Side.BACK, 0.0),
        ("Back 90°", Side.BACK, 90.0),
        ("Back 180°", Side.BACK, 180.0),
        ("Back 270°", Side.BACK, 270.0),
    ]

    board_w, board_h = 60.0, 40.0

    for desc, fixed_side, fixed_rot in scenarios:
        tag = f"{fixed_side.value}_{int(fixed_rot)}"

        # Fixed IC in center
        ic = Component(
            id="ic1", width=6.0, height=8.0, fixed=True,
            x=20.0, y=12.0, rotation=fixed_rot, side=fixed_side,
            pins=[
                Pin(id="n1", x=3.0, y=0.0),
                Pin(id="s1", x=3.0, y=8.0),
                Pin(id="e1", x=6.0, y=4.0),
                Pin(id="w1", x=0.0, y=4.0),
            ],
        )

        # Free resistors connected to each IC pin
        r_e = Component(id="r_east", width=3.0, height=1.5,
                        pins=[Pin(id="e1", x=0.0, y=0.75),
                              Pin(id="other", x=3.0, y=0.75)])
        r_w = Component(id="r_west", width=3.0, height=1.5,
                        pins=[Pin(id="w1", x=0.0, y=0.75),
                              Pin(id="other", x=3.0, y=0.75)])
        r_n = Component(id="r_north", width=3.0, height=1.5,
                        pins=[Pin(id="n1", x=0.0, y=0.75),
                              Pin(id="other", x=3.0, y=0.75)])
        r_s = Component(id="r_south", width=3.0, height=1.5,
                        pins=[Pin(id="s1", x=0.0, y=0.75),
                              Pin(id="other", x=3.0, y=0.75)])

        nets = [
            Net(id="e1", connections=(("ic1", "e1"), ("r_east", "e1"))),
            Net(id="w1", connections=(("ic1", "w1"), ("r_west", "w1"))),
            Net(id="n1", connections=(("ic1", "n1"), ("r_north", "n1"))),
            Net(id="s1", connections=(("ic1", "s1"), ("r_south", "s1"))),
        ]

        board = Board(
            width=board_w, height=board_h,
            components=[ic, r_e, r_w, r_n, r_s],
            nets=nets, rotation_nets=nets,
            clearance=0.5,
        )

        ctx = PlacementContext(board)
        results = wavefront(board, ctx, {})
        placements = {r.component_id: r for r in results}

        render_algo_view(
            os.path.join(OUT_DIR, f"algo_{tag}.png"),
            board_w, board_h, board.components, placements,
            title=f"ALGO: IC on {desc}, resistors should surround it",
        )

    print(f"\nAll PNGs saved to {OUT_DIR}/")
    print("Verify visually:")
    print("  - Pin dots (red) should be at correct edge of IC bbox")
    print("  - Resistors should be placed near the IC edge they connect to")
    print("  - Back-side scenarios should mirror E/W pins")

if __name__ == "__main__":
    run_check()
```

- [ ] **Step 2: Run the visual check**

Run: `/opt/homebrew/bin/python3.11 -m placer.tests.rotation_visual_check` (from `hardware/boards/scripts/`)
Expected: PNGs in `build/rotation_check/`. Verify visually:
- Pin dots at correct edges
- Resistors placed near the correct IC edge
- Back-side mirrors E↔W

- [ ] **Step 3: Review and screenshot the PNGs**

Open each PNG. For each scenario, verify:
1. Red pin dots match the expected edge of the IC bounding box
2. The 4 resistors are placed near the IC edge they connect to
3. Back-side scenarios have mirrored E/W compared to front

If anything looks wrong, trace through the geometry code and fix it.

- [ ] **Step 4: Commit**

```bash
git add placer/tests/rotation_visual_check.py
git commit -m "test: add visual rotation check script for human verification"
```

---

### Task 3: KiCad roundtrip test

**Files:**
- Create: `placer/tests/test_kicad_roundtrip.py`

Tests that extract → place → apply → re-extract produces consistent positions. Uses real KiCad footprints from the control board PCB.

- [ ] **Step 1: Write the roundtrip test**

```python
"""KiCad roundtrip: extract component, apply placement, verify position.

Tests that our coordinate conversion (bbox top-left ↔ KiCad origin)
is consistent through extract → place → apply → re-extract.

Requires KiCad Python (pcbnew). Skipped if not available.
"""
import os
import pytest

pcbnew = pytest.importorskip("pcbnew")

import sys
SCRIPT_DIR = os.path.dirname(os.path.abspath(__file__))
sys.path.insert(0, os.path.join(SCRIPT_DIR, "..", ".."))

from placement.helpers import identify_power_nets
from placer.kicad_bridge import extract_component, apply_placements, _rotate_offset
from placer.geometry import rotated_dims
from placer.dtypes import PlacedComponent, Side

BOARDS_DIR = os.path.join(SCRIPT_DIR, "..", "..", "..")
CONTROL_PCB = os.path.join(BOARDS_DIR, "elec", "layout", "control", "control.kicad_pcb")

def _load_board():
    if not os.path.exists(CONTROL_PCB):
        pytest.skip(f"PCB not found: {CONTROL_PCB}")
    return pcbnew.LoadBoard(CONTROL_PCB)

def _find_fp(board, addr):
    for fp in board.GetFootprints():
        if fp.HasFieldByName("atopile_address"):
            if fp.GetFieldText("atopile_address") == addr:
                return fp
    pytest.skip(f"Footprint not found: {addr}")

@pytest.mark.parametrize("rotation", [0.0, 90.0, 180.0, 270.0])
@pytest.mark.parametrize("side", [Side.FRONT, Side.BACK])
class TestRoundtrip:
    """Extract a component, create a placement, apply it, verify position."""

    def test_resistor_roundtrip(self, rotation, side):
        """A simple 2-pad resistor survives the roundtrip."""
        board = _load_board()
        power_nets = identify_power_nets(board)

        # Find a resistor
        addr = None
        for fp in board.GetFootprints():
            if fp.HasFieldByName("atopile_address"):
                a = fp.GetFieldText("atopile_address")
                if a.startswith("r_") or ".r_" in a:
                    addr = a
                    break
        if addr is None:
            pytest.skip("No resistor found")

        fp = _find_fp(board, addr)
        bridge = extract_component(addr, fp, pcbnew, power_nets)
        comp = bridge.component

        # Create a placement at a known position
        target_x, target_y = 30.0, 25.0
        placed = PlacedComponent(
            component_id=addr,
            x=target_x, y=target_y,
            rotation=rotation,
            side=side,
        )

        # Apply placement
        apply_placements([placed], {addr: bridge}, {addr: fp}, board, pcbnew)

        # Re-extract and verify the position roundtrips
        bridge2 = extract_component(
            addr, fp, pcbnew, power_nets,
            is_fixed=True,
            fixed_x=pcbnew.ToMM(fp.GetPosition().x),
            fixed_y=pcbnew.ToMM(fp.GetPosition().y),
            fixed_side="F" if fp.GetLayer() == board.GetLayerID("F.Cu") else "B",
            fixed_rotation=fp.GetOrientationDegrees(),
        )

        # The re-extracted bbox top-left should match our original target
        assert bridge2.component.x == pytest.approx(target_x, abs=0.5)
        assert bridge2.component.y == pytest.approx(target_y, abs=0.5)
```

- [ ] **Step 2: Run the test**

Run: `cd hardware/boards/scripts && PYTHONPATH=. /Applications/KiCad/KiCad.app/Contents/Frameworks/Python.framework/Versions/Current/bin/python3 -m pytest placer/tests/test_kicad_roundtrip.py -v`
Expected: Tests pass or reveal roundtrip mismatches that need fixing.

- [ ] **Step 3: Fix any roundtrip failures**

If a rotation/side combination produces a position mismatch, the bug is in either `apply_placements` (the additive rotation logic) or `extract_component` (the bbox-from-origin conversion). Fix the code, not the test.

- [ ] **Step 4: Run tests again to verify all pass**

Expected: 8 tests pass (4 rotations × 2 sides)

- [ ] **Step 5: Commit**

```bash
git add placer/tests/test_kicad_roundtrip.py
git commit -m "test: add KiCad roundtrip test for rotation and side-flip"
```

---

### Task 4: Add KiCad render comparison to visual check

**Files:**
- Modify: `placer/tests/rotation_visual_check.py`

Extend the visual check to also produce kicad-cli SVG renders of placed boards for direct comparison with the algorithm view.

- [ ] **Step 1: Add KiCad PCB generation and rendering**

After generating the algo view PNGs, also:
1. Create a minimal `.kicad_pcb` with footprints at the placed positions
2. Run `kicad-cli pcb export svg` on it
3. Save alongside the algo PNG

This requires either creating synthetic KiCad footprints (complex) or using real footprints from an existing PCB. Use the simpler approach: generate a `.kicad_pcb` with `gr_rect` bounding boxes and pin position `gr_circle` markers on the correct layers — this gives a KiCad-rendered view without needing real footprints.

- [ ] **Step 2: Run and compare**

Open both PNGs side-by-side. The bounding boxes and pin dots should match between the algo view and the KiCad render.

- [ ] **Step 3: Commit**

```bash
git add placer/tests/rotation_visual_check.py
git commit -m "test: add kicad-cli render comparison to visual rotation check"
```

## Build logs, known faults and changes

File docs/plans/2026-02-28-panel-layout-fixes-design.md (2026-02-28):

# Panel Layout Fixes Design

## Context

Three issues with the current panel layout need fixing:
1. RESET/PLAY/RAND buttons look too similar to small buttons — need Bitbox-inspired rectangular transport buttons
2. Subtrack column (4 buttons) and feature/overlay column (3 buttons) are misaligned
3. Step grid is centered in the main-area rather than under the LCD

## Changes

### 1. Rectangular Transport Buttons

Replace circular large buttons with taller rectangular ones inspired by 1010music Bitbox modules.

- New constants: `RECT_BTN_W = 8.0 * SCALE` (36px), `RECT_BTN_H = 16.0 * SCALE` (72px)
- Remove `LARGE_BTN_D` constant (no longer circular)
- `.large-btn` CSS: `border-radius: 2mm` instead of `50%`, width/height use new rect dimensions
- All three buttons (RESET, PLAY, RAND) use the rectangular style
- Existing color/state styles preserved (transport gray, RAND darker, play green glow)
- Control strip gap adjusted for rectangular button proportions

### 2. Feature Column: 4 Rows Aligned with Subtrack Column

Add a 4th feature button to match the subtrack column's 4-button layout.

- Feature labels: `['MUTE', 'ROUTE', 'DIV/LEN', 'TBD']`
- Loop count: 3 → 4
- Both right-side columns now have identical 4-row height, aligned row-by-row
- `FaceplateElements.featureBtns` array grows from 3 to 4 elements
- TBD button has no behavior wired yet — placeholder for future feature

### 3. Step Grid Centered Under LCD

Position the step grid so it's horizontally centered under the LCD display.

- Remove `align-self: center` from `.step-grid`
- Calculate left offset = track column width + gap, then center step grid relative to LCD width
- The LCD occupies a known CSS width (`73.44 * SCALE` px + bezel padding), so the offset can be computed from constants

## Files Modified

- `src/ui/panel/faceplate.ts` — all three changes (constants, DOM generation, CSS)
- `src/ui/panel/controls.ts` — may need update if feature button count is referenced
- Tests — verify feature button array length if tested

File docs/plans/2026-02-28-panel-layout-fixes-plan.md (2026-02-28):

# Panel Layout Fixes Implementation Plan

> **For Claude:** REQUIRED SUB-SKILL: Use superpowers:executing-plans to implement this plan task-by-task.

**Goal:** Fix three panel layout issues: rectangular transport buttons, aligned 4-row columns, step grid centered under LCD.

**Architecture:** All changes are in `src/ui/panel/faceplate.ts` (constants, DOM, CSS) with a small guard fix in `src/ui/panel/controls.ts`. No engine changes. No new files.

**Tech Stack:** TypeScript, DOM, CSS-in-JS (template literal in faceplate.ts)

---

### Task 1: Rectangular Transport Button Constants

**Files:**
- Modify: `src/ui/panel/faceplate.ts:35` (replace `LARGE_BTN_D`)

**Step 1: Replace the LARGE_BTN_D constant with rectangular dimensions**

In `src/ui/panel/faceplate.ts`, replace line 35:
```typescript
const LARGE_BTN_D = 14.0 * SCALE    // 63px — large tactile button (matches encoder height)
```
with:
```typescript
const RECT_BTN_W = 8.0 * SCALE      // 36px — rectangular button width
const RECT_BTN_H = 16.0 * SCALE     // 72px — rectangular button height
```

**Step 2: Update control strip gap reference**

In the same file, line 587 references `LARGE_BTN_D` for the gap calculation:
```typescript
gap: ${Math.round(LARGE_BTN_D * 0.3)}px;
```
Replace with:
```typescript
gap: ${Math.round(RECT_BTN_W * 0.4)}px;
```

**Step 3: Run dev server and verify no build errors**

Run: `npm run build`
Expected: Build succeeds (no references to deleted `LARGE_BTN_D` remain)

Note: If build fails with "LARGE_BTN_D is not defined", search for any remaining references and update them.

**Step 4: Commit**

```bash
git add src/ui/panel/faceplate.ts
git commit -m "refactor: replace LARGE_BTN_D with RECT_BTN dimensions"
```

---

### Task 2: Rectangular Button CSS

**Files:**
- Modify: `src/ui/panel/faceplate.ts` (CSS section, lines ~656-664)

**Step 1: Update `.large-btn` CSS from circle to rectangle**

Find the `.large-btn` CSS block:
```css
.large-btn {
    width: ${LARGE_BTN_D}px;
    height: ${LARGE_BTN_D}px;
}
```
Replace with:
```css
.large-btn {
    width: ${RECT_BTN_W}px;
    height: ${RECT_BTN_H}px;
    border-radius: ${2.0 * SCALE}px;
}
```

The `.circle-btn` base class sets `border-radius: 50%` — the `.large-btn` override to `2.0 * SCALE` (9px ≈ 2mm) makes it rectangular with rounded corners.

**Step 2: Run dev server and visually verify**

Run: `npm run dev`
Expected: RESET, PLAY, RAND now appear as tall rectangles in the control strip. Labels still visible below.

**Step 3: Commit**

```bash
git add src/ui/panel/faceplate.ts
git commit -m "feat: rectangular transport buttons (Bitbox-inspired)"
```

---

### Task 3: Add 4th Feature Button (TBD)

**Files:**
- Modify: `src/ui/panel/faceplate.ts:219-220` (feature labels and loop)
- Modify: `src/ui/panel/controls.ts:201` (guard loop against FEATURE_IDS length)
- Modify: `src/ui/panel/controls.ts:375` (guard mode indicator loop)

**Step 1: Update feature labels and loop count in faceplate.ts**

In `src/ui/panel/faceplate.ts`, find:
```typescript
const featureLabels = ['MUTE', 'ROUTE', 'DIV/LEN']
for (let i = 0; i < 3; i++) {
```
Replace with:
```typescript
const featureLabels = ['MUTE', 'ROUTE', 'DIV/LEN', 'TBD']
for (let i = 0; i < 4; i++) {
```

**Step 2: Guard the feature button event loop in controls.ts**

In `src/ui/panel/controls.ts`, the loop at line 201 iterates over all `panel.featureBtns` but indexes into `FEATURE_IDS` which only has 3 entries. The 4th button (TBD) has no feature ID yet.

Find:
```typescript
for (let i = 0; i < panel.featureBtns.length; i++) {
    const btn = panel.featureBtns[i]
```
Replace with:
```typescript
for (let i = 0; i < FEATURE_IDS.length; i++) {
    const btn = panel.featureBtns[i]
```

This ensures only the first 3 feature buttons get event handlers. The 4th (TBD) is inert.

**Step 3: Guard the mode indicator loop in controls.ts**

In `src/ui/panel/controls.ts`, the `updateModeIndicators` function at line 380:
```typescript
for (let i = 0; i < featureBtns.length; i++) {
    featureBtns[i].classList.toggle('active', mode === featureModes[i])
}
```
Replace with:
```typescript
for (let i = 0; i < featureModes.length; i++) {
    featureBtns[i].classList.toggle('active', mode === featureModes[i])
}
```

This ensures only the first 3 feature buttons get mode indicators. The 4th has no mode.

**Step 4: Run build and verify**

Run: `npm run build`
Expected: No errors. The TBD button renders but has no click behavior.

**Step 5: Run dev server and visually verify**

Run: `npm run dev`
Expected: Feature column now has 4 buttons (MUTE, ROUTE, DIV/LEN, TBD) aligned with the 4 subtrack buttons.

**Step 6: Commit**

```bash
git add src/ui/panel/faceplate.ts src/ui/panel/controls.ts
git commit -m "feat: add 4th feature button (TBD) for column alignment"
```

---

### Task 4: Center Step Grid Under LCD

**Files:**
- Modify: `src/ui/panel/faceplate.ts` (CSS for `.step-grid`)

**Step 1: Calculate the LCD offset**

The step grid needs to be centered under the LCD. The LCD is positioned after:
- Track column: `BTN_D` (23px) wide
- Gap: `COMPONENT_GAP` (24px)

So the LCD's left edge is at `BTN_D + COMPONENT_GAP = 47px` from the main-area left edge.

The LCD CSS width is `73.44 * SCALE` (330px) plus bezel padding (2px + `2.0 * SCALE` = 11px each side = 22px total), giving a bezel width of ~352px. The LCD center from the main-area left edge is at `47 + 352/2 = 223px`.

The step grid width is `8 * STEP_BTN_CC - STEP_GAP = 8 * 32 - 12 = 244px` (8 buttons at 32px c-c, minus one gap since we measure edge-to-edge).

Actually the flex gap layout makes the total width = `7 * BTN_GAP + 8 * STEP_BTN_D = 7 * 25 + 8 * 20 = 175 + 160 = 335px`. Hmm, that's wider than the LCD.

Let's use a simpler approach: use CSS to offset the step grid so its center aligns with the LCD center.

**Step 2: Update step grid CSS**

Find the `.step-grid` CSS:
```css
.step-grid {
    display: flex;
    flex-direction: column;
    gap: ${BTN_GAP}px;
    align-self: center;
    margin-top: ${COMPONENT_GAP}px;
}
```

Replace with:
```css
.step-grid {
    display: flex;
    flex-direction: column;
    gap: ${BTN_GAP}px;
    margin-top: ${COMPONENT_GAP}px;
    margin-left: ${BTN_D + COMPONENT_GAP}px;
}
```

This left-aligns the step grid with the LCD's left edge. Since the step grid (using `BTN_GAP` spacing) may be wider or narrower than the LCD, left-alignment with the LCD edge is cleaner than trying to center precisely. If the step grid is wider than the LCD, centering would push it too far right.

Actually, let's compute this properly. The step row uses `gap: ${BTN_GAP}px` (25px) with `STEP_BTN_D` (20px) buttons. Total step row width = 8 × 20 + 7 × 25 = 335px. The LCD bezel width ≈ 352px. They're close enough that centering under the LCD works well.

To center: `margin-left = BTN_D + COMPONENT_GAP + (LCD_bezel_width - step_row_width) / 2`

Let's compute the LCD bezel width from constants:
- LCD canvas CSS width: `73.44 * SCALE` = 330.48px → round to 330px
- lcd-mask padding: `2.0 * SCALE` each side = 9px × 2 = 18px → mask inner = 348px
- lcd-bezel padding: 2px each side → bezel outer = 352px

Step row width = `8 * STEP_BTN_D + 7 * BTN_GAP` = 160 + 175 = 335px

Center offset = `BTN_D + COMPONENT_GAP + (352 - 335) / 2` ≈ `23 + 24 + 8.5` = 55.5px

Rather than hardcode, use the constants:

```typescript
const LCD_BEZEL_W = Math.round(73.44 * SCALE) + 2 * Math.round(2.0 * SCALE) + 4  // canvas + mask padding + bezel padding
const STEP_ROW_W = 8 * STEP_BTN_D + 7 * BTN_GAP
const STEP_GRID_LEFT = BTN_D + COMPONENT_GAP + Math.round((LCD_BEZEL_W - STEP_ROW_W) / 2)
```

Replace the `.step-grid` CSS with:
```css
.step-grid {
    display: flex;
    flex-direction: column;
    gap: ${BTN_GAP}px;
    margin-top: ${COMPONENT_GAP}px;
    margin-left: ${STEP_GRID_LEFT}px;
}
```

**Step 3: Add derived constants**

After the existing derived constants section (line ~47), add:
```typescript
const LCD_BEZEL_W = Math.round(73.44 * SCALE) + 2 * Math.round(2.0 * SCALE) + 4
const STEP_ROW_W = 8 * STEP_BTN_D + 7 * BTN_GAP
const STEP_GRID_LEFT = BTN_D + COMPONENT_GAP + Math.round((LCD_BEZEL_W - STEP_ROW_W) / 2)
```

**Step 4: Run dev server and visually verify**

Run: `npm run dev`
Expected: Step grid is horizontally centered under the LCD display.

**Step 5: Commit**

```bash
git add src/ui/panel/faceplate.ts
git commit -m "feat: center step grid under LCD display"
```

---

### Task 5: Final Verification

**Step 1: Run full build**

Run: `npm run build`
Expected: Clean build, no errors.

**Step 2: Run all tests**

Run: `npm test`
Expected: All tests pass.

**Step 3: Visual check in browser**

Run: `npm run dev`

Verify:
- RESET, PLAY, RAND are tall rectangular buttons in the control strip
- Feature column has 4 buttons (MUTE, ROUTE, DIV/LEN, TBD) aligned with subtrack column
- TBD button renders but does nothing when clicked
- Step grid is centered under the LCD, not the full main-area
- Existing functionality (play, hold overlays, encoders) still works

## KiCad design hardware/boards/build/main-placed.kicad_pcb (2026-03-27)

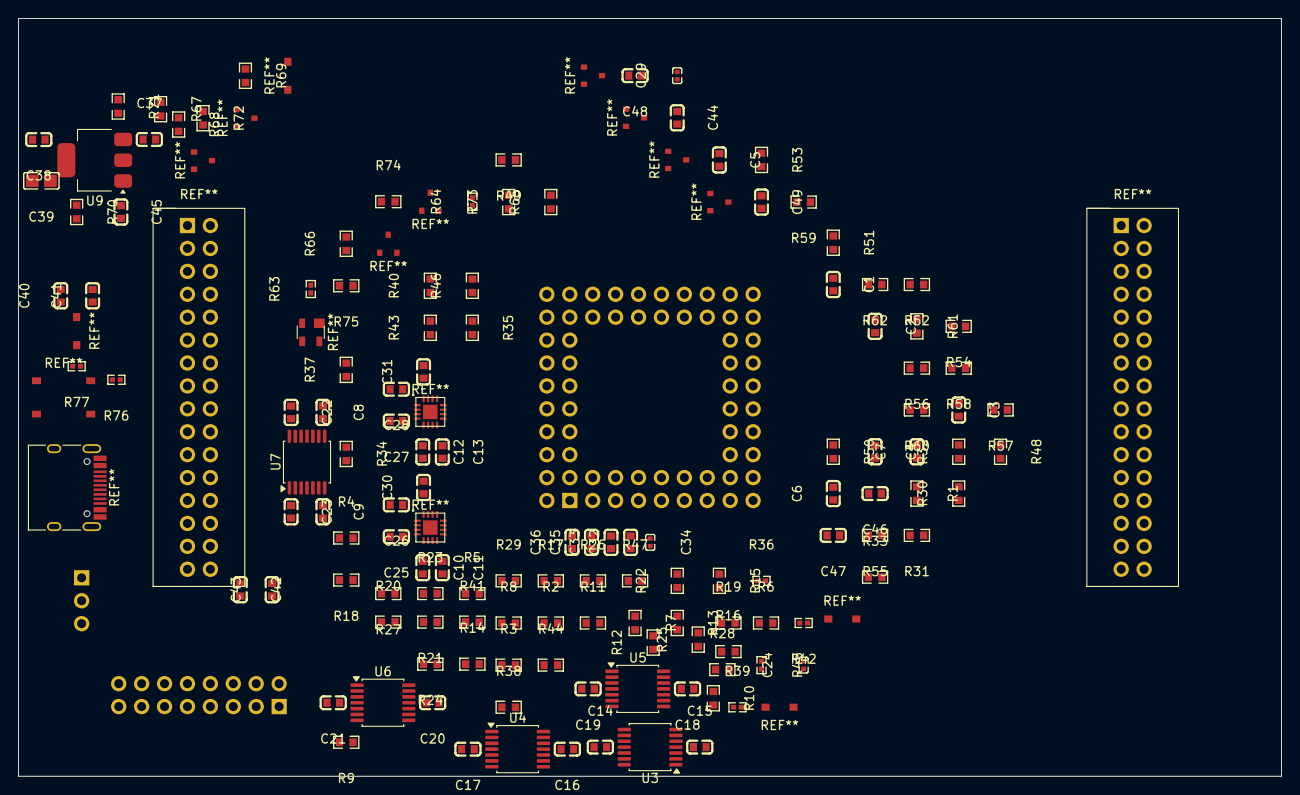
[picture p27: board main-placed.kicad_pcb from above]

Board: 4 copper layers, 140.0 x 84.0 mm, 132 parts (0 on the bottom side), 61 nets, no tracks yet.

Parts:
C1, C2, C3, C4, C5, C6, C44, C49: 10nF; C0603
C7, C8, C9, C11, C13, C26, C28, C32, C36, C37, C40, C42, C43: 10µF; C0603
C10, C12, C14, C15, C16, C17, C18, C19, C20, C21, C22, C23, C25, C27, C30, C31, C33, C35, C38, C41, C45, C46, C47, C48: 100nF; C0603
C24, C29: 1µF; C0402
C34: 2.2µF; C0402
C39: 47µF; C0805
R1: 10Ω; R0603
R2, R3, R4, R5, R8, R11, R14, R17, R20, R23, R26, R29, R38, R41, R44, R47: 470Ω; R0603
R6, R9, R12, R15, R33: 20kΩ; R0603
R7, R10, R13, R16, R18, R19, R21, R22, R24, R25, R27, R28, R30, R32, R34, R35, R37, R40, R43, R46, R49, R50, R51, R53, R55, R57, R59, R61, R67, R68, R69, R70, R71, R72, R75: 10kΩ; R0603
R31: 15kΩ; R0603
R36, R39, R42, R45: 6.04kΩ; R0402
R48: 200Ω; R0603
R52, R54, R56, R58, R60, R62: 22kΩ; R0603
R63, R64: 5.1kΩ; R0402
R65, R66, R73, R74: 1kΩ; R0603
R76, R77: 27Ω; R0402
U3, U4, U5, U6, U7: TSSOP-14
U9: SOT-223

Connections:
1: R20.1, U4.1
7: R23.1, U4.7
14: R29.1, U4.14
IN1_N: R2.1, U3.1, U3.2
IN2_N: R3.1, U3.6, U3.7
IN3_N: R4.1, U3.8, U3.9
IN4_N: R5.1, U3.13, U3.14
c_3v3_bulk-power-hv: C32.1, C33.1, R48.1, R49.1, R50.1
c_5v_hf-power-hv: C37.1, C40.1, C41.1, R1.1, R66.1, R74.1, U9.3
c_aref-power-hv: C34.1, R48.2
c_dac2_2-power-hv: C7.1, C10.1, C11.1, C12.1, C13.1, R1.2, R31.1, R33.1
c_enc_a_a-power-hv: C1.1, R67.2
c_enc_a_b-power-hv: C2.1, R68.2
c_enc_a_sw-power-hv: C3.1, R69.2
c_enc_b_a-power-hv: C4.1, R70.2
c_enc_b_b-power-hv: C5.1, R71.2
c_enc_b_sw-power-hv: C6.1, R72.2
c_filter-power-hv: C44.1, R51.1, R52.2
c_filter-power-hv-1: C45.1, R53.1, R54.2
c_filter-power-hv-2: C46.1, R55.1, R56.2
c_filter-power-hv-3: C47.1, R57.1, R58.2
c_filter-power-hv-4: C48.1, R59.1, R60.2
c_filter-power-hv-5: C49.1, R61.1, R62.2
c_op5_p-power-hv: C9.1, C15.1, C17.1, C19.1, C21.1, C23.1, C43.1, U3.4, U4.4, U5.4, U6.4, U7.4
c_pitch_ref-power-hv: C24.1, R30.1, R31.2, U7.3
c_ref1_hf-power-hv: C25.1, C26.1
c_ref2_hf-power-hv: C27.1, C28.1
c_ref_filt-power-hv: C29.1, R32.1, R33.2, U7.5
c_vb_hf-power-hv: C35.1, C36.1
c_vio2-power-hv: C30.1, C31.1, C38.1, C39.1, R34.1, R35.1, R67.1, R68.1, R69.1, R70.1, R71.1, R72.1, R75.1, U9.2, U9.4
dac-1: R36.1, R38.1, U5.1
dac-1-1: R6.1, R8.1, U6.1
dac-7: R39.1, R41.1, U5.7
dac-7-1: R9.1, R11.1, U6.7
dac-8: R26.1, U4.8
dac-8-1: R42.1, R44.1, U5.8
dac-8-2: R12.1, R14.1, U6.8
dac-14: R45.1, R47.1, U5.14
dac-14-1: R15.1, R17.1, U6.14
dac-IN1_N: R18.2, R19.1, U4.2
dac-IN1_N-1: R36.2, R37.1, U5.2
dac-IN1_N-2: R6.2, R7.2, U6.2
dac-IN2_N: R21.2, R22.1, U4.6
dac-IN2_N-1: R39.2, R40.1, U5.6
dac-IN2_N-2: R9.2, R10.2, U6.6
dac-IN3_N: R24.2, R25.1, U4.9
dac-IN3_N-1: R42.2, R43.1, U5.9
dac-IN3_N-2: R12.2, R13.2, U6.9
dac-IN4_N: R27.2, R28.1, U4.13
dac-IN4_N-1: R45.2, R46.1, U5.13
dac-IN4_N-2: R15.2, R16.2, U6.13
dac.opamp5-IN3_N: U7.8, U7.9
dac.opamp5-IN4_N: U7.13, U7.14
hv: C1.2, C2.2, C3.2, C4.2, C5.2, C6.2, C7.2, C8.1, C9.2, C10.2, C11.2, C12.2, C13.2, C14.1, C15.2, C16.1, C17.2, C18.1, C19.2, C20.1, C21.2, C22.1, C23.2, C24.2, C25.2, C26.2, C27.2, C28.2, C29.2, C30.2, C31.2, C32.2, C33.2, C34.2, C35.2, C36.2, C37.2, C38.2, C39.2, C40.2, C41.2, C42.1, C43.2, C44.2, C45.2, C46.2, C47.2, C48.2, C49.2, R30.2, R32.2, R37.2, R40.2, R43.2, R46.2, R51.2, R53.2, R55.2, R57.2, R59.2, R61.2, R63.2, R64.2, U7.10, U7.12, U9.1
lv: C8.2, C14.2, C16.2, C18.2, C20.2, C22.2, C42.2, U3.11, U4.11, U5.11, U6.11, U7.11
pitch1: R18.1, R20.2
pitch2: R21.1, R23.2
pitch3: R24.1, R26.2
pitch4: R27.1, R29.2
v_ref_2v: R19.2, R22.2, R25.2, R28.2, U7.1, U7.2
v_ref_mod: U6.3, U6.5, U6.10, U6.12, U7.6, U7.7

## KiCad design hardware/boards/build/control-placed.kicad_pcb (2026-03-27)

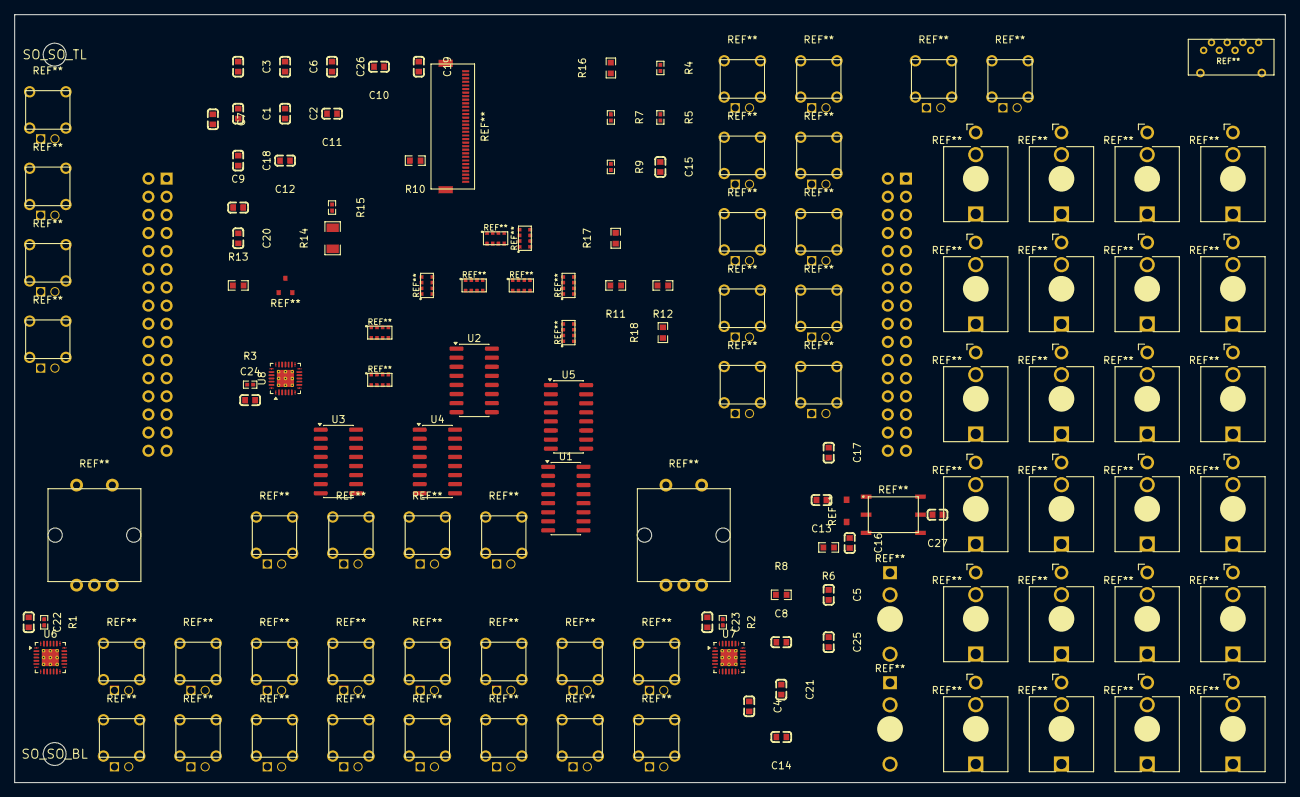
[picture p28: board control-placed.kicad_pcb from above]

Board: 4 copper layers, 177.9 x 107.5 mm, 55 parts (0 on the bottom side), 19 nets, no tracks yet.

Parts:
C1, C2, C3, C4, C5, C7, C9, C10, C11, C12, C13, C14, C15, C16, C17, C18, C19, C20, C22, C23, C24, C26, C27: 100nF; C0603
C6, C8, C21, C25: 10µF; C0603
R1, R2, R3, R15: 100kΩ; R0402
R4, R5, R9: 4.7kΩ; R0402
R6: 220Ω; R0603
R7: 33Ω; R0402
R8: 10Ω; R0603
R10, R11, R12, R16, R17: 10kΩ; R0603
R13: 100Ω; R0603
R14: 82Ω; R1206
R18: 47kΩ; R0603
SO_SO_BL: M3_Standoff
SO_SO_TL: M3_Standoff
U1, U2, U3, U4, U5: SOIC-16
U6, U7, U8: QFN-28-4x4

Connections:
CLK: U1.2, U2.2, U3.2, U4.2, U5.2
QH: U1.9, U2.10
R_EXT: R1.1, U6.28
SCL: R4.2, U6.23, U7.23, U8.23
SDA: R5.2, U6.24, U7.24, U8.24, U8.25
SH_LD: U1.1, U2.1, U3.1, U4.1, U5.1
buttons-QH: U2.9, U3.10
buttons-QH-1: U3.9, U4.10
buttons-QH-2: U4.9, U5.10
c_filt_a-power-hv: C22.1, U6.27
c_filt_b-power-hv: C23.1, U7.27
c_filt_c-power-hv: C24.1, U8.27
c_lcd_rst-power-hv: C14.1, R16.2
c_sd-power-hv: C1.1, C2.1, C3.1, C4.1, C5.1, C6.1, C7.1, C15.1, C16.1, C17.1, C18.1, C19.1, C20.1, C21.1, R4.1, R5.1, R7.1, R9.1, R10.1, R11.1, R12.1, R16.1, R17.1, R18.1, U1.16, U2.16, U3.16, U4.16, U5.3, U5.4, U5.5, U5.6, U5.16, U6.22, U6.26, U7.22, U7.25, U7.26, U8.22, U8.26
gate: R13.2, R15.1
hv: C8.1, C9.1, C25.1, C26.1, C27.1, R14.1
leds-R_EXT: R2.1, U7.28
leds-R_EXT-1: R3.1, U8.28
lv: C1.2, C2.2, C3.2, C4.2, C5.2, C6.2, C7.2, C8.2, C9.2, C10.2, C11.2, C12.2, C13.2, C14.2, C15.2, C16.2, C17.2, C18.2, C19.2, C20.2, C21.2, C22.2, C23.2, C24.2, C25.2, C26.2, C27.2, R1.2, R2.2, R3.2, R15.2, U1.8, U1.10, U1.15, U2.8, U2.15, U3.8, U3.15, U4.8, U4.15, U5.8, U5.15, U6.1, U6.2, U6.7, U6.16, U6.25, U6.29, U7.1, U7.2, U7.7, U7.16, U7.29, U8.1, U8.2, U8.7, U8.16, U8.29

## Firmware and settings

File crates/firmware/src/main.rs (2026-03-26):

//! Requencer firmware — RP2350B (PGA2350) embedded target.
//!
//! 4-track eurorack sequencer. Uses embassy async runtime for cooperative
//! multitasking across display, input scanning, and audio output.
//!
//! ## Architecture
//!
//! **Priority 0 (highest):** Hardware timer ISR → engine tick → DAC write (SPI1)
//! **Priority 1:** External clock input ISR → sync tick counter
//! **Priority 2:** Button scan (200 Hz), encoder poll (1 kHz)
//! **Priority 3:** Display render (~30 fps, SPI0), LED update, MIDI TX
//!
//! SPI0 = display + SD card (shared, firmware-arbitrated).
//! SPI1 = DACs (dedicated bus, direct 3.3V via DAC80508 VIO, zero contention).

// On embedded target: full firmware binary.
// On host: empty stub — lib tests run via `cargo test --lib`, binary is a no-op.
#![cfg_attr(target_os = "none", no_std)]
#![cfg_attr(target_os = "none", no_main)]

#[allow(dead_code)]
mod buttons;
mod clock_io;
#[allow(dead_code)]
mod cv_input;
mod cv_output;
#[allow(dead_code)]
mod dac;
#[cfg(target_os = "none")]
mod display;
mod encoders;
#[cfg(target_os = "none")]
mod leds;
#[allow(dead_code)]
mod midi;
#[cfg(target_os = "none")]
#[allow(dead_code)]
mod pins;
#[allow(dead_code)]
mod storage;

// Host stub: empty main so `cargo test --workspace` can compile the binary target.
#[cfg(not(target_os = "none"))]
fn main() {}

#[cfg(target_os = "none")]
use defmt::*;
#[cfg(target_os = "none")]
use defmt_rtt as _;
#[cfg(target_os = "none")]
use embassy_executor::Spawner;
#[cfg(target_os = "none")]
use embassy_rp::adc;
#[cfg(target_os = "none")]
use embassy_rp::gpio::{Input, Level, Output, Pull};
#[cfg(target_os = "none")]
use embassy_rp::i2c;
#[cfg(target_os = "none")]
use embassy_rp::spi::{self, Spi};
#[cfg(target_os = "none")]
use embassy_rp::uart;
#[cfg(target_os = "none")]
use embassy_rp::watchdog::Watchdog;
#[cfg(target_os = "none")]
use embassy_time::{Duration, Instant};
#[cfg(target_os = "none")]
use panic_probe as _;

#[cfg(target_os = "none")]
use requencer_engine::clock_divider::TICKS_PER_STEP;
#[cfg(target_os = "none")]
use requencer_engine::input::ControlEvent;
#[cfg(target_os = "none")]
use requencer_engine::mode_machine;
#[cfg(target_os = "none")]
use requencer_engine::sequencer;
#[cfg(target_os = "none")]
use requencer_engine::types::{ClockSource, SequencerState};
#[cfg(target_os = "none")]
use requencer_engine::ui_types::UiState;

// ── Main entry point ───────────────────────────────────────────────

#[cfg(target_os = "none")]
#[embassy_executor::main]
async fn main(_spawner: Spawner) {
    info!("Requencer firmware starting");

    let p = embassy_rp::init(Default::default());

    // ── Watchdog (8 second timeout) ─────────────────────────────────
    // Resets the processor if the main loop stalls for > 8 seconds.
    // Fed at the end of each main loop iteration.
    let mut watchdog = Watchdog::new(p.WATCHDOG);
    watchdog.pause_on_debug(true); // Don't reset while debugging
    watchdog.start(Duration::from_secs(8));
    info!("Watchdog started (8s timeout)");

    // ── SPI0: Display + SD card (shared bus) ───────────────────────

    let mut spi0_config = spi::Config::default();
    spi0_config.frequency = 62_500_000; // ST7796 max write speed

    // RP2350 SPI0 function assignments: GP2=SCK, GP3=MOSI (TX), GP0=MISO (RX)
    let mut spi0 = Spi::new_blocking(
        p.SPI0,
        p.PIN_2,  // SCK
        p.PIN_3,  // MOSI (TX to LCD + SD)
        p.PIN_0,  // MISO (RX from SD)
        spi0_config,
    );

    let lcd_cs = Output::new(p.PIN_1, Level::High);
    let lcd_dc = Output::new(p.PIN_7, Level::Low);
    let lcd_backlight = Output::new(p.PIN_5, Level::Low);
    let lcd_rst = Output::new(p.PIN_22, Level::High);

    let mut display_hw = display::Display::new(lcd_cs, lcd_dc, lcd_backlight, lcd_rst);
    display_hw.init(&mut spi0).await;

    // SD card pins
    let sd_cs = Output::new(p.PIN_24, Level::High);
    let sd_detect = Input::new(p.PIN_25, Pull::Up);
    let mut sd_storage = storage::SdStorage::new(sd_cs, sd_detect);

    // ── SPI1: DACs (dedicated bus, direct 3.3V via VIO) ────────────

    let mut spi1_config = spi::Config::default();
    spi1_config.frequency = 37_500_000; // 150MHz/4 — below DAC80508 50MHz max with margin
    spi1_config.phase = embassy_rp::spi::Phase::CaptureOnSecondTransition; // DAC80508 latches on SCLK falling edge → SPI Mode 1

    // RP2350 SPI1 function assignments: GP30=CLK, GP31=MOSI
    let spi1 = Spi::new_blocking_txonly(
        p.SPI1,
        p.PIN_30, // SCK
        p.PIN_31, // MOSI (TX to DACs, direct 3.3V)
        spi1_config,
    );

    let dac1_cs = Output::new(p.PIN_32, Level::High);
    let dac2_cs = Output::new(p.PIN_33, Level::High);

    let mut dac = dac::DacOutput::new(spi1, dac1_cs, dac2_cs);
    dac.init();
    info!("DACs initialized");

    // ── Button shift registers ─────────────────────────────────────

    let btn_clk = Output::new(p.PIN_8, Level::Low);
    let btn_latch = Output::new(p.PIN_9, Level::High);
    let btn_data = Input::new(p.PIN_10, Pull::Down);
    let mut button_scanner = buttons::ButtonScanner::new(btn_clk, btn_latch, btn_data);

    // ── LED drivers (IS31FL3216A × 3, I2C0) ────────────────────────

    let mut i2c0_config = i2c::Config::default();
    i2c0_config.frequency = 400_000; // 400kHz (IS31FL3216A max)

    let i2c0 = i2c::I2c::new_blocking(
        p.I2C0,
        p.PIN_13, // SCL (GP13 = I2C0 SCL, F3)
        p.PIN_12, // SDA (GP12 = I2C0 SDA, F3)
        i2c0_config,
    );
    let mut led_driver = leds::LedDriver::new(i2c0);
    led_driver.init();
    info!("LED drivers initialized (3× IS31FL3216A, I2C0 @ 400kHz)");

    // ── Encoders ───────────────────────────────────────────────────

    let enc_a_a = Input::new(p.PIN_15, Pull::Up);
    let enc_a_b = Input::new(p.PIN_16, Pull::Up);
    let enc_a_push = Input::new(p.PIN_17, Pull::Up);
    let enc_b_a = Input::new(p.PIN_18, Pull::Up);
    let enc_b_b = Input::new(p.PIN_19, Pull::Up);
    // GP20 is reassigned to UART1_TX (MIDI), so encoder B push moves to GP6 (spare)
    let enc_b_push = Input::new(p.PIN_6, Pull::Up);
    let mut encoder_pair = encoders::EncoderPair::new(
        enc_a_a, enc_a_b, enc_a_push, enc_b_a, enc_b_b, enc_b_push,
    );

    // ── MIDI UART ──────────────────────────────────────────────────

    let mut uart_config = uart::Config::default();
    uart_config.baudrate = 31250;

    // UART1: GP20=TX, GP21=RX (RP2350 function select for UART1)
    let uart = uart::Uart::new_blocking(
        p.UART1,
        p.PIN_20, // TX (MIDI OUT via 220Ω)
        p.PIN_21, // RX (MIDI IN via H11L1S optocoupler)
        uart_config,
    );
    let (uart_tx, uart_rx) = uart.split();
    let mut midi_out = midi::MidiOut::new(uart_tx);
    let mut midi_in = midi::MidiIn::new(uart_rx);
    info!("MIDI UART initialized at 31250 baud");

    // ── Clock/Reset I/O ────────────────────────────────────────────
    // Clock and reset inputs use interrupt-driven edge detection via spawned tasks.
    // This ensures no clock pulses are missed regardless of main loop latency.

    let clock_in = Input::new(p.PIN_26, Pull::Down);
    let reset_in = Input::new(p.PIN_27, Pull::Down);
    _spawner.spawn(clock_io::clock_input_task(clock_in)).unwrap();
    _spawner.spawn(clock_io::reset_input_task(reset_in)).unwrap();

    let clock_out = Output::new(p.PIN_28, Level::High); // Inverted: high GPIO = low output
    let reset_out = Output::new(p.PIN_4, Level::High); // Inverted: high GPIO = low output
    let mut clock_io = clock_io::ClockIo::new(clock_out, reset_out);
    info!("Clock/Reset I/O initialized (interrupt-driven input)");

    // ── CV Inputs (ADC4-7 on RP2350B) ─────────────────────────────

    let adc_hw = adc::Adc::new_blocking(p.ADC, adc::Config::default());
    let cv_a = adc::Channel::new_pin(p.PIN_40, Pull::None);
    let cv_b = adc::Channel::new_pin(p.PIN_41, Pull::None);
    let cv_c = adc::Channel::new_pin(p.PIN_42, Pull::None);
    let cv_d = adc::Channel::new_pin(p.PIN_43, Pull::None);
    let mut cv_reader = cv_input::CvReader::new(adc_hw, cv_a, cv_b, cv_c, cv_d);
    info!("CV inputs initialized (ADC4-7)");

    // ── Engine state ───────────────────────────────────────────────

    let mut state = SequencerState::new();
    state.apply_default_presets();

    // Try to load saved state and library from SD card
    if sd_storage.is_card_present() {
        info!("SD card detected, attempting state restore");
        let mut buf = [0u8; storage::STATE_BUF_SIZE];
        if let Some(len) = sd_storage.load_state(&mut spi0, &mut buf) {
            match requencer_engine::storage::deserialize_state(&buf[..len]) {
                Ok(restored) => {
                    state = restored;
                    info!("State restored from SD card ({} bytes)", len);
                }
                Err(_) => {
                    warn!("SD state file corrupt, using defaults");
                }
            }
        }

        // Load pattern library (patterns + user presets)
        let mut lib_buf = [0u8; requencer_engine::storage::LIBRARY_BUF_SIZE];
        if let Some(len) = sd_storage.load_library(&mut spi0, &mut lib_buf) {
            match requencer_engine::storage::deserialize_library(&lib_buf[..len]) {
                Ok((patterns, presets)) => {
                    info!("Library restored: {} patterns, {} presets", patterns.len(), presets.len());
                    state.saved_patterns = patterns;
                    state.user_presets = presets;
                }
                Err(_) => {
                    warn!("SD library file corrupt, using defaults");
                }
            }
        }
    }

    let mut ui = UiState::default();
    let mut framebuffer = display::Framebuffer::new();
    let mut gate_state = [false; 4];

    // CV output processor: runs at 4kHz to interpolate gate length, ratchets, slide, slew
    let mut cv_proc = cv_output::CvOutputProcessor::new(4000);

    // MIDI channel assignment: outputs 0-3 → MIDI channels 1-4
    let midi_channels: [u8; 4] = [0, 1, 2, 3];

    info!("Engine state initialized, entering main loop");

    // ── Timing ─────────────────────────────────────────────────────

    let mut system_tick: u32 = 0;
    let mut last_frame = Instant::now();
    let mut last_scan = Instant::now();
    let mut last_enc = Instant::now();
    let mut last_save = Instant::now();
    let mut state_dirty = false; // Track if state changed since last save
    let mut library_dirty = false; // Track if patterns/presets changed since last save

    // Drift-compensating tick scheduler: tracks when the next tick *should* fire.
    // Unlike `last_tick + interval`, this accumulates the exact interval so late
    // ticks don't push subsequent ticks later (eliminates cumulative drift).
    let mut next_tick_at = Instant::now();
    let mut was_playing = false;

    // Clock output pulse: set high on step boundary, clear after 5ms
    let mut clock_pulse_end: Option<Instant> = None;

    // CV output render rate: 4kHz = 250µs interval
    let mut last_cv_render = Instant::now();

    // Chunked display flush state — one chunk per main loop iteration
    let mut flush_state: Option<display::FlushState> = None;

    // ── Main loop ──────────────────────────────────────────────────

    loop {
        let now = Instant::now();

        // ── 1. Engine tick (BPM-driven, external clock, or MIDI clock) ──

        // Reset tick scheduler on play start to avoid burst of catch-up ticks
        if state.transport.playing && !was_playing {
            next_tick_at = now;
        }
        was_playing = state.transport.playing;

        let tick_interval_us = if state.transport.clock_source == ClockSource::Internal {
            60_000_000u64 / (state.transport.bpm as u64 * TICKS_PER_STEP as u64)
        } else {
            0 // External/MIDI clock drives ticks
        };

        let should_tick = if state.transport.playing {
            match state.transport.clock_source {
                ClockSource::Internal => now >= next_tick_at,
                ClockSource::External => clock_io.clock_pulse(),
                ClockSource::Midi => false, // MIDI clock handled in MIDI parse section
            }
        } else {
            false
        };

        if should_tick {
            // Advance by exact interval (drift-compensating)
            next_tick_at += Duration::from_micros(tick_interval_us);
            // If we fell behind by >100ms (e.g. SD card save stall), reset to now
            if now.duration_since(next_tick_at).as_millis() > 100 {
                next_tick_at = now;
            }
            process_tick(
                &mut state, &mut cv_proc, &mut midi_out, &mut clock_io,
                &mut gate_state, &midi_channels, &mut clock_pulse_end, now,
            );
            system_tick = system_tick.wrapping_add(1);
        }

        // ── 2. Clock output pulse end ───────────────────────────────

        if let Some(end_time) = clock_pulse_end {
            if now >= end_time {
                clock_io.set_clock_out(false);
                clock_pulse_end = None;
            }
        }

        // ── 2b. CV output render (4kHz = every 250µs) ──────────────
        // Runs the CV output processor to interpolate gate length, ratchets,
        // pitch slide, and mod slew between step boundaries.

        if now.duration_since(last_cv_render).as_micros() >= 250 {
            last_cv_render = now;
            cv_proc.render_tick();

            // Write interpolated values to DACs
            for i in 0..4u8 {
                let ch = &cv_proc.channels[i as usize];
                dac.set_dac1_channel(i, ch.gate_dac);         // DAC1 CH A-D: Gate
                dac.set_dac1_channel(i + 4, ch.pitch_dac);    // DAC1 CH E-H: Pitch
                dac.set_dac2_channel(i, ch.velocity_dac);     // DAC2 CH A-D: Velocity
                dac.set_dac2_channel(i + 4, ch.mod_dac);      // DAC2 CH E-H: Mod
            }
        }

        // ── 3. Check external reset ────────────────────────────────

        if clock_io.reset_pulse() {
            state.reset_playheads();
            clock_io.pulse_reset_out();
        }

        // ── 4. Scan buttons (every 5ms = 200 Hz) ──────────────────

        if now.duration_since(last_scan).as_millis() >= 5 {
            last_scan = now;
            let mut btn_events = heapless::Vec::<ControlEvent, 8>::new();
            button_scanner.scan(&mut btn_events);
            for ev in btn_events {
                let was_playing = state.transport.playing;
                let lib_before = (state.saved_patterns.len(), state.user_presets.len());
                mode_machine::dispatch(&mut ui, &mut state, ev, system_tick);
                state_dirty = true;
                // Detect library changes (pattern save/delete, preset save/delete)
                let lib_after = (state.saved_patterns.len(), state.user_presets.len());
                if lib_after != lib_before {
                    library_dirty = true;
                }

                // Send MIDI transport messages when play state changes
                if state.transport.playing != was_playing {
                    if state.transport.playing {
                        if state.transport.master_tick == 0 {
                            midi_out.send_start();
                        } else {
                            midi_out.send_continue();
                        }
                    } else {
                        midi_out.send_stop();
                        midi_out.all_notes_off(&midi_channels);
                        cv_proc.all_off();
                        for i in 0..4u8 {
                            dac.set_dac1_channel(i, 0);
                            gate_state[i as usize] = false;
                        }
                        // Save state + library immediately on stop (natural save point)
                        if sd_storage.is_card_present() {
                            let mut buf = [0u8; storage::STATE_BUF_SIZE];
                            if let Ok(bytes) = requencer_engine::storage::serialize_state(&state, &mut buf) {
                                let len = bytes.len();
                                if sd_storage.save_state(&mut spi0, &buf[..len]) {
                                    info!("State saved on transport stop");
                                    last_save = now;
                                    state_dirty = false;
                                }
                            }
                            if library_dirty {
                                let mut lib_buf = [0u8; requencer_engine::storage::LIBRARY_BUF_SIZE];
                                if let Ok(bytes) = requencer_engine::storage::serialize_library(
                                    &state.saved_patterns, &state.user_presets, &mut lib_buf,
                                ) {
                                    let len = bytes.len();
                                    if sd_storage.save_library(&mut spi0, &lib_buf[..len]) {
                                        info!("Library saved on transport stop");
                                        library_dirty = false;
                                    }
                                }
                            }
                        }
                    }
                }
            }
        }

        // ── 5. Poll encoders + CV inputs (every 1ms = 1 kHz) ──────

        if now.duration_since(last_enc).as_millis() >= 1 {
            last_enc = now;

            // Sample CV inputs (smoothed, change-detected)
            cv_reader.sample_all();

            let mut enc_events = heapless::Vec::<ControlEvent, 8>::new();
            encoder_pair.poll(&mut enc_events);
            for ev in enc_events {
                let was_playing = state.transport.playing;
                let lib_before = (state.saved_patterns.len(), state.user_presets.len());
                mode_machine::dispatch(&mut ui, &mut state, ev, system_tick);
                state_dirty = true;
                let lib_after = (state.saved_patterns.len(), state.user_presets.len());
                if lib_after != lib_before {
                    library_dirty = true;
                }

                if state.transport.playing != was_playing {
                    if state.transport.playing {
                        if state.transport.master_tick == 0 {
                            midi_out.send_start();
                        } else {
                            midi_out.send_continue();
                        }
                    } else {
                        midi_out.send_stop();
                        midi_out.all_notes_off(&midi_channels);
                        cv_proc.all_off();
                        for i in 0..4u8 {
                            dac.set_dac1_channel(i, 0);
                            gate_state[i as usize] = false;
                        }
                    }
                }
            }
        }

        // ── 6. Parse incoming MIDI ─────────────────────────────────

        while let Some(msg) = midi_in.try_read() {
            match msg {
                midi::MidiMessage::Clock => {
                    if state.transport.clock_source == ClockSource::Midi
                        && state.transport.playing
                    {
                        // MIDI clock → engine tick
                        process_tick(
                            &mut state, &mut cv_proc, &mut midi_out, &mut clock_io,
                            &mut gate_state, &midi_channels, &mut clock_pulse_end, now,
                        );
                        system_tick = system_tick.wrapping_add(1);
                    }
                }
                midi::MidiMessage::Start => {
                    state.transport.playing = true;
                    state.reset_playheads();
                    info!("MIDI Start received");
                }
                midi::MidiMessage::Stop => {
                    state.transport.playing = false;
                    midi_out.all_notes_off(&midi_channels);
                    cv_proc.all_off();
                    for i in 0..4u8 {
                        dac.set_dac1_channel(i, 0);
                        gate_state[i as usize] = false;
                    }
                    info!("MIDI Stop received");
                }
                midi::MidiMessage::Continue => {
                    state.transport.playing = true;
                    info!("MIDI Continue received");
                }
                midi::MidiMessage::NoteOn { channel, note, velocity } => {
                    mode_machine::dispatch(
                        &mut ui, &mut state,
                        ControlEvent::MidiNoteOn { channel, note, velocity },
                        system_tick,
                    );
                }
                midi::MidiMessage::NoteOff { channel, note } => {
                    mode_machine::dispatch(
                        &mut ui, &mut state,
                        ControlEvent::MidiNoteOff { channel, note },
                        system_tick,
                    );
                }
                midi::MidiMessage::ControlChange { channel, cc, value } => {
                    debug!("MIDI CC ch={} cc={} val={}", channel, cc, value);
                }
            }
        }

        // ── 7. Render display (~30 fps, chunked flush) ──────────────
        // Flush is split into 16-scanline chunks (~240µs each) to allow
        // engine ticks to fire between chunks, reducing worst-case jitter.

        if now.duration_since(last_frame).as_millis() >= 33 && flush_state.is_none() {
            last_frame = now;

            requencer_renderer::render(&mut framebuffer, &state, &ui);
            flush_state = Some(display_hw.flush_begin(&mut spi0));
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

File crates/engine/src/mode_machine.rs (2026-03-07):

//! Mode machine — maps (UiState, SequencerState, ControlEvent) → mutated state.
//!
//! This is the Rust port of `web/src/ui/mode-machine.ts`.
//! Pure logic, no platform dependencies. Shared by firmware and WASM.

#![allow(clippy::too_many_lines)]

use crate::input::ControlEvent;
use crate::math::{clamp, roundf};
use crate::presets;
use crate::sequencer::SubtrackId;
use crate::types::{
    ArpDirection, ClockSource, GateAlgo, LayerFlags, LfoSyncMode, LfoWaveform,
    MutateTrigger, ModMode, ModSource, PitchArpDirection, PitchMode,
    SequencerState, TransformType, VariationSlot, VelocityMode,
};
use crate::ui_types::{
    Feature, HeldButton, LedMode, LedState, NameEntryContext, ScreenMode, UiState, UiSubtrack,
};
use crate::MAX_STEPS;

/// Name entry charset: A-Z, space, 0-9, dash (37 chars).
pub const NAME_CHARSET: &[u8] = b"ABCDEFGHIJKLMNOPQRSTUVWXYZ 0123456789-";
const NAME_MAX_LEN: usize = 12;

/// LFO waveform cycle order.
const LFO_WAVEFORMS: [LfoWaveform; 6] = [
    LfoWaveform::Sine,
    LfoWaveform::Triangle,
    LfoWaveform::Saw,
    LfoWaveform::Square,
    LfoWaveform::SlewRandom,
    LfoWaveform::SampleAndHold,
];

const LFO_PARAM_COUNT: i32 = 7;
const MUTATE_PARAM_COUNT: i32 = 6;

/// Bar options for mutate config.
const BAR_OPTIONS: [u8; 5] = [1, 2, 4, 8, 16];

// ── Helpers ──────────────────────────────────────────────────────────

fn clamp_i32(v: i32, lo: i32, hi: i32) -> i32 {
    if v < lo { lo } else if v > hi { hi } else { v }
}

fn clamp_u8(v: i32, lo: u8, hi: u8) -> u8 {
    clamp_i32(v, lo as i32, hi as i32) as u8
}

fn wrap(v: i32, n: i32) -> i32 {
    ((v % n) + n) % n
}

/// Round f32 to 2 decimal places.
fn round2(v: f32) -> f32 {
    roundf(v * 100.0) / 100.0
}

fn clamp_round(v: f32, lo: f32, hi: f32) -> f32 {
    round2(clamp(v, lo, hi))
}

fn subtrack_to_id(s: UiSubtrack) -> SubtrackId {
    match s {
        UiSubtrack::Gate => SubtrackId::Gate,
        UiSubtrack::Pitch => SubtrackId::Pitch,
        UiSubtrack::Velocity => SubtrackId::Velocity,
        UiSubtrack::Mod => SubtrackId::Mod,
    }
}

// ── Main dispatch ────────────────────────────────────────────────────

/// Process a control event, mutating UI and engine state in place.
pub fn dispatch(
    ui: &mut UiState,
    engine: &mut SequencerState,
    event: ControlEvent,
    system_tick: u32,
) {
    // --- Hold events ---
    match event {
        ControlEvent::HoldStart { button } => {
            // Step hold in gate-edit: select step for GL/ratchet editing
            if let HeldButton::Step(step) = button {
                if ui.mode == ScreenMode::GateEdit {
                    ui.held_button = Some(button);
                    ui.hold_encoder_used = false;
                    ui.selected_step = step as i8;
                    return;
                }
            }
            // Only feature buttons with hold combos (mute, variation) get hold state
            if let HeldButton::Feature(f) = button {
                if f != Feature::Mute && f != Feature::Variation {
                    return;
                }
            }
            ui.held_button = Some(button);
            ui.hold_encoder_used = false;
            return;
        }
        ControlEvent::HoldEnd => {
            let clear_step = matches!(ui.held_button, Some(HeldButton::Step(_)));
            ui.held_button = None;
            ui.hold_encoder_used = false;
            if clear_step {
                ui.selected_step = -1;
            }
            return;
        }
        _ => {}
    }

    // --- Hold combo: step held in gate-edit + step press → tie range ---
    if let Some(HeldButton::Step(_)) = ui.held_button {
        if ui.mode == ScreenMode::GateEdit {
            if let ControlEvent::StepPress { step } = event {
                dispatch_step_tie(ui, engine, step);
                return;
            }
        }
    }

    // --- Hold combo: step held in gate-edit → encoder A = gate length, encoder B = ratchet ---
    if let Some(HeldButton::Step(_)) = ui.held_button {
        if ui.mode == ScreenMode::GateEdit {
            match event {
                ControlEvent::EncoderATurn { delta } | ControlEvent::EncoderBTurn { delta } => {
                    dispatch_step_hold_combo(ui, engine, &event, delta);
                    return;
                }
                _ => {}
            }
        }
    }

    // --- Hold combo: encoder turns while button held → length/division ---
    if ui.held_button.is_some() {
        match event {
            ControlEvent::EncoderATurn { delta } | ControlEvent::EncoderBTurn { delta } => {
                dispatch_hold_combo(ui, engine, &event, delta);
                return;
            }
            _ => {}
        }
    }

    // --- Hold combo: RESET while button held → targeted playhead reset ---
    if ui.held_button.is_some() && event == ControlEvent::Reset {
        dispatch_hold_reset(ui, engine);
        return;
    }

    // --- Hold combo: RAND while button held → targeted randomization ---
    if ui.held_button.is_some() {
        if let ControlEvent::FeaturePress { feature: Feature::Rand } = event {
            dispatch_hold_rand(ui, engine, system_tick);
            return;
        }
    }

    // --- Name entry mode: isolates all input ---
    if ui.mode == ScreenMode::NameEntry {
        dispatch_name_entry(ui, engine, event);
        return;
    }

    // --- Global events (work in every mode) ---

    if event == ControlEvent::PlayStop {
        engine.transport.playing = !engine.transport.playing;
        return;
    }

    if event == ControlEvent::Reset {
        engine.reset_playheads();
        return;
    }

    // --- MIDI note input → live transpose ---
    if let ControlEvent::MidiNoteOn { note, .. } = event {
        let t = ui.selected_track as usize;
        // Transpose relative to C3 (MIDI 60), clamped to ±48 semitones
        let offset = (note as i16 - 60).clamp(-48, 48) as i8;
        engine.transpose_configs[t].semitones = offset;
        return;
    }
    if let ControlEvent::MidiNoteOff { .. } = event {
        // NoteOff currently ignored — transpose stays latched
        return;
    }
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

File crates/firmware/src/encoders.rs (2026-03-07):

//! Rotary encoder (EC11E × 2) quadrature decoding + push button.
//!
//! Each encoder has:
//! - Phase A + Phase B for rotation (gray code)
//! - Push switch for press events
//!
//! Hardware has 10kΩ pull-ups + 100nF caps (~1ms RC time constant).
//! Firmware debounce: ~30ms for push, quadrature state machine for rotation.

#[cfg(target_os = "none")]
use embassy_rp::gpio::Input;
#[cfg(target_os = "none")]
use requencer_engine::input::ControlEvent;

/// Quadrature state machine for one encoder.
/// Tracks gray code transitions to determine direction.
pub struct QuadratureState {
    prev_a: bool,
    prev_b: bool,
    /// Accumulated sub-detent steps (4 edges per detent for EC11E).
    sub_steps: i8,
}

impl Default for QuadratureState {
    fn default() -> Self {
        Self::new()
    }
}

impl QuadratureState {
    pub const fn new() -> Self {
        Self {
            prev_a: false,
            prev_b: false,
            sub_steps: 0,
        }
    }

    /// Update with new A/B readings. Returns delta detents (-1, 0, or +1).
    pub fn update(&mut self, a: bool, b: bool) -> i32 {
        let prev = (self.prev_a as u8) << 1 | self.prev_b as u8;
        let curr = (a as u8) << 1 | b as u8;
        self.prev_a = a;
        self.prev_b = b;

        // Gray code direction table
        // Transitions that indicate CW rotation: 00→01, 01→11, 11→10, 10→00
        // Transitions that indicate CCW rotation: 00→10, 10→11, 11→01, 01→00
        let direction: i8 = match (prev, curr) {
            (0b00, 0b01) => 1,
            (0b01, 0b11) => 1,
            (0b11, 0b10) => 1,
            (0b10, 0b00) => 1,
            (0b00, 0b10) => -1,
            (0b10, 0b11) => -1,
            (0b11, 0b01) => -1,
            (0b01, 0b00) => -1,
            _ => 0, // no change or invalid (missed edge)
        };

        self.sub_steps += direction;

        // EC11E has 4 edges per detent — emit one delta per detent
        if self.sub_steps >= 4 {
            self.sub_steps -= 4;
            return 1;
        } else if self.sub_steps <= -4 {
            self.sub_steps += 4;
            return -1;
        }
        0
    }
}

/// Push button debounce state.
pub struct ButtonDebounce {
    /// How many consecutive reads the button has been in the target state.
    stable_count: u8,
    /// Last debounced state (true = pressed).
    debounced: bool,
}

impl Default for ButtonDebounce {
    fn default() -> Self {
        Self::new()
    }
}

impl ButtonDebounce {
    pub const fn new() -> Self {
        Self {
            stable_count: 0,
            debounced: false,
        }
    }

    /// Update with a raw reading. Returns Some(true) on press, Some(false) on release.
    /// Debounce threshold: 6 reads at ~1kHz polling ≈ 6ms (hardware RC + firmware).
    pub fn update(&mut self, pressed: bool) -> Option<bool> {
        if pressed != self.debounced {
            self.stable_count += 1;
            if self.stable_count >= 6 {
                self.debounced = pressed;
                self.stable_count = 0;
                return Some(pressed);
            }
        } else {
            self.stable_count = 0;
        }
        None
    }
}

/// Encoder pair — two encoders (A and B) with rotation + push.
#[cfg(target_os = "none")]
pub struct EncoderPair<'a> {
    enc_a_phase_a: Input<'a>,
    enc_a_phase_b: Input<'a>,
    enc_a_push: Input<'a>,
    enc_b_phase_a: Input<'a>,
    enc_b_phase_b: Input<'a>,
    enc_b_push: Input<'a>,
    quad_a: QuadratureState,
    quad_b: QuadratureState,
    btn_a: ButtonDebounce,
    btn_b: ButtonDebounce,
}
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

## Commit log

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2026-02-28 Add panel layout redesign design doc
    Control strip with larger RESET/PLAY/RAND buttons alongside
    encoders, overlay-only right column (MUTE/ROUTE/DIV-LEN),
    step grid aligned to LCD width.
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2026-02-28 feat: restructure panel with control strip layout
    - RESET/PLAY/RAND as large buttons (~14mm) in control strip with encoders
    - Feature column reduced to 3 overlay-only buttons: MUTE, ROUTE, DIV/LEN
    - RAND moved from feature column to control strip (not holdable)
    - Updated mode indicators, keyboard bindings, and help modal
2026-02-28 Add panel layout fixes design and implementation plan
    Rectangular transport buttons, 4-row column alignment, step grid
    centering under LCD.
2026-02-28 feat: rectangular transport buttons (Bitbox-inspired)
    Replace circular LARGE_BTN_D with RECT_BTN_W/H for taller rectangular
    RESET/PLAY/RAND buttons with rounded corners.
2026-02-28 feat: add 4th feature button (TBD) for column alignment
    Feature column now has 4 rows matching subtrack column.
    Guard event/indicator loops to skip unwired TBD button.
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2026-02-28 feat: square transport buttons, wider RAND as hero button
    RESET/PLAY: 10×10mm square buttons
    RAND: 14×10mm wide hero button to emphasize it as the main feature
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2026-02-28 feat: flex-fill transport buttons spanning full control strip width
    Buttons now flex-grow to fill the space left of encoders.
    RESET/PLAY get flex:1, RAND gets flex:1.5 as the hero button.
    Removed fixed RECT_BTN_W and HERO_BTN_W constants.
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2026-03-01 feat: reorder control strip to enc A | RESET RAND PLAY | enc B
    Encoders bookend the transport buttons. RAND centered as hero.
    Flat flex layout replaces left/right container split.
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2026-03-03 feat: per-subtrack variation overrides UI
    Add the missing per-subtrack override UI for the variations feature.
    Each subtrack (GATE/PITCH/VEL/MOD) can now independently inherit,
    bypass, or override the track-level variation pattern with its own
    transforms, phrase length, and bar counter.
    Controls:
    - Hold subtrack button in VAR mode: shows override state overlay
    - Hold subtrack + Enc A push: cycles inherit → bypass → override
    - Release subtrack (when override): enters subtrack pattern editing
    - Subtrack-select toggles in/out of subtrack editing
    - Back exits subtrack editing before exiting VAR mode
    - All existing controls (step select, catalog browse, add/remove
    transforms, param adjust,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
2026-03-03 fix: align button columns top and wire VAR button click
    Top-section was using align-items:center, causing misalignment between
    4-button and 5-button columns. FEATURE_IDS was missing 'variation',
    so the 5th feature button (VAR) had no event listeners.
    https://claude.ai/code/session_015mETRcVSDL1agyFQw3YruU
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2026-03-03 Implement LFO/MOD redesign: parallel mod sources, generation modes, step slew
    Two independent modulation sources per track running in parallel:
    - MOD SEQ: step sequencer with per-step slew and 7 generation modes
    (RAND/RISE/FALL/VEE/HILL/SYNC/WALK)
    - MOD LFO: continuous tick-level waveform evaluator with 6 waveforms
    (sine/triangle/saw/square/slew-random/s+h), synced and free-running modes
    Routing layer selects which source feeds each output's mod signal via
    modSource field ('seq'|'lfo'). Both sources always advance regardless
    of routing, enabling seamless mid-performance switching.
    Key changes:
    - ModStep compound type (value + slew) replaces plain number in mod subtrack
    - computeLFOValu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
2026-03-03 Fix MOD LFO encoder mapping to match other screens
    Swap encoder-a (left) and encoder-b (right) roles in MOD LFO view:
    encoder-a now scrolls params, encoder-b adjusts values — consistent
    with rand, transpose, mutate, and settings screens.
    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
2026-03-03 Add waveform preview for S+H and slew-random LFO modes
    Replace text placeholders with actual waveform curves:
    - S+H: stepped random values with flat holds between triggers
    - Slew-random: smooth interpolation between random targets
    Both use a seeded RNG so the preview is stable across frames.
    Depth, offset, and width params affect the preview shape.
    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
2026-03-03 CLR button — context-sensitive clear replacing TBD placeholder
    Double-press to confirm on most screens, single-press delete for
    variation transforms. Consolidates encoder-hold reset patterns
    (settings, rand, transpose, variation) into one dedicated button.
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2026-03-04 Fix all Biome linter errors and warnings (except cognitive complexity)
    - Auto-fix formatting, import ordering, and unused imports (11 errors)
    - Replace non-null assertions with optional chaining or null guards (23 warnings)
    - Replace `as any` casts with proper types: restructure setSubtrackLength
    for type-safe branches, add asVariation() helper in tests (10 warnings)
    Remaining: 31 cognitive complexity warnings (intentionally set to warn level)
    https://claude.ai/code/session_016uWZdZuT4nVUHvvLZ35nvC
2026-03-04 Rework pattern save/load for single-track focus with physical button layer selection
    - SavedPattern simplified from 4-slot sparse array to single TrackSlotData + sourceTrack
    - LayerFlags split from grouped 'subtracks' flag into per-subtrack toggles (gate/pitch/vel/mod)
    - Pattern-load mode uses physical buttons to toggle layers instead of LCD checklist
    - Track buttons (T1-T4) select destination track during load
    - Step LEDs preview saved pattern's gate data
    - Subtrack/feature button LEDs reflect layer flag state during load
    - Remove save-all, loadPattern (multi-slot mapping), snapshotAllTracks, snapshotSingleTrack
    - LFO, Random, Arp configs always restored (generation context)
    - Old localStor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
2026-03-04 Remove migration code, block event leaks in pattern-load, add tests
    - Remove backwards-compat migration in persistence.ts (prototype only)
    - Block settings-press, clr-press, step-press, pattern-press in pattern-load
    mode to prevent accidental navigation/data loss
    - Add 15 mode-machine tests covering pattern-load: button toggles, track
    selection, apply with layer flags, event blocking, LED state
    https://claude.ai/code/session_01VS9acswmfw3vcSzbQdSwwn
2026-03-04 Fix pattern bugs: validate localStorage, flash messages, colored buttons
    - Filter corrupt/old-format patterns in loadPatterns() to fix tNaN crash
    - Replace sourceTrack display with pattern counter (1/N) on pattern screen
    - Add flash overlay system: SAVED, LOADED, DELETED messages (1.2s)
    - Auto-select newly saved pattern in the list after save
    - Highlight layer toggle buttons in target track color during pattern-load
    - Clear inline button styles when leaving pattern-load mode
    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
2026-03-04 Rework pattern screen: individual rows per pattern, CLR to delete
    - Each saved pattern gets its own row in a scrollable list
    - Enc A scrolls through save action + all patterns
    - Enc A push on pattern row enters load mode
    - CLR double-press deletes selected pattern (with DELETED flash)
    - Step LEDs preview gate pattern when cursor is on a pattern row
    - Remove enc B browsing and separate DELETE row (no longer needed)
    - Add 8 new tests for pattern list behavior
    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
2026-03-04 Clean up pattern screen: fix bug, extract helper, improve types
    - Fix bug: isSelected ? textDim : textDim → just textDim (identical branches)
    - Extract fillGatePreviewLEDs helper to deduplicate pattern/pattern-load LED code
    - Use row.type discriminant instead of row.paramId for pattern-item checks
    - Make PatternRow a discriminated union so patternIndex is non-optional on
    pattern-item rows, eliminating redundant null guards
    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
2026-03-04 Fix biome formatting errors across 5 files
    Auto-fixed via `npm run fix` — reformats ternary expressions and
    multi-line function call arguments to match biome's style rules.
    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
2026-03-04 Standardize LCD screen rendering across all screens
    - Remove encoder/key combo help text from LCD screens (moved to textbox below module)
    - Remove hint text from hold overlays (thin and full modes)
    - Add hold-state-aware hints system (HOLD_HINTS + getActiveHint) to main.ts
    - Standardize font sizes: 14px→16px for info text (mutate, variation, pattern-load)
    - Standardize variation screen: ROW_H 22→24, LIST_TOP offset, 12-14px→16px text
    - Standardize hold overlay: track thin 16→18px, track full 18→24px values
    - Add missing variation hold overlay (thin + full) showing phrase length/loop mode
    - Add track indicator to mute screen title (MUTE → MUTE — T1)
    - Bump variation state progre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
2026-03-04 Add 14 new variation transforms across 4 categories
    Playhead: half-time, skip, drunk-walk, scramble
    Gate: invert-gates, densify, drop, ratchet
    Pitch: fold, quantize
    Velocity: accent, fade-in, fade-out, humanize (new category)
    Adds getEffectiveVelocityStep for velocity-specific value transforms,
    updates routing to use it, and includes 39 new tests (91 total).
    https://claude.ai/code/session_01UwcFSnpVJroZMDcYUpz7eg
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2026-03-04 Rework catalog picker as dropdown overlay on transform stack
    Instead of replacing the entire view, render the transform stack normally
    then draw the catalog dropdown on top, anchored at the add slot row.
    The background content stays visible above the dropdown.
    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
2026-03-04 Replace catalog dropdown with compact 7-item popup overlay
    The catalog now only appears when the user actively browses with encoder B
    on the add slot (varCatalogOpen flag). Shows a bordered popup with 7 visible
    items centered on the selection, instead of the previous full-height dropdown
    with category headers and scroll thumb.
    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
2026-03-04 Fix mobile button handling: single-handler approach
    Replace dual touchend+pointerdown handlers with single handlers:
    - PLAY uses click (valid iOS audio gesture, no multi-touch needed)
    - RAND/BACK/CLR use pointerdown (works in multi-touch combos)
    Eliminates double-fire bug and fixes hold+tap combos on mobile.
    https://claude.ai/code/session_01LqYohadKK868SEzuQWMBSy
2026-03-04 Code review cleanup: remove debug overlay, fix bugs, remove dead code
    - Remove timing debug overlay and all _dbg* counters from main.ts
    - Fix: guard midiClockIn.startListening with device-index-changed check
    to prevent resetting clock recovery on every UI event
    - Fix: call midiClockIn.stopListening() when stopping playback
    - Replace splice with slice in clock-recovery for immutable consistency
    - Remove unused recoveredBpm getter from MIDIClockIn
    - Remove unused sendContinue/CONTINUE from MIDIClockOut
    - Fix misleading comment about Continue vs Start behavior
    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
2026-03-05 Fix CI pipeline: remove broken KicadModTree dependency
    - Rewrite generate_footprints.py to output KiCad S-expressions directly
    instead of using KicadModTree (which fails to build on modern setuptools)
    - Remove `pip install KicadModTree` step from CI workflow
    - Use `python3` instead of `python` in workflow commands
    - All scripts now have zero external dependencies (stdlib only)
    - Include generated footprint files and faceplate PCB
    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
    [faceplate.kicad_pcb]
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2026-03-05 Add Phase 4: mutator and routing modules
    - mutator.rs: Turing machine mutation engine — selects random steps
    and regenerates them using track's RandomConfig constraints. Per-
    subtrack drift rates for gate/pitch/velocity/mod.
    - routing.rs: Output resolution with cross-track routing, transpose,
    variation overlays, tie/sustain behavior, mute overrides, LFO vs
    seq mod source, GL/VEL scaling.
    102 tests passing, clippy clean, no_std verified.
    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
    [lib.rs]
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2026-03-05 Complete renderer, web, and firmware crates
    - Renderer: 15 screen modules (home, gate/pitch/vel/mod/mute edit,
    route, rand, mutate, transpose, variation, settings, pattern,
    pattern_load, name_entry) with full render() dispatch
    - Renderer: colors, layout, draw primitives, types (UiState, ScreenMode)
    - Web: Canvas2D framebuffer DrawTarget + wasm-bindgen API with
    step editing, routing, transport, and UI navigation bindings
    - Firmware: structured hardware stub modules (display, DAC, input,
    clock, MIDI, storage) ready for embassy/RTIC integration
    - Engine: clock recovery module, page-scoped clear, mute setters,
    user presets, default preset assignment
    - All crates: no_std default, 139 te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
    [lib.rs, main.rs]
2026-03-05 Code review fixes: DAC math, zero-copy render, renderer tests
    - Fix note_to_dac() to use C0 (MIDI 12) = 0V reference for eurorack
    - Add zero-copy render path (render_in_place + buffer_ptr/buffer_len)
    - Add 17 renderer tests: all-screen render smoke test, format helpers,
    color palette, MIDI note names, flash message, LFO view
    - Total: 156 tests passing across workspace
    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
    [lib.rs, main.rs]
2026-03-05 Align Rust renderer with TS UI: add missing visual features across all screens
    - Status bar: em-dash track indicators (GATE — T1, MOD LFO — T2, etc.)
    - Home: selected track tint, variation ~ indicator, info footer, pitch/vel playheads, bright pitch bars
    - Gate edit: selected step info (GL%, R:x), ratchet tick marks, playhead bars
    - Pitch edit: selected step info (note + MIDI# + slide), selected bar highlight, playheads
    - Vel edit: selected step value display, selected bar highlight, playheads
    - Mod edit: step info (value%, slew%), length/page info, playhead bars, placeholder steps
    - LFO: smooth waveform curves, dashed center line, phase cursor + dot, border, Hz formatting
    - Mute edit: se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
    [lib.rs]
2026-03-05 Add complete WASM engine bindings and TS adapter
    Expand WasmSequencer with tick(), randomization, config setters (LFO,
    mutate, transpose, arp, variation), pattern save/load, state getters,
    and UI state sync. Add TypeScript WasmEngine adapter class that wraps
    the Rust WASM module for drop-in use alongside the existing TS engine.
    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
    [lib.rs]
2026-03-06 Add TS/WASM engine toggle and WASM build to CI
    - Add debug menu toggle to switch between TS and WASM engine (persisted
    in localStorage, requires page reload)
    - Wire WASM tick + LCD rendering into main.ts render/tick loops
    - Add non-toggling setters (set_gate_on, set_gate_tie, set_mute_step)
    to Rust WasmSequencer for reliable TS→WASM state sync
    - Add wasm-pack build steps to preview.yml and deploy.yml CI workflows
    - Make dev target depend on build-wasm in Makefile
    - Configure Vite with esnext target and WASM optimizeDeps exclusion
    - Disable wasm-opt in release profile to avoid binaryen download issues
    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
    [lib.rs]
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2026-03-07 Implement full firmware for RP2350B (PGA2350) with embassy
    Complete hardware abstraction layer replacing the previous stub:
    - ST7796 480x320 TFT display driver (SPI0, framebuffer + scanline flush)
    - DAC8568 dual 8-channel DAC output (SPI1, dedicated bus via 74HCT125)
    - 74HC165 shift register button scanning (5x daisy-chain, 40 bits, debounce + hold)
    - EC11E rotary encoder quadrature decoding (2 encoders, gray code state machine)
    - TLC5947 LED driver chain (5x daisy-chain, 120 channels, 12-bit PWM)
    - MIDI UART I/O (31250 baud, note/CC/clock TX, running status RX parser)
    - Clock/reset I/O (edge detection input, NPN-inverted output)
    - SD card storage interface (structured placeholder, SPI0 sha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
    [clock_io.rs, dac.rs, display.rs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]
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2026-03-07 Address firmware production gaps: watchdog, clock pulses, MIDI routing, no-alloc serialization
    - Add RP2350 watchdog timer (8s timeout, fed each main loop iteration)
    - Fix clock output to emit 5ms pulses instead of level toggle (eurorack-compatible)
    - Route MIDI clock messages as tick source when ClockSource::Midi is active
    - Switch postcard serialization from to_allocvec (heap) to to_slice (stack buffer)
    - Remove embedded-alloc dependency and global allocator from firmware
    - Add defmt::warn! error logging on SPI/UART write failures
    - Extract process_tick() helper to deduplicate internal/MIDI clock paths
    - Add SD card save/load library methods to firmware storage module
    - Update engine tests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
    [dac.rs, display.rs, lib.rs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]
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2026-03-07 Fix critical/high firmware gaps: SD persistence, MIDI transport sync, tick timing
    - Implement SD card persistence with embedded-sdmmc FAT32 filesystem
    - SdSpiDevice wrapper implements embedded_hal::spi::SpiDevice for bus sharing
    - write_file/read_file use Volume/Directory/File wrapper API
    - Auto-save state to REQSTATE.BIN every 30s when stopped and dirty
    - Load state on boot if SD card present
    - Refactor Display to borrow SPI0 instead of owning it, enabling bus sharing
    - Send MIDI Start/Stop/Continue when PlayStop button toggles transport
    - Start sent when master_tick==0, Continue when resuming mid-sequence
    - Stop sends all-notes-off and clears gates
    - Replace drift-prone last_ti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
    [display.rs, main.rs, storage.rs]
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2026-03-07 Fix medium firmware gaps: CV inputs, interrupt clock, chunked display flush
    - Add CV input module with ADC4-7 reading on RP2350B (GP40-43)
    - Voltage conversion: divider ratio, semitones (1V/oct), gate, MIDI value
    - CvChannel EMA smoothing (alpha=1/8) with change-detection threshold
    - CvReader hardware wrapper with sample_all() at 1kHz in main loop
    - 28 unit tests covering conversions, smoothing, and end-to-end ADC paths
    - Replace polled clock/reset edge detection with interrupt-driven tasks
    - clock_input_task and reset_input_task use wait_for_rising_edge().await
    - AtomicBool flags (CLOCK_EDGE, RESET_EDGE) for lock-free main loop polling
    - No clock pulses missed regardless of ma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
    [clock_io.rs, cv_input.rs, display.rs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]
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2026-03-07 Fix low-priority firmware gaps: subtrack LEDs, MIDI transpose, save-on-stop
    - Populate LedState.subtracks field in get_led_state() based on active screen mode
    (selected subtrack On, others Dim, all Off when not in subtrack edit)
    - Render subtrack LEDs at TLC3 channels 60-71 in leds.rs
    - Add MidiNoteOn/MidiNoteOff variants to ControlEvent
    - Route MIDI note input to live transpose (note relative to C3=60, clamped ±48)
    - Wire MIDI notes from main.rs parser through mode_machine::dispatch
    - Reduce auto-save interval from 30s to 10s for less data loss on reset
    - Save state immediately when transport stops (natural save point)
    - Document reset pulse timing with named constant (RESET_PULSE_CYCLES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
    [clock_io.rs, input.rs, leds.rs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]
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2026-03-07 Fix all clippy warnings in firmware crate
    - Add Default impls for DebounceState, EdgeDetector, CvChannel,
    CvInputs, Framebuffer, QuadratureState, ButtonDebounce, MidiParser
    - Use abs_diff() instead of manual if/else in CvChannel::changed
    - Remove unnecessary u64 cast in cv_output
    - Fix overlapping match arms in MIDI parser (0xF8..=0xFF vs CLOCK)
    - Use enumerate() instead of range indexing in LED track colors
    - Collapse nested if in periodic save
    - Allow too_many_arguments on process_tick
    - Use is_multiple_of() for clock output step boundary check
    - Allow dead_code on EdgeDetector (used in host testing only)
    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
    [clock_io.rs, cv_input.rs, display.rs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]
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2026-03-07 Make cargo test --workspace work by cfg-gating firmware binary
    The firmware binary (main.rs) uses embassy/cortex-m which only compile
    for ARM. Previously cargo test --workspace failed with 42 errors.
    Fix: gate the embedded entry point and imports behind
    cfg(target_os = "none"), with an empty fn main() stub on host.
    Modules that are purely hardware (display, leds, pins) are also
    cfg-gated. storage.rs SdStorage struct gated separately from the
    re-exported STATE_BUF_SIZE constant.
    CI and Makefile restored to simple `cargo test --workspace`.
    All 483 tests pass: 195 engine + 141 firmware lib + 130 firmware
    bin (host stub) + 17 renderer.
    https://claude.ai/code/session_01Jywm9tFQMdnvBBNcm1wBZ3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
    [main.rs, storage.rs]
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2026-03-11 Add 3D assembly viewer with Three.js
    Interactive 3D viewer for the three-board sandwich stack (faceplate +
    control + main), accessible via "3D View" button in the debug menu.
    Features:
    - Three.js scene with orbit controls, zoom, pan
    - Explode slider to separate boards along Z-axis
    - Board visibility toggles
    - Fallback placeholder boxes when glTF models not available
    - Material heuristics: FR4 green PCBs, dark aluminum faceplate,
    metal pins, dark component bodies
    - Dynamic import to avoid impacting initial page load
    Pipeline:
    - export_gltf.py converts STEP → glTF via trimesh+cascadio
    - New Makefile targets: hw-3d-export, hw-export-gltf
    - Python venv for conversion dependencies
    [PGA2350.step, TC002-N11AS1XT-RGB.step]
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2026-03-11 Move SD card slot from back to front of control board
    The MicroSD slot needs to be accessible through the faceplate cutout,
    so it must be on the front layer. Flipped footprint from B.Cu to F.Cu
    in the KiCad PCB and added placement call in place_components.py to
    position it at the faceplate cutout coordinates.
    https://claude.ai/code/session_017d4oTDEiKrwHvNU6zuaWmu
    [control-placed.kicad_pcb]
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2026-03-12 Fix hardware pipeline: SD card position, faceplate holes, 3D assembly stack-up
    - Fix SD card slot placement below PLAY button with component-map fallback
    - Rebuild PJS008U 3D model as hollow card cage, align with faceplate cutout
    - Inset USB-C connector flush with main board edge
    - Add clock jack holes, SD cutout, JetBrains Mono fonts to faceplate
    - Correct 3D assembly Z spacing from actual PJ398SM model measurements
    - Improve explode animation: anchor control board, smoother slider
    [FPC_18P_05MM.step, PGA2350.step, PJS008U.step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]
2026-03-12 Throughhole m3 for stability
    [FPC_18P_05MM.step, PGA2350.step, PJS008U.step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]
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2026-03-13 Refactor hardware pipeline: config-driven scripts, immutable build stages, full 3D export
    - Reorganize scripts/ into build/, common/, placement/, routing/, export/, models/
    - Replace autoroute.sh (389 lines bash) with autoroute.py (pure Python)
    - Extract board-specific values into board-config.json (placement, routing, DRC allowlist)
    - Create hardware/Makefile with file-based dependencies covering full pipeline
    - Immutable pipeline: placed → routed → poured → 3d → step → glb (no in-place mutation)
    - Ground pours now read clearances from design-rules.json
    - DRC allowlisting for known SD card footprint errors
    - 3D pipeline: add_3d_models → export_3d_assembly (STEP) → export_gltf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
    [control-placed.kicad_pcb, faceplate.kicad_pcb, main-placed.kicad_pcb]
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2026-03-14 Parts replaced
    [WQP518MA.step, WQP518MA_hex.step, WQP518MA_hsb.step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]
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2026-03-17 Routing hell.. broken
    [FPC_18P_05MM.step, FPC_32P_05MM.step, PB6149L.step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]
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2026-03-18 Fix firmware
    [control-placed.kicad_pcb, faceplate.step, main-placed.kicad_pcb]
2026-03-18 Fix visuals
    [control-placed.kicad_pcb, faceplate.step, main-placed.kicad_pcb]
2026-03-26 production check command and fixes coming out of that
    [FPC_32P_05MM.step, PB6149L.step, PGA2350.step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]
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

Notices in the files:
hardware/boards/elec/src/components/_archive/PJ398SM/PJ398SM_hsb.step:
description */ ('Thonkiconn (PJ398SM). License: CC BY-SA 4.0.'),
